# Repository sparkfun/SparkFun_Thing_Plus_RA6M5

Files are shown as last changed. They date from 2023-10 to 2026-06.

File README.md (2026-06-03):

SparkFun Thing Plus - RA6M5
========================================

SparkFun Thing Plus - RA6M5 (https://www.sparkfun.com/products/24243)

[*SparkFun Thing Plus - RA6M5 (WRL-24243)*](https://www.sparkfun.com/products/24243)

Clocking in at 200MHz, the RA6M5 is a high-performance microcontroller from [Renesas](https://www.renesas.com/) that is perfect for real-time applications. The [SparkFun Thing Plus - RA6M5](https://www.sparkfun.com/products/24243), is our latest [Thing Plus board](https://www.sparkfun.com/thing_plus) featuring the standard Qwiic connector, JST LiPo battery connector, 21 GPIO pins broken out in a Feather footprint, and status indicator LEDs. At the core is the RA6M5 microcontroller, a low-power Arm^®^ Cortex^®^-M33 processor with an available 512kB of SRAM and 2MB of Flash and an extensive list of peripheral capabilities. Additionally, we have included 16MB of QSPI Flash and an SD card slot on the board, so users won't have to worry about running out of memory space or data storage options.

The SparkFun RA6M5 Thing Plus also features Bluetooth® Low Energy connectivity, thanks to the provided DA14531MOD module *(also from Renesas)*. When actively transmitting, the DA14531MOD sips a mere 4mA and is capable of operating from a small coin-cell battery. The firmware provided on the module features Renesas' [SmartBond™ - CodeLess™ AT command](https://lpccs-docs.renesas.com/UM-140-DA145x-CodeLess/index.html) set. Therefore, users only need to send AT commands to configure a Bluetooth connection; without the need to reprogram the module.

**Note:**

- While the Thing Plus - RA6M5 does include some 5V tolerant pins, it is primarily a **3.3V** *logic-level* board.
- While the full capabilities of the RA6M5 support a broad range of features, only a limited set may be implemented, by default, in the [Renesas-Arduino core](https://github.com/arduino/ArduinoCore-renesas). However, the capabilities of the Thing Plus - RA6M5 should be comparable to the [Arduino Portenta C33](https://store.arduino.cc/collections/portenta-family/products/portenta-c33); with the exclusion of WiFi connectivity.

Documentation
--------------

* **[Hookup Guide (mkdocs)](http://docs.sparkfun.com/SparkFun_Thing_Plus_RA6M5/)** - The hookup guide for the Thing Plus - RA6M5 hosted by GitHub pages.<br>
   
* [SparkFun Graphical Datasheets](https://github.com/sparkfun/Graphical_Datasheets) - Graphical Datasheets for various SparkFun products.

*Need to download or print our hookup guide?*

* [Print *(Print to PDF)* from Single-Page View](http://docs.sparkfun.com/SparkFun_Thing_Plus_RA6M5/print_view)

Repository Contents
-------------------

* **[/docs](/docs/)** - Online documentation files
    * [assets](/docs/assets/) - Assets files
        * [board_files](/docs/assets/board_files/) - Files for the product design
            * [Eagle design files](/docs/assets/board_files/eagle_files.zip) (.zip)
            * [Schematic](/docs/assets/board_files/schematic.pdf) (.pdf)
            * [Dimensions](/docs/assets/board_files/dimensions.pdf) (.pdf)
            * [Graphical Datasheet](/docs/assets/board_files/graphical_datasheet.pdf) (.pdf)
        * [component_documentation](/docs/assets/component_documentation/) - Datasheets for hardware components
        * [img/hookup_guide/](/docs/assets/img/hookup_guide/) - Images for hookup guide documentation
* **[/Hardware](/Hardware/)** - Eagle design files (.brd, .sch)
  * **[/Production](/Production/)** - Production files

Product Variants
----------------

* [WRL-24243](https://www.sparkfun.com/products/24243)- v1.0, Initial Release

Version History
---------------

* [v10](https://github.com/sparkfun/SparkFun_Thing_Plus_RA6M5/releases/tag/v10) - Initial Release

License Information
-------------------

This product is ***open source***!

Please review the [`LICENSE.md`](./LICENSE.md) file for license information.

If you have any questions or concerns about licensing, please contact technical support on our [SparkFun forums](https://forum.sparkfun.com/viewforum.php?f=152).

Distributed as-is; no warranty is given.

- Your friends at SparkFun.

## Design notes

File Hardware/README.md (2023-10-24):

SparkFun <PRODUCT NAME> Design Files
=====================================

The .sch and .brd files hare are Eagle CAD schematic and PCB design files from SparkFun Electronics.
A freeware version of Autodesk Eagle can be found [here](https://www.autodesk.com/products/eagle/free-download).

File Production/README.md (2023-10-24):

SparkFun <PRODUCT NAME> Production Files
=========================================

These are the production files SparkFun uses for printing PCBs.

License Information
-------------------
This product is open source! 

The hardware is released under [Creative Commons ShareAlike 4.0 International](https://creativecommons.org/licenses/by-sa/4.0/).

Please use, reuse, and modify these files as you see fit. Please maintain attribution to SparkFun Electronics and release anything derivative under the same license.

Distributed as-is; no warranty is given.

- Your friends at SparkFun.

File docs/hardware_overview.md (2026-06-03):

---
icon: material/cog
---

## Dimensions

The circuit board dimensions are illustrated in the drawing below; the measurements are in inches.

<figure markdown>
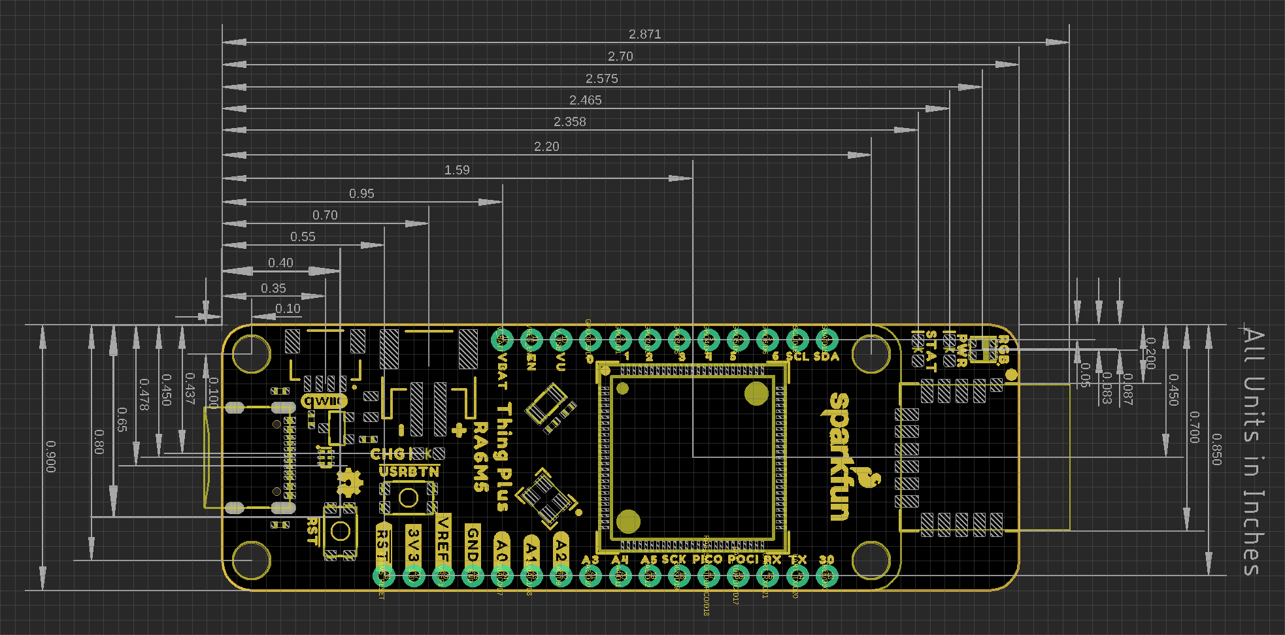
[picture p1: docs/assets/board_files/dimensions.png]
Board Dimensions

<figcaption markdown>
[Dimensions (PDF)](./assets/board_files/dimensions.pdf) of the RA6M5 Thing Plus, in inches.
</figcaption>
</figure>

??? tip "Need more measurements?"
	For more information about the board's dimensions, users can download the [**Eagle files**](./assets/board_files/eagle_files.zip) for the board. These files can be opened in Eagle and additional measurements can be made with the dimensions tool.

	??? info ":octicons-download-16:{ .heart } Eagle - Free Download!"
		Eagle is a [CAD]("computer-aided design") program for electronics that is free to use for hobbyists and students. However, it does require an account registration to utilize the software.

		<article style="text-align: center;" markdown>
		[Download from<br>:autodesk-primary:{ .autodesk }](https://www.autodesk.com/products/eagle/free-download "Go to downloads page"){ .md-button .md-button--primary width="200px" }
		</article>

	??? info ":straight_ruler: Dimensions Tool"
		This video from Autodesk demonstrates how to utilize the dimensions tool in Eagle, to include additional measurements:

		<article style="text-align: center;" markdown>

		<div class="video">
		<iframe src="https://www.youtube.com/embed/dZLNd1FtNB8" title="EAGLE Dimension Tool" frameborder="0" allow="accelerometer; autoplay; clipboard-write; encrypted-media; gyroscope; picture-in-picture" allowfullscreen></iframe>

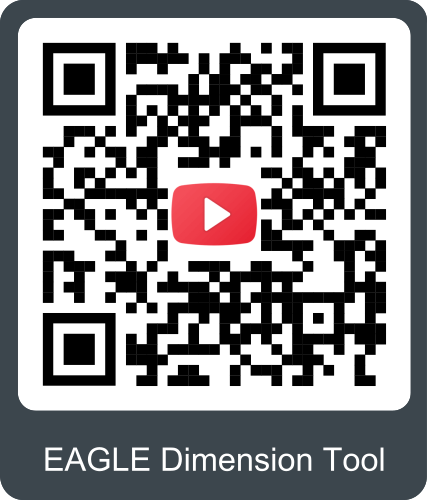
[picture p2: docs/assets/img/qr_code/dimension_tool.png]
QR code to instructional video
		
		</div>

		</article>

## USB Connector
The USB-C connector is used to provide power and program the board. For most users, it will also be the primary programming interface for the RA6M5 Thing Plus.

<figure markdown>
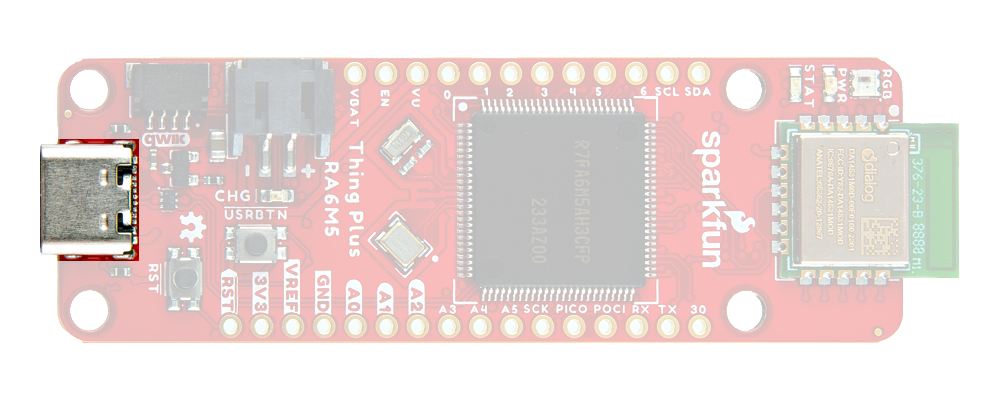
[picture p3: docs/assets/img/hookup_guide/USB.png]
USB-C Connectors

<figcaption markdown>USB-C connector on the RA6M5 Thing Plus.</figcaption>
</figure>

## Power
The RA6M5 Thing Plus only requires **3.3V** to power the board. However, the simplest method to power the board is through the USB-C connector. Alternatively, the `3V3`, `VBAT`, and `VUSB` pins can also be used to supply power to the board.

<div class="grid cards desc" markdown>

<div markdown>

<figure markdown>
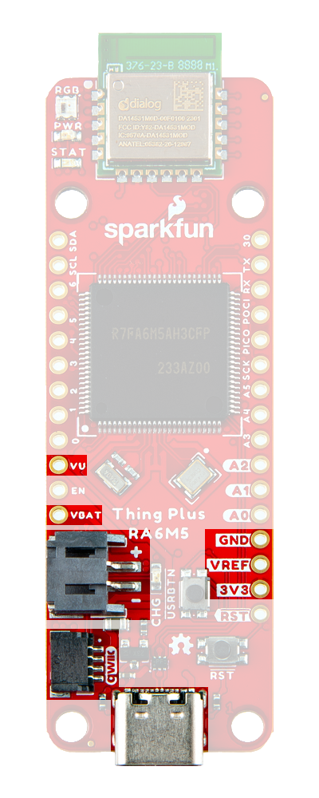
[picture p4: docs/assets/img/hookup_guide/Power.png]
Power connections

<figcaption markdown>Power connections on the RA6M5 Thing Plus PCB.</figcaption>
</figure>

</div>

<div markdown>

<article style="text-align: center;" markdown>

```mermaid

flowchart LR
	A[USB-C] === B(("`**VUSB**`")) ===> |VUSB > VBAT| Switch;

	subgraph Battery Charger
		direction LR
		C[MCP73831] -.-> D[LiPo Battery];
	end

	subgraph Switch
		F[LM66200];
	end

	B ==> C;
	D === E(("`**VBAT**`")) == VBAT > VUSB ==> Switch;

	F ===	H[RT9080] ==> I(("`**3V3**`"));
	F === G[RT9080] ==> J(("`**VREF**`"));

	click B "#vusb"
	click C "#charging-circuit"
	click E "#vbat"
	click F "#power-control"
	click J "#vref"
	click I "#3v3"
```

</article>

Below, is a summary of the power circuitry for this board:

=== ":material-power: `3V3`"
	* Primary power for the RA6M5 Thing Plus
		* Powers the RA6M5 module, DA14531MOD, QSPI flash, &micro;SD card slot, Qwiic connector, WS2812 RGB LED, and power LED
	* A regulated **3.3V** is provided by an [RT9080](./assets/component_documentation/RT9080.pdf) LDO from `VUSB` or `VBAT`
		* The output voltage from the RT9080 is controlled by the `EN` pin on the board
		* The RT9080 can source up to **600mA** of current, which is only limited by the power source from the LM66200 switch
			* The power source from the LM66200 is automatically switched between `VUSB` or `VBAT`, based on which has the greater voltage
	* As an input, it requires a **regulated 3.3V** to avoid contention with the LDO regulator

	!!! info "<span style="font-weight: 400;">The input voltage range for the RT9080 is 1.2-5.5V</span>"

=== ":material-usb-port: `VUSB`"
	* Usually powered through the USB-C connector *(**5V**)*
	* Input voltage range: **3.75 - 5V**
		* The maximum voltage is limited by the ideal diode switch at **5.5V** *(1.6-5.5V)*
		* The minimum voltage is limited by the charge controller at **3.75V** *(3.75-6V)*
	* Primary power source for the [RT9080 LDOs](./assets/component_documentation/RT9080.pdf) when `VUSB` > `VBAT`; via the LM66200 ideal diode switch
	* Powers the [MCP73831](./assets/component_documentation/MCP73831.pdf) linear charge management controller
		* Provides a **213mA** *(max)* rate of charge to a connected battery
=== ":material-battery-charging: `VBAT`"
	* The voltage from the JST battery connector; is meant for single-cell LiPo batteries
		* A connected battery will be charged by the [MCP73831 charge controller](./assets/component_documentation/MCP73831.pdf), when sufficient power is provided from `VUSB`
	* Primary power source for the  [RT9080 LDOs](./assets/component_documentation/RT9080.pdf) when `VBAT` > `VUSB`; via the LM66200 ideal diode switch
	* A battery's charge can be monitored through the [MAX17048](./assets/component_documentation/MAX17048.pdf) fuel gauge
=== ":material-sine-wave: :material-gauge: `VREF`"
	* The analog reference voltage for the RA6M5 module's ADC and DAC channels
		* Provided by a [RT9080](./assets/component_documentation/RT9080.pdf) LDO regulator, separate from one providing the `3V3` power supply

	!!! info "<span style="font-weight: 400;">The input voltage range for the RT9080 is 1.2-5.5V</span>"

=== ":material-format-line-style: `GND`"
	* The common ground or the 0V reference for the voltage supplies
=== ":material-connection: Qwiic Connector"
	* The 4-pin JST connector provides a regulated 3.3V voltage to peripheral Qwiic devices from `3V3`

</div>

</div>

??? info "Detailed Diagram"

	<article style="text-align: center;" markdown>
	
	```mermaid
	
	flowchart LR
		D === E(("`**VBAT**`")) == VBAT > VUSB ==> Switch;
		A[USB-C] === B(("`**VUSB**`")) == VUSB > VBAT ==> Switch;
		C --- T[CHG LED];
	
	subgraph Battery Charger
			C[MCP73831] -.-> D[LiPo<br>3.5-4.2V]
		end
	
		subgraph Switch
			S[LM66200];
			S === I[RT9080] & H[RT9080];
		end
	
		subgraph Powered_Components
			L[PWR LED];
			M[RA6M5] --- N[DA14531MOD];
			M --- O[QSPI Flash];
			M --- P[SD Card];
			M --- Q[WS2812 LED];
			M --- I2C;
			subgraph I2C
				R[Qwiic Connector];
				F[MAX17048];
			end
		end
	
		B ==> C;
		B ====> T;
		I --- U(("`**EN**`"));
		I ==> K(("`**3V3**`")) === Powered_Components;
		H ==> J(("`**VREF**`")) --> M;
		H --- W(("`**D37**`")) --- M;
		D ------ F;
		Switch --- V(("`**D38**`")) --- M;
	```

	</article>

*For more details, users can reference the [schematic](./assets/board_files/schematic.pdf) and the datasheets of the individual components in the power circuitry.*

### Power Status&nbsp; LED
The red, `PWR` LED will light up once **3.3V** is supplied to the board; however, for most users, it will light up when **5V** is supplied through the USB connection or when a LiPo battery is connected to the JST connector.

<figure markdown>
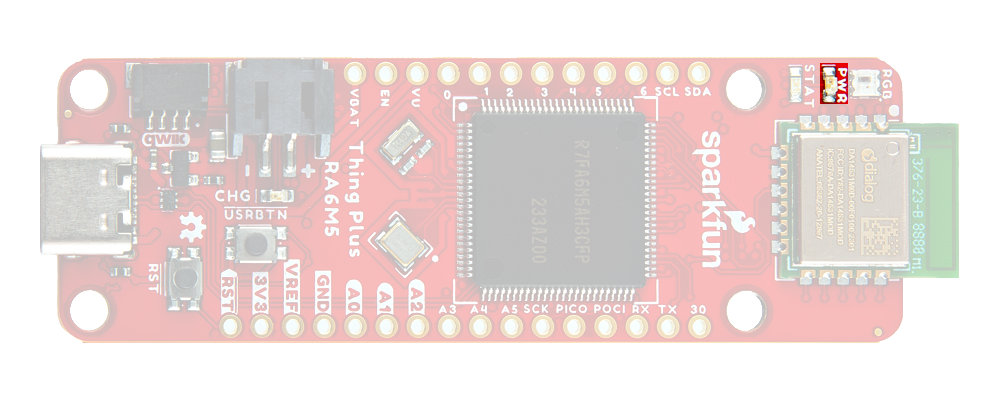
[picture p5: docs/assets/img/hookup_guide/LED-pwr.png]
Power LED

<figcaption markdown>The `PWR` status LED indicator on the RA6M5 Thing Plus.</figcaption>
</figure>

### Charging Circuit
The charging circuit utilizes the [MCP73831 linear charge management controller](./assets/component_documentation/MCP73831.pdf) from [Microchip Technologies](https://www.microchip.com/), which is powered by the USB-C connector or `VUSB`. The controller provides a **213mA** charge rate for a LiPo battery connected to the JST connector. Active charging is indicated by the yellow, `CHG` LED. If the charge controller is shut down or charging is complete, the `CHG` LED will turn off. The board also includes a [MAX17048 fuel gauge](./assets/component_documentation/MAX17048.pdf) from [Analog Devices](https://www.analog.com/) to monitor the charge left on the battery.

<article style="text-align: center;" markdown>

```mermaid

flowchart LR
	A[USB-C] === B(("`**VUSB**`")) ==> C & G;
	D ===> E(("`**VBAT**`"));
	D --- F[MAX17048] === H(("`**3V3**`"));
	G[CHG LED] --- C[MCP73831];

	subgraph Battery Charger
		C -.-> |213mA| D[LiPo<br>3.5-4.2V];
	end
```

</article>

<figure markdown>
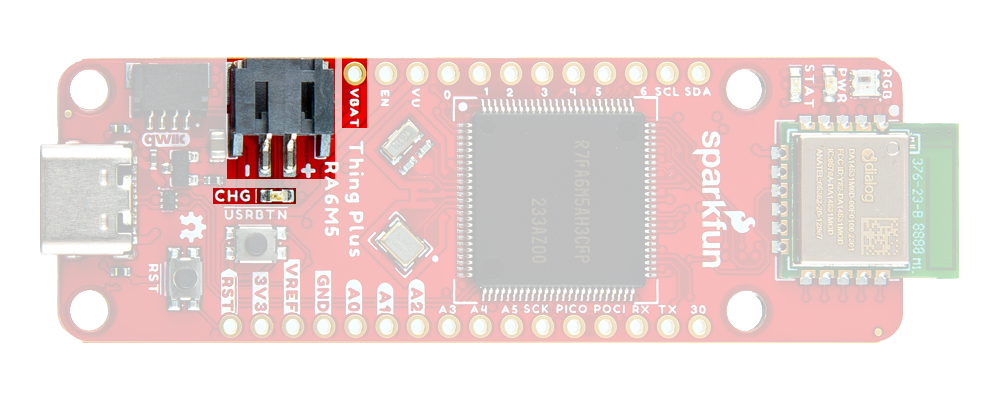
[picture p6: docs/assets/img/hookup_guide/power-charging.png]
Battery connection and charge indicator

<figcaption markdown>The `CHG` status LED and JST connector for the battery on the RA6M5 Thing Plus.</figcaption>
</figure>

*For more details, please refer to the [MCP73831](./assets/component_documentation/MCP73831.pdf) and [MAX17048](./assets/component_documentation/MAX17048.pdf) datasheets, [schematic](./assets/board_files/schematic.pdf), and the [**Status LEDs**](#status-leds) and [**Battery Fuel Gauge**](#battery-fuel-gauge) sections below.*

### Power Control
The primary power source for the [RT9080 LDO regulators](./assets/component_documentation/RT9080.pdf) is automatically switched between `VUSB` and `VBAT` by the [LM66200 ideal diode switch](./assets/component_documentation/LM66200.pdf); based on their voltage levels. This will be indicated by the `ST` pin of the LM66200, which is connected to the `P001` GPIO *(`D38`)* of the RA6M5. A **`LOW`** state will indicate that power is being supplied from `VUSB` *(or the USB-C connector)*; while a **`HIGH`** state will indicate power is being drawn from `VBAT` *(or the battery JST connector)*.

<article style="text-align: center;" markdown>

```mermaid

flowchart LR
	A[USB-C] === B(("`**VUSB**`")) == VUSB > VBAT ==> Switch;
	U(("`**D38**`")) --- Switch;
	D[LiPo] === E(("`**VBAT**`")) == VBAT > VUSB ==> Switch;

	subgraph Switch
		S[LM66200];
	end

	S === H[RT9080] ===> J(("`**3V3**`"));
	H --- T(("`**EN**`"));
	I --- V(("`**D37**`"));
	S === I[RT9080] ===> K(("`**VREF**`"));
```

</article>

The **3.3V** regulated output from the primary RT9080 is enabled by default and controlled by the `EN` pin on the board. Meanwhile, the voltage output from the RT9080 for the analog reference voltage *(`VREF`)* of the RA6M5 is controlled by its `P500` GPIO *(`D37`)*. Users can disable the 3.3V power output of either of the RT9080 LDO regulators, by setting the associated control pin **LOW**.

<figure markdown>
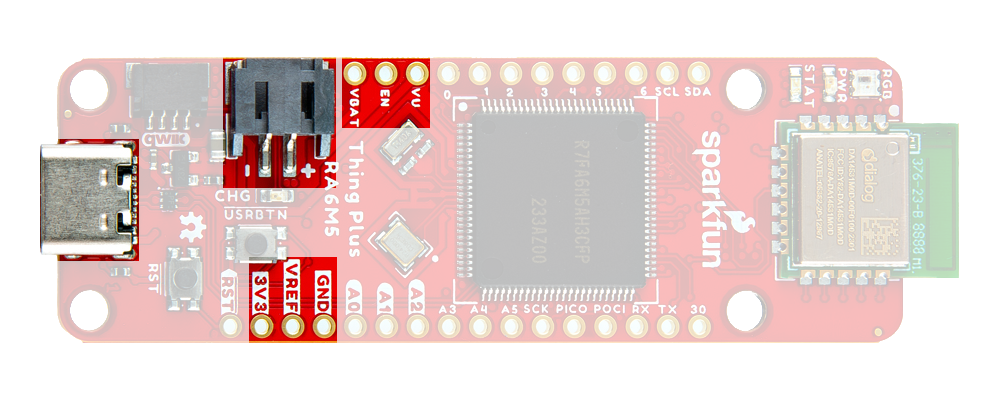
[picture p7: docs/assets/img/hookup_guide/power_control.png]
Power control

<figcaption markdown>The power inputs/outputs and `EN` pin on the RA6M5 Thing Plus.</figcaption>
</figure>

*For more details, please refer to the [LM66200 datasheet](./assets/component_documentation/LM66200.pdf), [RT9080 datasheet](./assets/component_documentation/RT9080.pdf), and [schematic](./assets/board_files/schematic.pdf).*

<!-- Incomplete data
### Current Consumption
According to the specifications, the RA6M5 draws about **### mA** on average. With the BLE example in this tutorial, have measured it to average around **### mA** and peak at *### mA* while active. The table below summarizes the approximate current draw of the [RA6M5 Thing Plus](https://www.sparkfun.com/products/24243) for various cases and conditions. *(All current measurements were profiled with the [Nordic Power Profiler Kit II](https://www.nordicsemi.com/Products/Development-hardware/Power-Profiler-Kit-2).)*

<table style="text-align: center;" markdown>
<tbody>
	<tr>
		<th rowspan="2" style="vertical-align:middle; text-align:center">Operation</th>
		<th colspan="4" style="text-align:center">Avg. Current Draw</th>
	</tr>
	<tr>
		<td style="text-align:center">
			LiPo: <b>3.5V</b><br>
			<i>(Low < 5%)</i>
		</td>
		<td style="text-align:center">
			LiPo: <b>3.7V</b><br>
			<i>(~15%)</i>
		</td>
		<td style="text-align:center">
			LiPo: <b>4.2V</b><br>
			<i>(~100%)</i>
		</td>
		<td style="text-align:center; vertical-align:middle">
			USB-C: <b>5V</b><br>
			<i>(No Battery)</i>
		</td>
	</tr>
	<tr>
		<th style="vertical-align:middle">Idle (Blank Code)</th>
		<td style="vertical-align:middle; text-align:center;">
			63 mA<br>
			<i>86 mA (peak)</i>
		</td>
		<td style="vertical-align:middle; text-align:center;">
			63.5 mA<br>
			<i>89 mA (peak)</i>
		</td>
		<td style="vertical-align:middle; text-align:center;">
			64 mA<br>
			<i>88.6 mA (peak)</i>
		</td>
		<td style="vertical-align:middle; text-align:center;">
			67 mA<br>
			<i>89.9 mA (peak)</i>
		</td>
	</tr>
	<tr>
		<th style="vertical-align:middle">Idle: USB + Battery Power</th>
		<td style="vertical-align:middle; text-align:center;">
			--
		</td>
		<td style="vertical-align:middle; text-align:center;">
			--
		</td>
		<td style="vertical-align:middle; text-align:center;">
			90.5 &micro;A<br>
			<i>721 &micro;A (peak)</i>
		</td>
		<td style="vertical-align:middle; text-align:center;">
			N/A
		</td>
	</tr>
	<tr>
		<th style="vertical-align:middle">
			Idle: Battery Charging<br>
			<i>(Current from USB-C)</i>
		</th>
		<td style="vertical-align:middle; text-align:center;">
			395 mA<br>
			<i>420 mA (peak)</i>
		</td>
		<td style="vertical-align:middle; text-align:center;">
			590 mA<br>
			<i>600 mA (peak)</i>
		</td>
		<td style="vertical-align:middle; text-align:center;">
			&gt; 110 mA<br>
			<i>(before shutdown)</i>
		</td>
		<td style="vertical-align:middle; text-align:center;">
			N/A
		</td>
	</tr>
	<tr>
		<th style="vertical-align:middle">RGB <i>(White @ 100%)</i></th>
		<td style="vertical-align:middle; text-align:center;">
			78.4 mA<br>
			<i>105.9 mA (peak)</i>
		</td>
		<td style="vertical-align:middle; text-align:center;">
			79 mA<br>
			<i>106.8 mA (peak)</i>
		</td>
		<td style="vertical-align:middle; text-align:center;">
			79.9 mA<br>
			<i>105.3 mA (peak)</i>
		</td>
		<td style="vertical-align:middle; text-align:center;">
			82.5 mA<br>
			<i>108.2 mA (peak)</i>
		</td>
	</tr>
	<tr>
		<th style="vertical-align:middle">
			WiFi Example<br>
			<i>(Transceiving)</i>
		</th>
		<td style="vertical-align:middle; text-align:center;">
			135 mA<br>
			<i>295 mA (peak)</i>
		</td>
		<td style="vertical-align:middle; text-align:center;">
			137 mA<br>
			<i>310 mA (peak)</i>
		</td>
		<td style="vertical-align:middle; text-align:center;">
			137 mA<br>
			<i>307 mA (peak)</i>
		</td>
		<td style="vertical-align:middle; text-align:center;">
			140 mA<br>
			<i>300 mA (peak)</i>
		</td>
	</tr>
	<tr>
		<th style="vertical-align:middle">
			<a href="https://github.com/espressif/arduino-esp32/blob/master/libraries/ESP32/examples/DeepSleep/TouchWakeUp/TouchWakeUp.ino">Deep Sleep Example</a><br>
			<i>(MCU Inactive)</i>
		</th>
		<td style="vertical-align:middle; text-align:center;">
			2.5 mA<br>
			<i>2.95 mA (peak)</i>
		</td>
		<td style="vertical-align:middle; text-align:center;">
			2.5 mA<br>
			<i>3 mA (peak)</i>
		</td>
		<td style="vertical-align:middle; text-align:center;">
			2.55 mA<br>
			<i>3 mA (peak)</i>
		</td>
		<td style="vertical-align:middle; text-align:center;">
			2.85 mA<br>
			<i>3.3 mA (peak)</i>
		</td>
	</tr>
	<tr>
		<th style="vertical-align:middle">
			<a href="https://github.com/espressif/arduino-esp32/blob/master/libraries/ESP32/examples/DeepSleep/TouchWakeUp/TouchWakeUp.ino">Deep Sleep Example</a><br>
			<i>(MCU Inactive + Jumpers Cut)</i>
		</th>
		<td style="vertical-align:middle; text-align:center;">
			842 &micro;A<br>
			<i>1.24 mA (peak)</i>
		</td>
		<td style="vertical-align:middle; text-align:center;">
			848 &micro;A<br>
			<i>1.23 mA (peak)</i>
		</td>
		<td style="vertical-align:middle; text-align:center;">
			866 &micro;A<br>
			<i>1.24 mA (peak)</i>
		</td>
		<td style="vertical-align:middle; text-align:center;">
			1.19 mA<br>
			<i>1.58 mA (peak)</i>
		</td>
	</tr>
</tbody>
</table>

It is possible for users to reach sub-mA power consumption levels with the deep sleep power modes. Using the [`TimerWakeUp` Deep Sleep example code](https://github.com/espressif/arduino-esp32/blob/master/libraries/ESP32/examples/DeepSleep/TimerWakeUp/TimerWakeUp.ino), the LED jumpers cut, and powering the board through the LiPo battery connection we measured a power consumption of **845 &micro;A** *(990 &micro;A peak)* @ **3.7V** while the MCU was inactive.

<figure markdown>
[![Deep Sleep Power Consumption Profile](./assets/img/hookup_guide/measurement-ulp-from_batt.png){ width="400" }](./assets/img/hookup_guide/measurement-ulp-from_batt.png "Click to enlarge")
<figcaption markdown>The current measurement from `VBAT` at **3.7V** during deep sleep.</figcaption>
</figure>

 -->

## :fontawesome-solid-microchip:&nbsp;RA6M5 Microcontroller
The brains of the board is the [RA6M5 microcontroller](https://www.renesas.com/us/en/document/dst/ra6m5-group-datasheet?r=1493931) from [Renesas](https://www.renesas.com/), a low-power Arm^®^ Cortex^®^-M33 processor with a clock speed up to 200Mhz, 512kB of SRAM, and 2MB of flash memory. This high-performance microcontroller features an extensive list of peripheral capabilities and is perfect for real-time applications.

<div class="grid cards col-3" markdown>

<div markdown>

<figure markdown>
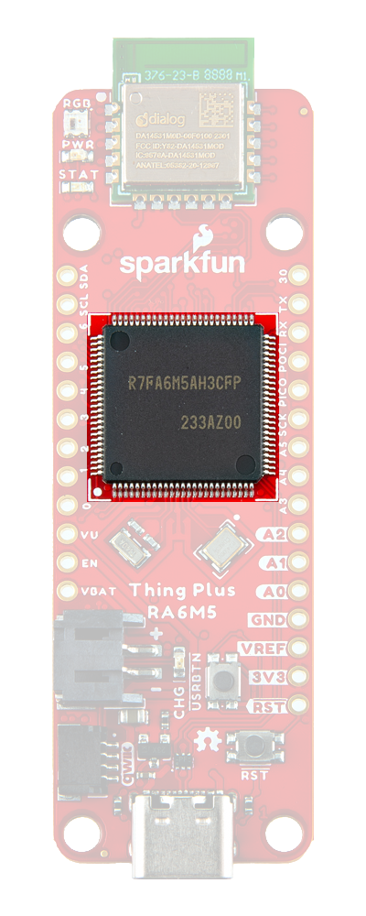
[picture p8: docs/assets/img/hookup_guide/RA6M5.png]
RA6M5 Microcontroller

<figcaption markdown>The RA6M5 microcontroller on the RA6M5 Thing Plus.</figcaption>
</figure>

</div>

<div markdown>

* Arm^®^ Cortex^®^-M33 Core
	* Clock Frequency: 200MHz
	* Flash Memory: 2MB *(code)*; 8kB *(data)*
	* SRAM: 512kB w/ ECC Support
	* Arm Memory Protection Unit (Arm MPU)
	* Secure Crypto Engine
	* Two Watchdog Timers (WDT)
* Operating Voltage: 3.0V to 3.6V
	* Current Consumption:
		* Maximum: 143mA
		* Normal: 32mA
		* Sleep: 11mA
		* Deep Sleep: 0.9-131&micro;A
* Operating modes:
	* Single-chip or SCI/USB boot
* Operating Temperature: -40 to 85 &deg;C
* 75 GPIO Pins
* RTC with Calendar
* CRC Calculator
* Internal Temperature Sensor

</div>

<div markdown>

**Peripherals**

* 12-bit ADC (x6)
* 12-bit DAC (x2)
* 32-bit PWM Channels (x4)
* 16-bit PWM Channels (x6)
* UART (x10)
* I^2^C Bus (x3)
* SPI Bus (x2)
* QSPI (x1)
* SD/MMC Host Interface

{--

* OSPI (x1)
* CAN Interface
* USB 2.0 (Full/High Speed)
* Ethernet MAC/DMA Controller
* Serial Sound Interface Enhanced
* Consumer Electronics Control
* Capacitive Touch Sensing

--}

!!! warning "Note"
	Users should be aware that not all of the features, listed above, will be available in the Arduino IDE.

</div>

</div>

??? success "DFU Mode"
	If users are having issues uploading code to the board, the RA6M5 can be manually forced into DFU mode. This issue, often occurs when the USB connection is busy and a reset can't be triggered on the RA6M5, to initialize the upload process. To force the RA6M5 Thing Plus into DFU mode:

	1. Double-tap the ++"RST"++ button
		- The `STAT` LED should be fading in/out very slowly
	1. Users should now, be able to upload a new program
		- It shouldn't be necessary to select a COM port in the Arduino IDE; only the board needs to be selected
	1. Once programming is complete, the MCU should reboot on its own. Otherwise:
		- Press the ++"RST"++ button
		- Power cycle the board

*For more technical specifications for the RA6M5 microcontroller, please refer to the [RA6M5 datasheet](https://www.renesas.com/us/en/document/dst/ra6m5-group-datasheet?r=1493931) and [RA6M5 user manual](https://www.renesas.com/us/en/document/man/ra6m5-group-users-manual-hardware?r=1493931).*

### Debugging Pins
Debug pins are available for the RA6M5, as 0.1" test points on the board. However, the debugging feature is only available through the [Renesas FSP](https://www.renesas.com/us/en/software-tool/flexible-software-package-fsp) *(not covered in this tutorial)*.

<div class="grid" markdown>

<div markdown>

=== "SWD"
	<!--
    <table border="1" style="text-align: center;" markdown>
        <tr markdown>
            <td style="text-align:center" markdown>---</td>
        </tr>
        <tr markdown>
            <td style="text-align:center" markdown>**3.3V**</td>
            <td style="text-align:center" markdown>**SWDIO**</td>
        </tr>
        <tr markdown>
            <td style="text-align:center" markdown>**SWCLK**</td>
            <td style="text-align:center" markdown>**SWO**</td>
        </tr>
        <tr markdown>
            <td style="text-align:center" markdown>**GND**</td>
            <td style="text-align:center" markdown>**RST**</td>
        </tr>
    </table>
	-->

    <table border="1" style="text-align: center;" markdown>
        <tr markdown>
            <td style="text-align:center" markdown>**GND**</td>
            <td style="text-align:center" markdown>**SWCLK**</td>
            <td style="text-align:center" markdown>**3.3V**</td>
            <td style="text-align:center" markdown>**|**</td>
        </tr>
        <tr markdown>
            <td style="text-align:center" markdown>**RST**</td>
            <td style="text-align:center" markdown>**SWO**</td>
            <td style="text-align:center" markdown>**SWDIO**</td>
        </tr>
    </table>

=== "JTAG"
	<!--
    <table border="1" style="text-align: center;" markdown>
        <tr markdown>
            <td style="text-align:center" markdown>---</td>
        </tr>
        <tr markdown>
            <td style="text-align:center" markdown>**3.3V**</td>
            <td style="text-align:center" markdown>**TMS**</td>
        </tr>
        <tr markdown>
            <td style="text-align:center" markdown>**TCK**</td>
            <td style="text-align:center" markdown>**TDO**</td>
        </tr>
        <tr markdown>
            <td style="text-align:center" markdown>**GND**</td>
            <td style="text-align:center" markdown>**RST**</td>
        </tr>
    </table>
	-->

    <table border="1" style="text-align: center;" markdown>
        <tr markdown>
            <td style="text-align:center" markdown>**GND**</td>
            <td style="text-align:center" markdown>**TCK**</td>
            <td style="text-align:center" markdown>**3.3V**</td>
            <td style="text-align:center" markdown>**|**</td>
        </tr>
        <tr markdown>
            <td style="text-align:center" markdown>**RST**</td>
            <td style="text-align:center" markdown>**TDO**</td>
            <td style="text-align:center" markdown>**TMS**</td>
        </tr>
    </table>

!!! info "Pin Connections"
	In case users are interested, these are the pin connections of the debugging test points for the RA6M5. For more details, please reference the [schematic](./assets/board_files/schematic.pdf) and [**Eagle files**](./assets/board_files/eagle_files.zip).

	- `TMS`/`SWDIO`: `P108`
	- `TCK`/`SWCLK`: `P300`
	- `TDO`/`SWO`: `P109`
	- {--`TDI`: `P110` (POCI/`D17`)--} ***(Not a JTAG test point)***

!!! note
	In order to debug the RA6M5, users will need a debug probe. We recommend the [J-Link debug probes from Segger](https://www.segger.com/products/debug-probes/j-link/). However, users should verify the supported devices before purchasing these products; for example, we had a few issues with the [J-Link EDU Mini](https://www.sparkfun.com/products/24078).

</div>

<div markdown>

<figure markdown>
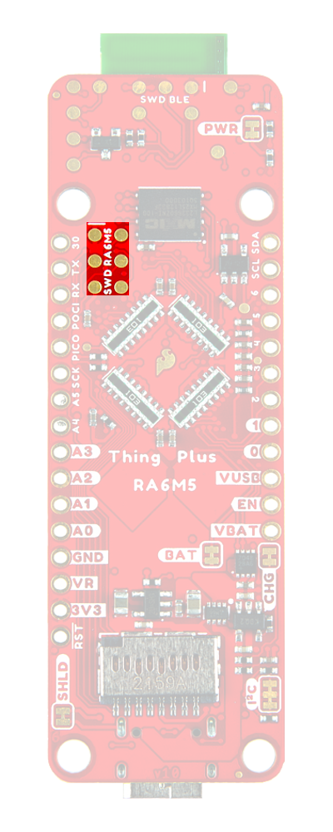
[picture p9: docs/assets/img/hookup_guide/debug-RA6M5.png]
RA6M5 Debug Pins

<figcaption markdown>The debug pins for the RA6M5 microcontroller.</figcaption>
</figure>

</div>

</div>

*For more details, please refer to the [schematic](./assets/board_files/schematic.pdf) and [RA6M5 datasheet](https://www.renesas.com/us/en/document/dst/ra6m5-group-datasheet?r=1493931).*

### Pin Functions
While there are **75 GPIO pins** that are available on the RA6M5, only **44 GPIO pins are utilized** with the RA6M5 Thing Plus. Additionally, of those 44 GPIO, only **21 GPIO pins** are broken out into the PTH breakout pins. The breakout pins are in a Feather form-factor layout with a 0.1" pitch spacing to make them compatible with [standard headers](https://www.sparkfun.com/categories/381) and [Feather shields/*wings*](https://www.sparkfun.com/categories/tags/feather).

Some of the RA6M5's peripheral capabilities may be inaccessible to users with the **available 44 GPIO**. However, any of the available GPIO pins can operate as **digital I/O**; with several of these pins featuring additional peripheral support. The pins utilized by the RA6M5 Thing Plus, along with their capabilities, are summarized in our [graphical datasheet](./assets/board_files/graphical_datasheet.pdf) and detailed in the sections below.

<article style="text-align: center;" markdown>
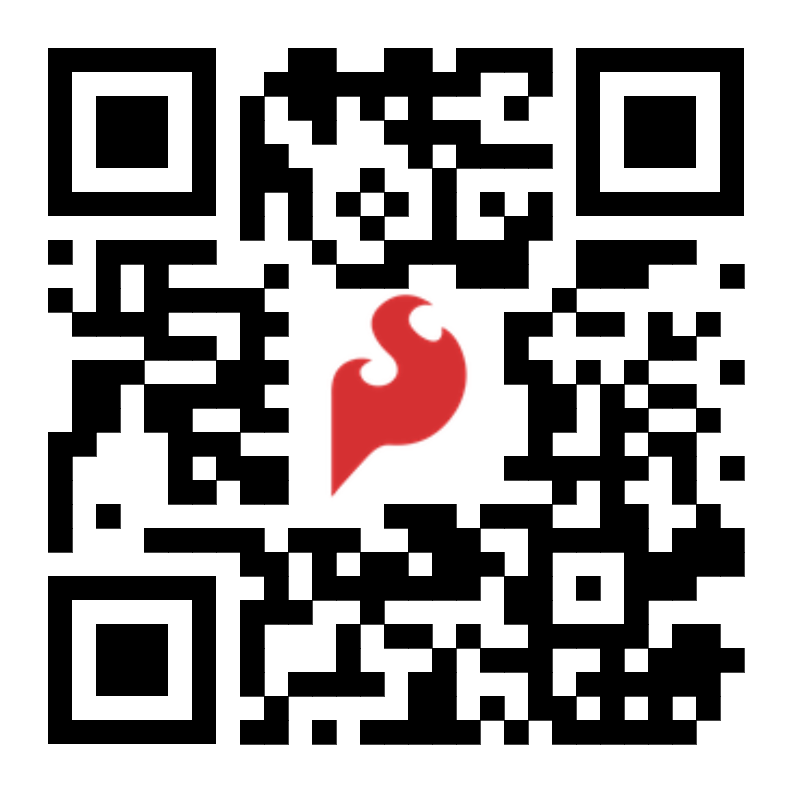
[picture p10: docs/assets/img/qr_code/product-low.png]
QR code to product page
[:material-download:{ .heart }&nbsp;&nbsp;Download the Graphical Datasheet<br>](./assets/board_files/graphical_datasheet.pdf "Click to download the graphical datasheet"){ .md-button .md-button--primary }
</article>

<div class="grid" markdown>

<div markdown>

<figure markdown>
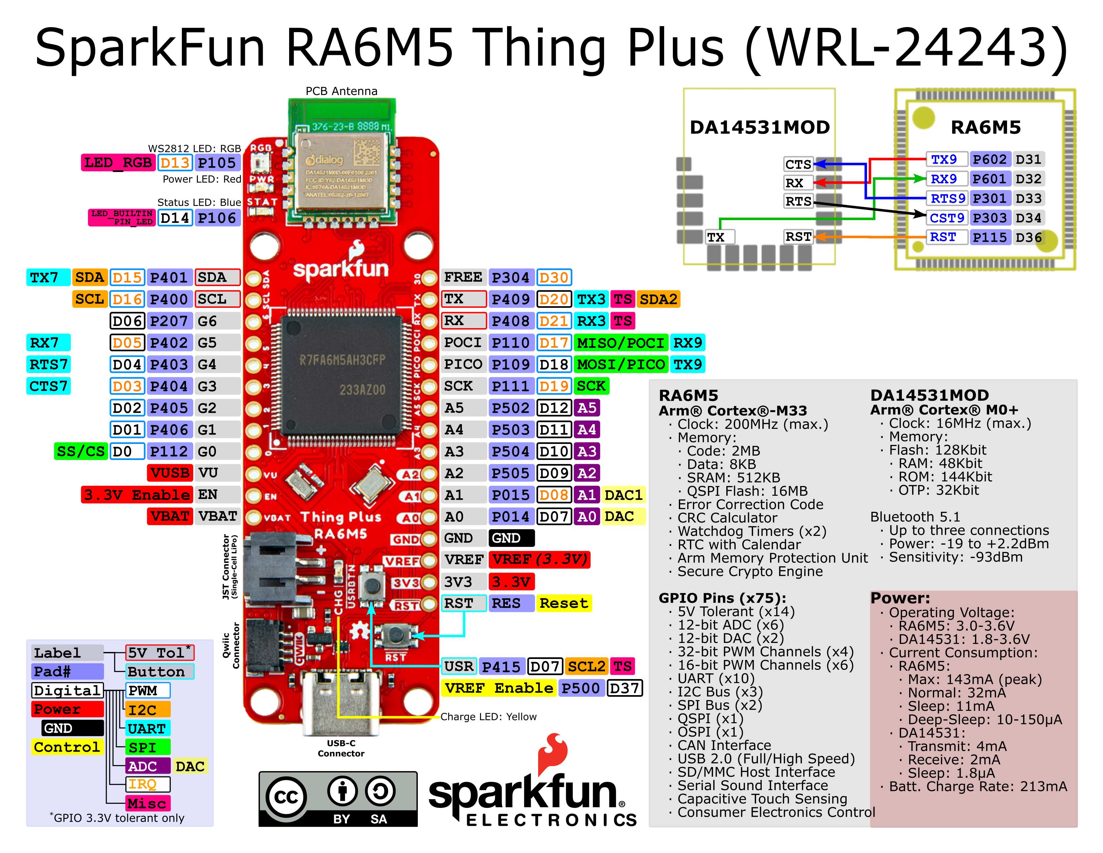
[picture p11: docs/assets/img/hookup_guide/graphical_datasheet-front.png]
Graphical datasheet

</figure>

</div>

<div markdown>

<figure markdown>
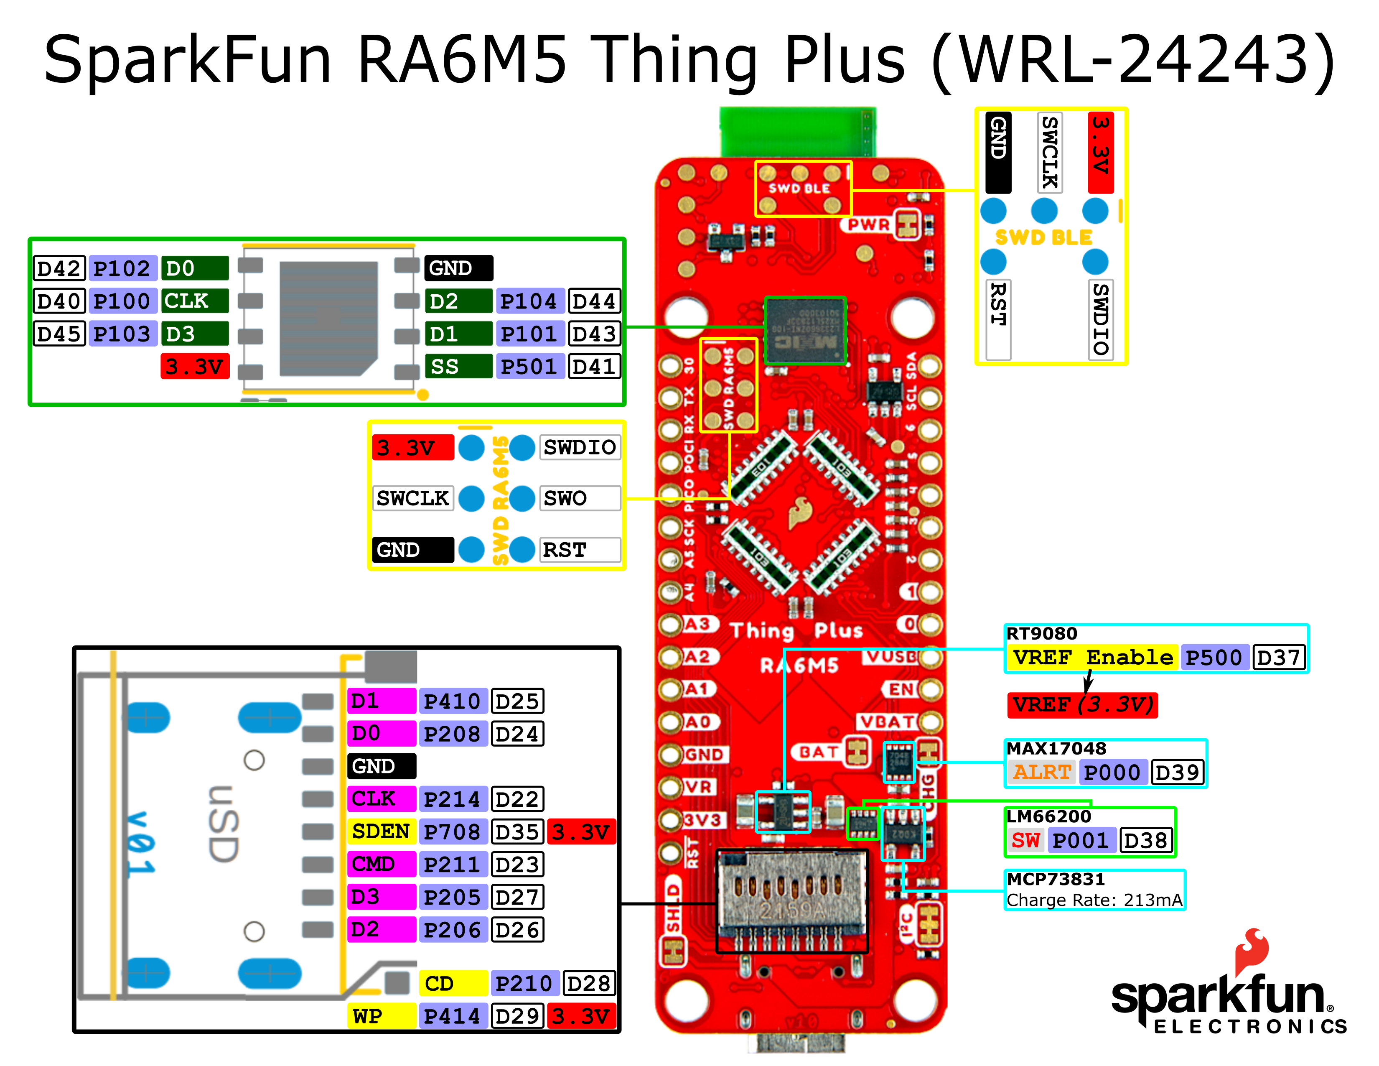
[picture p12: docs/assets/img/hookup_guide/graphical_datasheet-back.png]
Graphical datasheet

</figure>

</div>

</div>

!!! arduino "Board Limitations"
	Users should be aware that some of the features of the RA6M5 may not be available in the Arduino IDE. This is due to either the lack of support in the [Renesas-Arduino core](https://github.com/arduino/ArduinoCore-renesas) and/or pins that are unavailable on the RA6M5 Thing Plus. *For the full capabilities of the RA6M5, the [Renesas FSP](https://www.renesas.com/us/en/software-tool/flexible-software-package-fsp) should be utilized.*

	<div class="grid" markdown>

	<div markdown>

	- Only one I<sup>2</sup>C bus is defined.
	- Only three UART interfaces are defined.
		- `Serial` - UART (USB)
		- `Serial1` - `RX`/`TX` GPIO Pins
		- `Serial2` - DA14531MOD UART
	- Only one SPI bus is defined.

	</div>

	<div markdown>

	!!! warning "Note"
		- All the GPIO on the RA6M5 Thing Plus are :high_voltage: **3.3V** pins
		- While the datasheet specifies there are fourteen 5V-tolerant I/O pins; most of the exposed pins are **not 5V-tolerant**! To interface with higher voltage components, a [**logic-level adapter**](https://learn.sparkfun.com/tutorials/147) should be utilized.

	</div>

	</div>

=== ":material-square-wave: Digital I/O"
	Any GPIO pin on the RA6M5 Thing Plus can operate as a digital I/O *(input or output)*. To access this functionality in the Arduino IDE, users must first declare the pin operation in their `#!cpp setup()` loop, using the [`#!cpp pinMode(pin, mode)` function](https://www.arduino.cc/reference/en/language/functions/digital-io/pinmode/).

	**Input**

	:	If a pin is configured as an `INPUT`, the microcontroller can monitor if the pin's state is **HIGH** or **LOW**. As **Input** pins are **High Impedance**, it takes very little current to move the input pin from one state to another.

		!!! arduino
			In the Arduino IDE, this is accessed through the [`#!cpp digitalRead(pin)` function](https://www.arduino.cc/reference/en/language/functions/digital-io/digitalread/), which returns a `HIGH` or `LOW` value.

	**Output**

	:	If a pin is configured as an `OUTPUT`, the microcontroller can provide a **HIGH** or **LOW** voltage output from the pin. As **Output** pins are **Low Impedance**, they can provide a certain amount of current for other circuits.

		!!! arduino
			In the Arduino IDE, this is accessed through the [`#!cpp digitalWrite(pin, value)` function](https://www.arduino.cc/reference/en/language/functions/digital-io/digitalwrite/) and providing a `HIGH` or `LOW` value.

		!!! warning
			There are electrical limitations to the amount of current that I/O pins can sink or source. For more details, check out the [RA6M5 datasheet](https://www.renesas.com/us/en/document/dst/ra6m5-group-datasheet?r=1493931).

	!!! tip "Tip - Creating a PWM Output"
		A digital output pin can only either be fully on **HIGH** or fully off **LOW**. By turning a digital pin's output, on and off very quickly with precise timings, the average voltage can be controlled and emulate an analog output. This method is called [PWM](https://docs.arduino.cc/learn/microcontrollers/analog-output/).
		
		*Please refer to the [PWM Outputs](#pwm-outputs) tab for more instructions or check out this great [tutorial](https://learn.sparkfun.com/tutorials/pulse-width-modulation) to learn more about pulse width modulation.*

=== ":material-square-wave: PWM Outputs"
	The RA6M5 supports up to **four 32-bit** and **six 16-bit PWM** (Pulse Width Modulation) channels on most of its GPIO pins. A PWM output will produce a square waveform with a variable duty cycle, a ratio of time a signal is **HIGH** for a given wave period. In the Arduino IDE, this feature is accessed using the [`#!cpp analogWrite(pin, value)` function](https://www.arduino.cc/reference/en/language/functions/analog-io/analogwrite/), where the desired duty cycle is specified as an 8-bit `value`.

	$$
	\operatorname{Duty-Cycle}=\frac{value_{\operatorname{(8-bit)}}}{255_{(\operatorname{8-bit})}} = \frac{time_{HIGH}}{time_{Total}}=\frac{t_{HIGH}}{t_{LOW} + t_{HIGH}}
	$$

	<div class="grid" markdown>

	<div markdown>

	<figure markdown>
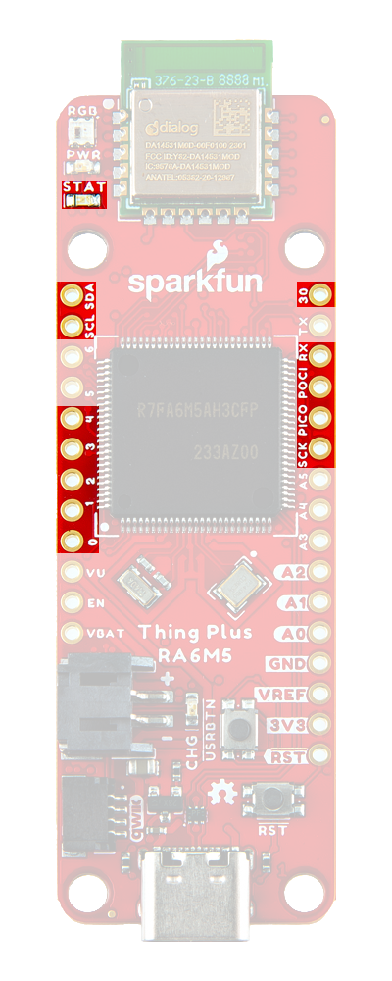
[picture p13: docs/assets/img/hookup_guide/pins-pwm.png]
Annotated image of PWM pins
	
	<figcaption markdown>The GPIO pins that support PWM outputs on the RA6M5 Thing Plus.</figcaption>
	</figure>

	</div>

	<div markdown>

	??? warning "Mean Value &ne; Analog"
		PWM signals are often mistaken for analog signals; however, a PWM output is not a **true** analog signal. These signals can *emulate an analog output*, based on the average voltage output of their square waveform for a specific duration of time.

	!!! arduino
		By default, in the Arduino IDE, `analogWrite()` accepts an 8-bit value. To change the resolution of the PWM signal for the `#!cpp analogWrite()` function, use the [`#!cpp analogWriteResolution(bits)` function](https://www.arduino.cc/reference/en/language/functions/zero-due-mkr-family/analogwriteresolution/).

		*A PWM output is not a true analog signal. For a true analog output, please refer to the [**Analog Outputs** tab](#analog-outputs).*

	!!! tip
		To learn more about pulse width modulation (PWM), check out this great [tutorial](https://learn.sparkfun.com/tutorials/51).

		<div class="grid cards" markdown align="center">

		-   <a href="https://learn.sparkfun.com/tutorials/51">
			<figure markdown>
			Tutorial Thumbnail
			</figure>

			---

			**Pulse Width Modulation**</a>

		</div>

	</div>

	</div>

=== ":material-sine-wave: Analog Inputs"
	The RA6M5 has six **12-bit ADC** channels on its GPIO pins to read analog signals. This functionality is accessed in the Arduino IDE using the [`#!cpp analogRead(pin)` function](https://www.arduino.cc/reference/en/language/functions/analog-io/analogread/). *The available ADC pins are highlighted in the image below.*

	<div class="grid" markdown>

	<div markdown>

	<figure markdown>
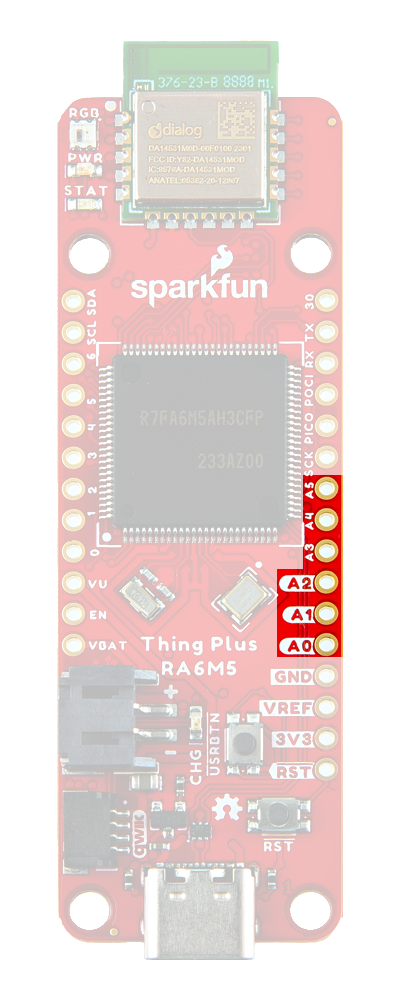
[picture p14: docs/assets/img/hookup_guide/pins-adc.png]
Annotated image of ADC pins
	
	<figcaption markdown>Analog input pins on the RA6M5 Thing Plus.</figcaption>
	</figure>

	</div>

	<div markdown>

	!!! arduino
		In the Arduino IDE, `#!cpp analogRead()` returns a 10-bit value by default. To change the resolution of the value returned by the `#!cpp analogRead()` function, use the [`#!cpp analogReadResolution(bits)` function](https://www.arduino.cc/reference/en/language/functions/zero-due-mkr-family/analogreadresolution/).

	!!! tip
		To learn more about analog vs. digital signals, check out this great [tutorial](https://learn.sparkfun.com/tutorials/35).

		<div class="grid cards" markdown align="center">

		-   <a href="https://learn.sparkfun.com/tutorials/35">
			<figure markdown>
			Tutorial Thumbnail
			</figure>

			---

			**Analog to Digital Conversion**</a>

		</div>

	</div>

	</div>

=== ":material-sine-wave: Analog Outputs"
	The RA6M5 has two **12-bit DAC** channels on its GPIO pins to output analog signals. This feature is accessed in the Arduino IDE using the [`#!cpp AnalogWave` library from the Renesas Arduino core](https://github.com/arduino/ArduinoCore-renesas/tree/main/libraries/AnalogWave). *The available DAC pins are highlighted in the image below.*

	<div class="grid" markdown>

	<div markdown>

	<article style="text-align: center;" markdown>

	| GPIO Pin | DAC Channel |
	| :------: | :---------- |
	| `A0`     | `DAC`       |
	| `A1`     | `DAC1`      |

	</article>

	<figure markdown>
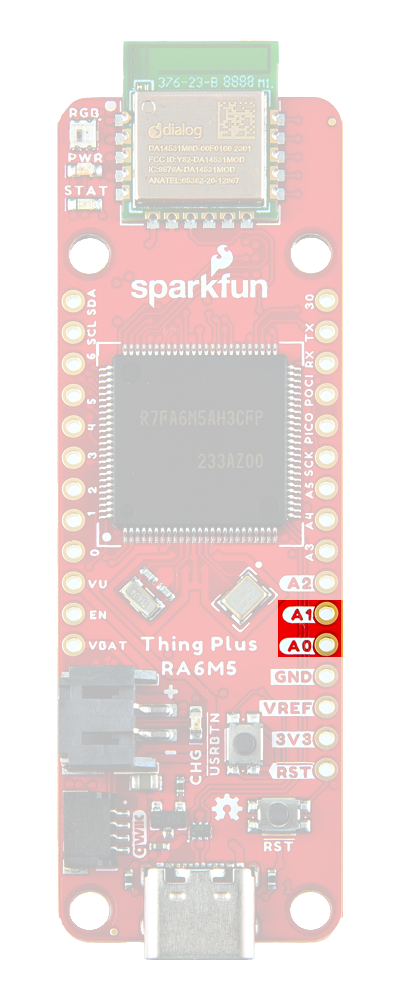
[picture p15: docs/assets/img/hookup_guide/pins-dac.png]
Annotated image of DAC pins
	
	<figcaption markdown>Analog (DAC) output pins on the RA6M5 Thing Plus.</figcaption>
	</figure>

	</div>

	<div markdown>

	!!! arduino
		When implementing the `AnalogWave` library, users will need to link the library and create an instance of the `analogWave` class with a DAC `pin` declared for the output.

		```c++
		#include "analogWave.h" // Include the library for analog waveform generation

		analogWave wave(pin);   // Create an instance of the analogWave class, using a DAC pin
		```

		*For more information, please refer to the [Analog I/O example](../example-analog/#analogwave-library) in this guide.*

	!!! tip
		To learn more about analog vs. digital signals, check out this great [tutorial](https://learn.sparkfun.com/tutorials/89).

		<div class="grid cards" markdown align="center">

		-   <a href="https://learn.sparkfun.com/tutorials/89">
			<figure markdown>
			Tutorial Thumbnail
			</figure>

			---

			**Analog vs. Digital**</a>

		</div>

	</div>

	</div>

=== "Serial Pins"
	The RA6M5 supports up to ten UART ports. However, only the three UART ports are predefined in the Renesas Arduino core. In the Arduino IDE, the [serial communication class](https://www.arduino.cc/reference/en/language/functions/communication/serial/) is used for the USB connection (`#!cpp Serial`), the labeled UART I/O pins on the board (`#!cpp Serial1`), and UART connection to the DA14531MOD (`#!cpp Serial2`).

	<div class="grid" markdown>

	<div markdown>

	<figure markdown>
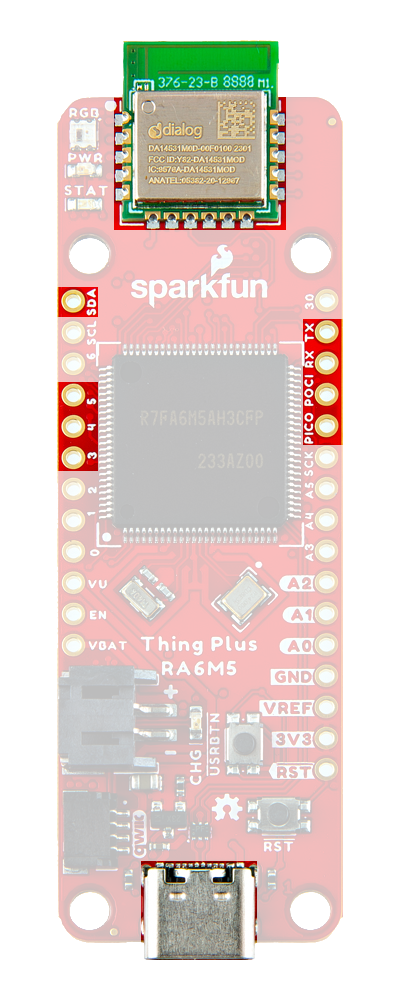
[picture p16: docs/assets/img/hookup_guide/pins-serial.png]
Annotated image of UART connections
	
	<figcaption markdown>UART connections on the RA6M5 Thing Plus.</figcaption>
	</figure>

	</div>

	<div markdown>

	!!! arduino
		By default, in the Arduino IDE, the RA6M5 Thing Plus board definition supports:

		<article style="text-align: center;" markdown>

		| Arduino Object | GPIO Pins   | Connection |
		| :------------- | :---------- | :--------: |
		| `Serial`       |             | **USB**    |
		| `Serial1`      | **RX** - `P408` *(`D21`)*<br>**TX** - `P409` *(`D20`)* | PTH Pins |
		| `Serial2`      | **RX** - `P601` *(`D32`)*<br>**TX** - `P602` *(`D31`)*<br>**RTS** - `P301` *(`D33`)*<br>**CTS** - `P303` *(`D34`)* | **DA14531MOD**<br>*Bluetooth Module* |

		</article>

		To utilize serial communication on other pins, users will need to create a custom serial port object and declare which pins to access.

		??? warning "Shared UART Port"
			Users should be aware that the UART port for pins `D17`/`D18`, **UART9**, is also utilized for communication with the DA14531MOD Bluetooth module. Therefore, if **UART9** is already being utilized for the DA14531MOD; the UART port will be unavailable on pins `D17`/`D18`.

			<article style="text-align: center;" markdown>

			| UART Port | Arduino Object | GPIO Pins   | Connection |
			| :-------: | :------------- | :---------- | :--------: |
			| **USB**   | `Serial`       |             | **USB**    |
			| **UART3** | `Serial1`      | **RX** - `P408` *(`D21`)*<br>**TX** - `P409` *(`D20`)* | PTH Pins |
			| **UART9** | `Serial2`      | **RX** - `P601` *(`D32`)*<br>**TX** - `P602` *(`D31`)*<br>**RTS** - `P301` *(`D33`)*<br>**CTS** - `P303` *(`D34`)* | **DA14531MOD**<br>*Bluetooth Module* |
			| **UART9** |                | **RX** - `P110` *(`D17`)*<br>**TX** - `P109` *(`D18`)* | PTH Pins |
			| **UART7** |                | **RX** - `P402` *(`D05`)*<br>**TX** - `P401` *(`D15`)*<br>**RTS** - `P403` *(`D04`)*<br>**CTS** - `P404` *(`D03`)*  | PTH Pins |

			</article>

	!!! tip
		To learn more about serial communication, check out this great [tutorial](https://learn.sparkfun.com/tutorials/8).

		<div class="grid cards" markdown align="center">

		-   <a href="https://learn.sparkfun.com/tutorials/8">
			<figure markdown>
			Tutorial Thumbnail
			</figure>

			---

			**Serial Communication**</a>

		</div>

	</div>

	</div>

=== "SPI Pins"
	The RA6M5 supports up to two SPI buses. However, only a single SPI port is defined in the Renesas Arduino core. In the Arduino IDE, the [SPI communication class](https://www.arduino.cc/en/reference/SPI) is configured to utilize pins SCK - `P111`/`D19`, POCI - `P110`/`D17`, PICO - `P109`/`D18`, and `P112`/`D0` for its chip select.

	??? note "New Nomenclature"
		To comply with the latest [OSHW](https://www.oshwa.org/) design practices, we have [adopted the new SPI signal nomenclature](https://www.sparkfun.com/spi_signal_names) (`SDO`/`SDI` and `PICO`/`POCI`). The terms **Master** and **Slave** are now referred to as **Controller** and **Peripheral**. The `MOSI` signal on a controller has been replaced with `SDO` or `PICO`. Please refer to this [announcement on the decision to deprecate the `MOSI`/`MISO` terminology and transition to the `SDO`/`SDI` naming convention](https://www.oshwa.org/a-resolution-to-redefine-spi-signal-names).

	<div class="grid" markdown>

	<div markdown>

	<figure markdown>
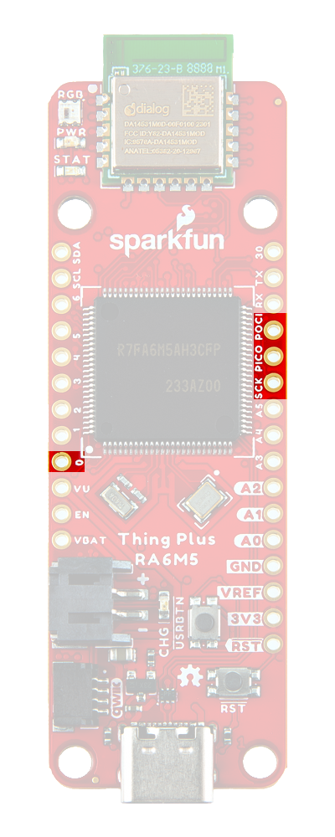
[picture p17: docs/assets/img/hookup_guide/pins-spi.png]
Annotated image of SPI pins
	
	<figcaption markdown>SPI pins on the RA6M5 Thing Plus.</figcaption>
	</figure>

	</div>

	<div markdown>

	!!! arduino
		By default, in the Arduino IDE, the RA6M5 Thing Plus board definition supports:

		<article style="text-align: center;" markdown>

		| SPI Pin | GPIO             |
		| :-----: | :--------------- |
		| POCI    | `P110` *(`D17`)* |
		| PICO    | `P109` *(`D18`)* |
		| SCK     | `P111` *(`D19`)* |
		| CS      | `P112` *(`D0`)*  |

		</article>

		To utilize SPI communication on other pins, users will need to create a custom SPI object and declare which pins to access.

	!!! tip
		To learn more about the serial peripheral interface (SPI) protocol, check out this great [tutorial](https://learn.sparkfun.com/tutorials/16).

		<div class="grid cards" markdown align="center">

		-   <a href="https://learn.sparkfun.com/tutorials/16">
			<figure markdown>
			Tutorial Thumbnail
			</figure>

			---

			**Serial Peripheral Interface (SPI)**</a>

		</div>

	</div>

	</div>

=== "<abbr title="Inter-Integrated Circuit">I^2^C</abbr> Pins"
	The RA6M5 supports up to three I^2^C buses. However, only a single I^2^C bus is defined in the Renesas Arduino core. In the Arduino IDE, the [Wire class](https://www.arduino.cc/en/reference/wire) is configured to utilize the SDA - `P401`/`D15` and SCL -`P400`/`D16` pins. These pins also share the same I^2^C bus as the [Qwiic connector](#qwiic-connector) and [MAX17048 fuel gauge](#battery-fuel-gauge).

	<div class="grid" markdown>

	<div markdown>

	<figure markdown>
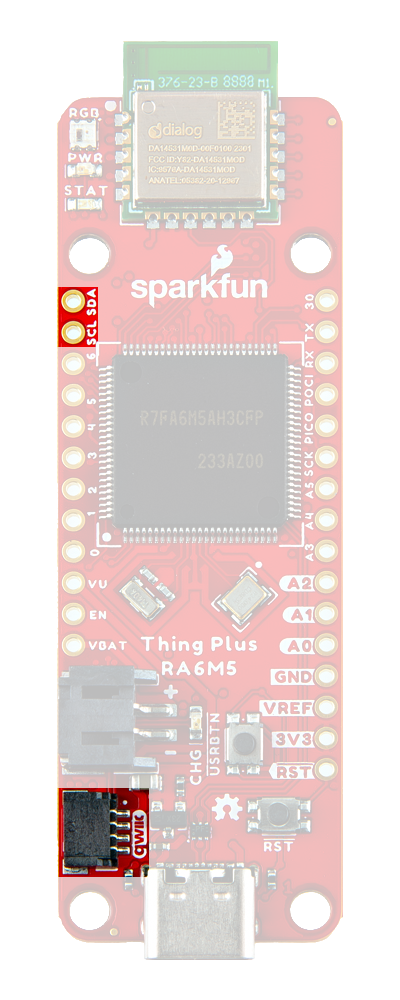
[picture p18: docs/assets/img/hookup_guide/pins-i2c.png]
Annotated image of I2C connections
	
	<figcaption markdown>I^2^C connections on the RA6M5 Thing Plus.</figcaption>
	</figure>

	</div>

	<div markdown>

	!!! arduino
		By default, in the Arduino IDE, the RA6M5 Thing Plus board definition supports:

		<article style="text-align: center;" markdown>

		| I^2^C Pin | GPIO             |
		| :-------: | :--------------- |
		| SCL       | `P400` *(`D16`)* |
		| SDA       | `P401` *(`D15`)* |

		</article>

		To utilize the I^2^C ports on other pins, users will need to create a custom Wire object and declare which pins to access.

	!!! tip
		To learn more about the inter-integrated circuit (I^2^C) protocol, check out this great [tutorial](https://learn.sparkfun.com/tutorials/82).

		<div class="grid cards" markdown align="center">

		-   <a href="https://learn.sparkfun.com/tutorials/82">
			<figure markdown>
			Tutorial Thumbnail
			</figure>

			---

			**I2C**</a>

		</div>

	</div>

	</div>

	??? tip "What is Qwiic?"

		<div class="grid" markdown>

		<div markdown>

		<!-- Qwiic Banner -->
		<article style="text-align: center;" markdown>
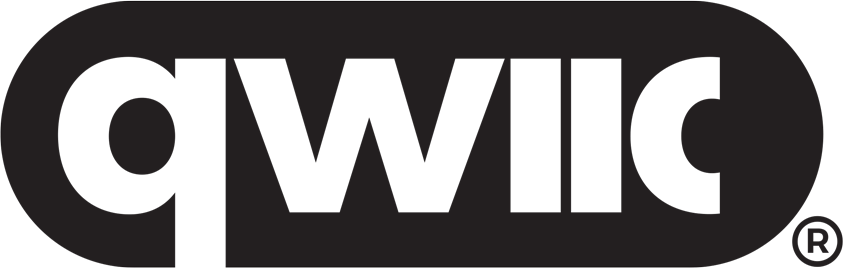
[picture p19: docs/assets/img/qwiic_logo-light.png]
Qwiic Logo - light theme (https://www.sparkfun.com/qwiic)
		
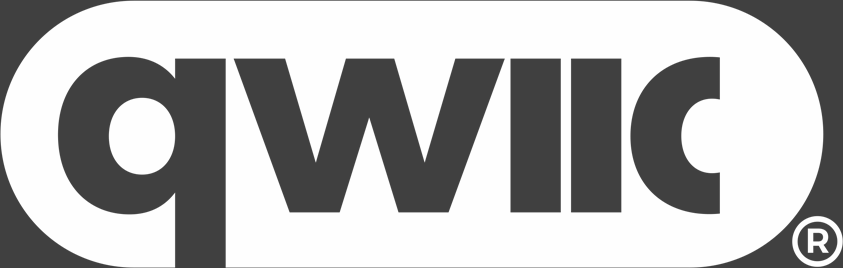
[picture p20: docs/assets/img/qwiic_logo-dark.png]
Qwiic Logo - dark theme (https://www.sparkfun.com/qwiic)
		
		</article>

		---

		The [Qwiic connect system](https://www.sparkfun.com/qwiic) is a solderless, polarized connection system that allows users to seamlessly daisy chain 	I^2^C boards together. Play the video, to learn more about the Qwiic connect system or click on the banner above to learn more about [Qwiic 	products](https://www.sparkfun.com/qwiic).

		</div>

		<div style="max-height=400px;" markdown>

		<article style="text-align: center;" markdown>
		<div class="video-container">
		<iframe src="https://www.youtube.com/embed/x0RDEHqFIF8" title="SparkFun's Qwiic Connect System" frameborder="0" allow="accelerometer; 	encrypted-media; gyroscope; picture-in-picture" allowfullscreen></iframe>

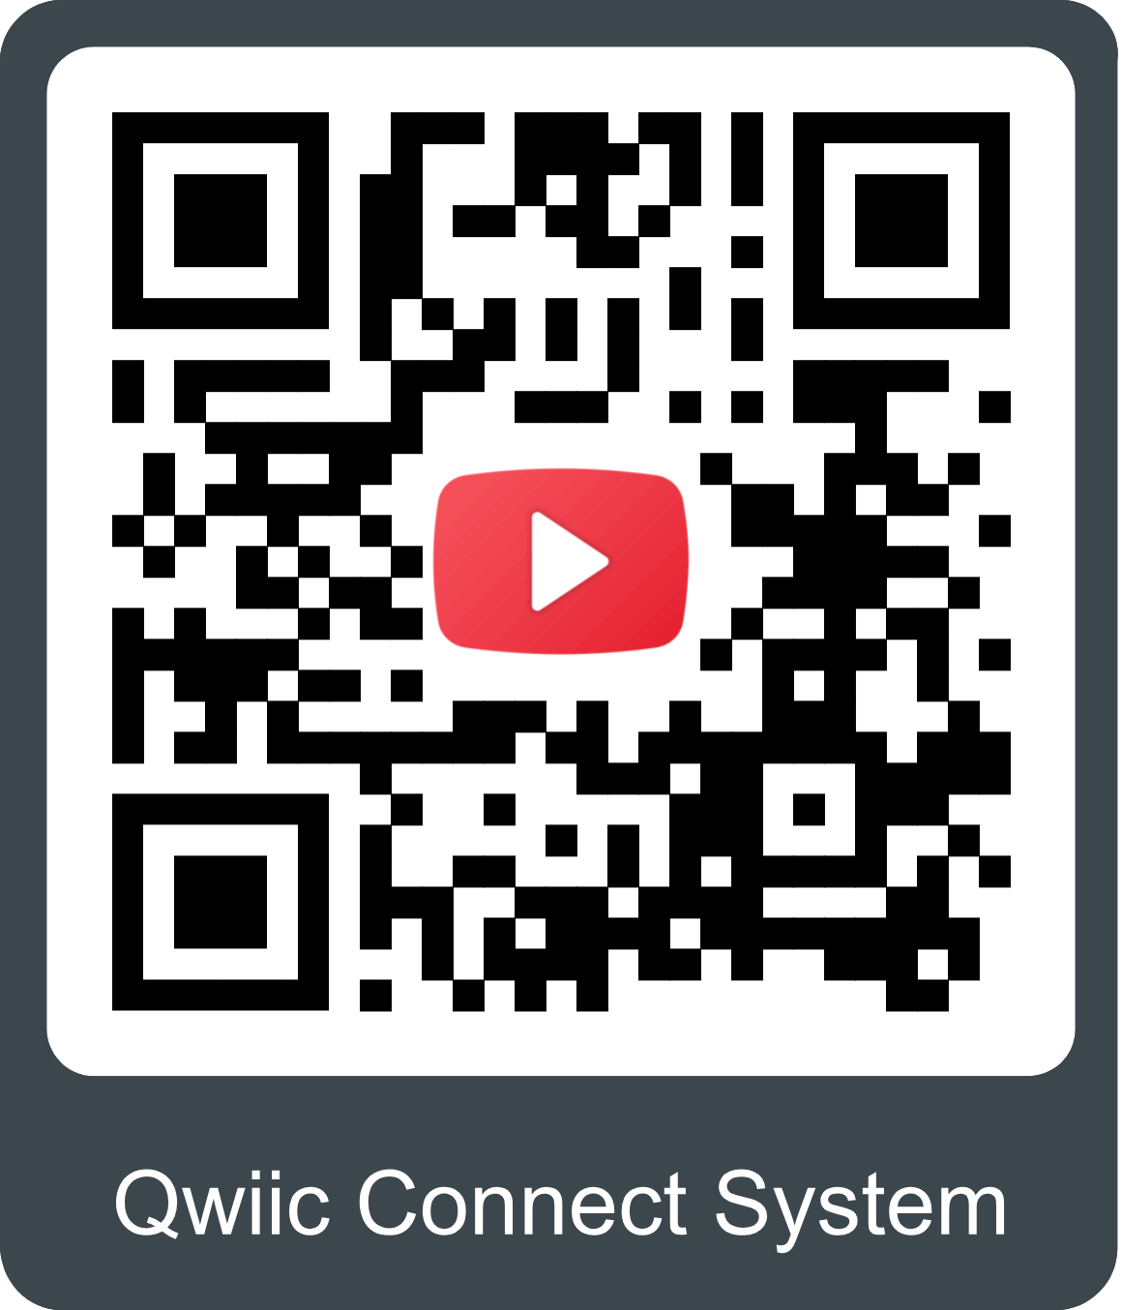
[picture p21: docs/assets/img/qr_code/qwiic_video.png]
QR code to instructional video
		
		</div>
		</article>

		</div>

		</div>

		!!! info "Features of the Qwiic System"

			=== "No Soldering"

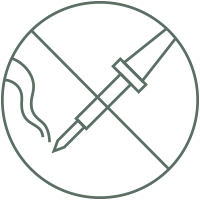
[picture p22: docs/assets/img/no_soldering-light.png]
no soldering - light theme
				
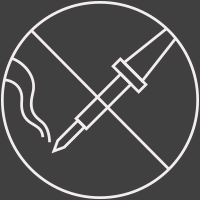
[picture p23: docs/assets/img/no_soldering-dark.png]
no soldering - dark theme
				

				Qwiic cables (4-pin JST) plug easily from development boards to sensors, shields, accessory boards and more, making easy work of setting up a new prototype.

			=== "Polarized Connector"

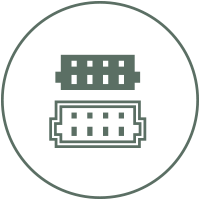
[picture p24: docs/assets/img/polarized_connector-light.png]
polarized connector - light theme
				
				polarized connector - dark theme

				There's no need to worry about accidentally swapping the `SDA` and `SCL` wires on your breadboard. The Qwiic connector is polarized so you know you’ll have it wired correctly every time.

				The part numbers for the PCB connector is `SM04B-SRSS` ([Datasheet](https://cdn.sparkfun.com/assets/parts/1/2/2/8/9/Qwiic_Connector_Datasheet.pdf)) and the mating connector on the cables is `SHR04V-S-B`; or an equivalent *1mm pitch, 4-pin JST connection*.

			=== "Daisy Chain-able"

				daisy chainable - light theme
				daisy chainable - dark theme

				It’s time to leverage the power of the I^2^C bus! Most Qwiic boards will have two or more connectors on them, allowing multiple devices to be connected.

=== "Interrupts"
	The RA6M5 provides IRQ support on several of its pins. In the Arduino IDE, interrupt requests are configured using the [`#!cpp attachInterrupt(digitalPinToInterrupt(pin), ISR, mode)` function](https://www.arduino.cc/reference/en/language/functions/external-interrupts/attachinterrupt/). *The available IRQ pins are highlighted in the image below.*

	<div class="grid" markdown>

	<div markdown>

	<figure markdown>
	Annotated image of IRQ pins
	<figcaption markdown>Interrupt request pins on the RA6M5 Thing Plus.</figcaption>
	</figure>

	</div>

	<div markdown>

	!!! arduino
		In the Arduino IDE, interrupt requests are configured using the [`#!cpp attachInterrupt(digitalPinToInterrupt(pin), ISR, mode)` function](https://www.arduino.cc/reference/en/language/functions/external-interrupts/attachinterrupt/), where:

		- `pin` - The GPIO pin
		- `ISR` -	The interrupt service routine to call/execute when the interrupt occurs
		- `mode` - Defines how the interrupt should be triggered:
			- `LOW` - When the pin is **LOW**
			- `CHANGE` - Whenever the pin changes value
			- `RISING` - When the pin changes from **LOW** to **HIGH**
			- `FALLING`- When the pin changes from **HIGH** to **LOW**

	!!! tip
		To learn more about interrupts, check out this great [tutorial](https://learn.sparkfun.com/tutorials/316).

		<div class="grid cards" markdown align="center">

		-   <a href="https://learn.sparkfun.com/tutorials/316">
			<figure markdown>
			Tutorial Thumbnail
			</figure>

			---

			**Processor Interrupts with Arduino**</a>

		</div>

	</div>

	</div>

<!-- SSI???
=== ":material-music: I2S or SSI?"
	The RA6M5 provides peripheral support for a serial sound interface. However, this is not natively supported with in the Renesas-Arcuino core. Users will need to utilize Renesas's [FSP](https://renesas.github.io/rza-fsp/group___s_s_i.html) to enable this peripheral.

	<div class="grid" markdown>

	<div markdown>

	<figure markdown>
	[![SSI Protocol](https://renesas.github.io/rza-fsp/r_ssi_frame_diagram.PNG){ width=500 }](https://renesas.github.io/rza-fsp/r_ssi_frame_diagram.PNG "Click to enlarge")
	<figcaption markdown>Communication protocol for the serial sound interface.</figcaption>
	</figure>

	</div>

	<div markdown>

	- AUD_CLK: `P400` *(`D16`)*
	- AUD_CLK: `P402` *(`D5`)*
	- BCK0: `P403` *(`D4`)*
	- LRCK0: `P404` *(`D3`)*
	- TXD0: `P405` *(`D2`)*
	- RXD0: `P406` *(`D1`)*

	</div>

	</div>
-->

<!-- CAN Bus - not supported???
??? info "CAN Bus Support"
	Diving into the [RA6M5 datasheet](https://www.renesas.com/us/en/document/dst/ra6m5-group-datasheet?r=1493931), users may notice that there are CAN buses supported on a few of the available hardware pins. However, please refer to the [RA6M5 user manual](https://www.renesas.com/us/en/document/man/ra6m5-group-users-manual-hardware?r=1493931) for the protocol implementation. *(i.e. There could be a bus contention issues with the `CAN1` pins, which share `UART9` with the Bluetooth module.)*

	<article style="text-align: center;" markdown>

	| CAN Bus  | GPIO Pins                                              |
	| :------: | :----------------------------------------------------- |
	| **CAN0** | **RX** - `P402` *(`D05`)*<br>**TX** - `P401` *(`D15`)* |
	| **CAN1** | **RX** - `P110` *(`D17`)*<br>**TX** - `P109` *(`D18`)* |

	</article>
-->

---

*For more technical specifications on the **I/O** pins, please refer to the [schematic](./assets/board_files/schematic.pdf), [RA6M5 datasheet](https://www.renesas.com/us/en/document/dst/ra6m5-group-datasheet?r=1493931), and [RA6M5 user manual](https://www.renesas.com/us/en/document/man/ra6m5-group-users-manual-hardware?r=1493931).*

## :material-bluetooth:&nbsp;DA14531MOD BLE Module
The [DA14531MOD](https://www.renesas.com/us/en/document/dst/da14531-module-datasheet), from [Renesas](https://www.renesas.com/), provides the RA6M5 Thing Plus with Bluetooth connectivity. When actively transmitting, the DA14531MOD sips a mere 4mA; low enough to operate on a small coin-cell battery. The module is programmed with a precompiled binary of the CodeLess SDK, featuring Renesas' [SmartBond™ - CodeLess™ AT command](https://lpccs-docs.renesas.com/UM-140-DA145x-CodeLess/index.html) set. With the implementation of an AT command platform to configure the DA1431MOD's Bluetooth connectivity, source code is no longer required to be written for the module, to operate as a peripheral device.

<div class="grid" markdown>

<div markdown>

<figure markdown>
DA14531MOD BLE Module
<figcaption markdown>The DA14531MOD BLE module on the RA6M5 Thing Plus.</figcaption>
</figure>

</div>

<div markdown>

* Bluetooth 5.1 system-on-chip (SoC)
	* Supports up to three connections
	* 32-bit Arm® Cortex® M0+
		* Clock frequency: 16 MHz
		* Memory:
			* Flash: 128 Kb
			* RAM: 48 Kb
			* ROM: 144 Kb
			* OTP: 32 Kb
* Operating range (1.8 V - 3.6 V)
	* Receive: 2mA
	* Transmit: 4mA
	* Sleep: 1.8 &micro;A
* Radio
	* Transmit Power: -19 to +2.2 dBm
	* Receiver Sensitivity: -93 dBm

</div>

</div>

??? info "Debug Pins"
	The SWD pins for the DA14531MOD are available as 0.1" test points on the board. However, users are unlikely to utilize these pins unless they wish to modify the pre-existing firmware on the DA14531MOD.

	<div class="grid" markdown>

	<div markdown>

    <table border="1" style="text-align: center;" markdown>
        <tr markdown>
            <td style="text-align:center" markdown>**GND**</td>
            <td style="text-align:center" markdown>**SWCLK**</td>
            <td style="text-align:center" markdown>**3.3V**</td>
            <td style="text-align:center" markdown>**|**</td>
        </tr>
        <tr markdown>
            <td style="text-align:center" markdown>**RST**</td>
            <td></td>
            <td style="text-align:center" markdown>**SWDIO**</td>
            <td></td>
        </tr>
    </table>

	!!! info
		In case users are interested, these are the pin connections of the SWD test points to the DA14531MOD. For more details, please reference the [schematic](./assets/board_files/schematic.pdf).

		- `SWDIO`: `P0_10`
		- `SWCLK`: `P0_2`

	!!! note
		In order to debug the DA14531MOD, users will need a debug probe. We recommend the [J-Link debug probes from Segger](https://www.segger.com/products/debug-probes/j-link/). However, users should verify the supported devices before purchasing these products; for example, we had a few issues with the [J-Link EDU Mini](https://www.sparkfun.com/products/24078).

	</div>

	<div markdown>

	<figure markdown>
	DA14531MOD SWD Pins
	<figcaption markdown>The SWD pins for the DA14531MOD on the RA6M5 Thing Plus.</figcaption>
	</figure>

	</div>

	</div>

??? code "CodeLess Firmware"
	The [CodeLess™ AT command](https://lpccs-docs.renesas.com/UM-140-DA145x-CodeLess/index.html) allows users to easily configure the RA6M5 Thing Plus as a central or peripheral Bluetooth device. In addition, users can also potentially implement OTA updates with the CodeLess™ AT commands.

	The precompiled binary from the CodeLess SDK utilized as the firmware image, on the DA14531MOD of the RA6M5 Thing Plus, is the `codeless_531_datapump.hex` *(CodeLess for DA1453x datapump)*.

	!!! info "Serial Port Setting"
		The default settings of the serial port on the DA14531MOD, for AT commands:

		- BaudRate : 57600
		- DataBits : 8
		- StopBits : 1
		- Parity : None
		- Flow Control : None
		- Transmit Text: Append CR

*For more details, please refer to the [DA14531 datasheet](https://www.renesas.com/us/en/document/dst/da14531-module-datasheet), and [CodeLess user manual](ttps://lpccs-docs.renesas.com/UM-140-DA145x-CodeLess/index.html).*

## External Memory

### QSPI Flash
The RA6M5 Thing Plus features 16MB of QSPI Flash memory, with the MX25L12833F from [Macronix](https://www.macronix.com/en-us/Pages/default.aspx). The [MX25L12833F QSPI Flash memory](./assets/component_documentation/MX25L12833F.pdf) provides users with high-speed non-volatile memory to develop and execute data-driven applications. This feature is perfect for data logging, data processing, or executing memory-intensive algorithms. The QSPI Flash memory can also be used to store a firmware backup or enable software updates.

<div class="grid" markdown>

<div markdown>

The Flash memory is connected to the following GPIO:

- **CLK:** GPIO `P100` *(`D40`)*
- **D0:** GPIO `P102` *(`D42`)*
- **D1:** GPIO `P101` *(`D43`)*
- **D2:** GPIO `P104` *(`D44`)*
- **D3:** GPIO `P103` *(`D45`)*
- **SS:** GPIO `P501` *(`D41`)*

</div>

<div markdown>

<figure markdown>
QSPI Flash
<figcaption markdown>The MX25L12833F QSPI Flash memory IC on the back of the RA6M5 Thing Plus.</figcaption>
</figure>

</div>

</div>

*For more details, please refer to the [MX25L12833F datasheet](./assets/component_documentation/MX25L12833F.pdf), the [schematic](./assets/board_files/schematic.pdf), [RA6M5 datasheet](https://www.renesas.com/us/en/document/dst/ra6m5-group-datasheet?r=1493931), and [RA6M5 user manual](https://www.renesas.com/us/en/document/man/ra6m5-group-users-manual-hardware?r=1493931).*

### &micro;SD Card Socket
The &micro;SD card socket is connected to the SD host interface for fast data logging. This feature is useful for data collection over extended periods and for simplifying data retrieval.

<div class="grid" markdown>

<div markdown>

The &micro;SD card slot is connected to the following GPIO:

- **CLK:** GPIO `P214` *(`D22`)*
- **D0:** GPIO `P208` *(`D24`)*
- **D1:** GPIO `P410` *(`D25`)*
- **D2:** GPIO `P206` *(`D26`)*
- **D3:** GPIO `P205` *(`D27`)*

</div>

<div markdown>

<figure markdown>
micro SD socket
<figcaption markdown>&micro;SD card slot on the back of the RA6M5 Thing Plus.</figcaption>
</figure>

</div>

</div>

!!! warning "Data Corruption"
	To avoid corrupting an SD card, users should disable all activity with the SD card before removing it from the RA6M5 Thing Plus.

	The [FATFileSystem library](https://github.com/arduino/ArduinoCore-renesas/tree/main/libraries/FATFilesystem) built into the Renesas-Arduino core, supports &micro;SD cards with a **FAT32** file system *(i.e. SD cards **up to 32GB** in size)*.

	- While users may be able to use cards with a higher storage capacity, we highly advise against it. As users may experience data loss due to a corrupt file system *(i.e. SD cards with a storage capacity greater than 32GB are not meant to be formatted with a FAT32 file system)*.

!!! note
	The RA6M5 Thing Plus, offers users additional control of the SD card slot with the following pin connections:

	<article style="text-align: center;" markdown>

	| Pin Name | Connection to RA6M5   | Operation | Function |
	| :------: | :-------------------: | :-------: | :------- |
	| **SDEN** | GPIO `P708` *(`D35`)* | Active **LOW** | Controls power to the SD card slot.<br>- A **LOW** signal will disable power to the SD card slot |
	| **CD**   | GPIO `P210` *(`D28`)* | Active **LOW** | Read the pin latch, to determine if an SD card is inserted<br>- A **LOW** signal will indicate an SD card is present |
	| **WP**   | GPIO `P414` *(`D29`)* | Active **LOW** | Read if the write protection is engaged on the SD card<br>- A **LOW** signal will indicate write protection is enabled on the SD card |

	</article>

*For more details, please refer to the [schematic](./assets/board_files/schematic.pdf), [RA6M5 datasheet](https://www.renesas.com/us/en/document/dst/ra6m5-group-datasheet?r=1493931), and [RA6M5 user manual](https://www.renesas.com/us/en/document/man/ra6m5-group-users-manual-hardware?r=1493931).*

## I<sup>2</sup>C Bus

### Qwiic Connector
A Qwiic connector is provided for users to seamlessly integrate with [SparkFun's Qwiic Ecosystem](https://www.sparkfun.com/qwiic). Otherwise, users can also access the [I^2^C bus](#i2c-pins) through the PTH pins broken out on the board.

<figure markdown>
Qwiic connector and I2C pins
<figcaption markdown>Qwiic connector and I^2^C pins on the RA6M5 Thing Plus.</figcaption>
</figure>

??? tip "What is Qwiic?"

	<div class="grid" markdown>

	<div markdown>

	<!-- Qwiic Banner -->
	<article style="text-align: center;" markdown>
	Qwiic Logo - light theme (https://www.sparkfun.com/qwiic)
	Qwiic Logo - dark theme (https://www.sparkfun.com/qwiic)
	</article>

	---

	The [Qwiic connect system](https://www.sparkfun.com/qwiic) is a solderless, polarized connection system that allows users to seamlessly daisy chain I^2^C boards together. Play the video, to learn more about the Qwiic connect system or click on the banner above to learn more about [Qwiic products](https://www.sparkfun.com/qwiic).

	</div>

	<div style="max-height=400px;" markdown>

	<article style="text-align: center;" markdown>
	<div class="video-container">
	<iframe src="https://www.youtube.com/embed/x0RDEHqFIF8" title="SparkFun's Qwiic Connect System" frameborder="0" allow="accelerometer; encrypted-media; gyroscope; picture-in-picture" allowfullscreen></iframe>

	QR code to instructional video
	</div>
	</article>

	</div>

	</div>

	!!! info "Features of the Qwiic System"

		=== "No Soldering"

			no soldering - light theme
			no soldering - dark theme

			Qwiic cables (4-pin JST) plug easily from development boards to sensors, shields, accessory boards and more, making easy work of setting up a new prototype.

		=== "Polarized Connector"

			polarized connector - light theme
			polarized connector - dark theme

			There's no need to worry about accidentally swapping the `SDA` and `SCL` wires on your breadboard. The Qwiic connector is polarized so you know you’ll have it wired correctly every time.

			The part numbers for the PCB connector is `SM04B-SRSS` ([Datasheet](https://cdn.sparkfun.com/assets/parts/1/2/2/8/9/Qwiic_Connector_Datasheet.pdf)) and the mating connector on the cables is `SHR04V-S-B`; or an equivalent *1mm pitch, 4-pin JST connection*.

		=== "Daisy Chain-able"

			daisy chainable - light theme
			daisy chainable - dark theme

			It’s time to leverage the power of the I^2^C bus! Most Qwiic boards will have two or more connectors on them, allowing multiple devices to be connected.

### Battery Fuel Gauge
The [MAX17048 fuel gauge](./assets/component_documentation/MAX17048.pdf), from [Analog Devices](https://www.analog.com/), measures the approximate charge/discharge rate, state of charge (SOC) (based on *ModelGauge* algorithm), and voltage of a connected battery. The sensor is also powered directly from a connected LiPo battery *(`VBAT`)*.

<div class="grid" markdown>

<div markdown>

<article style="text-align: center;" markdown>

| I^2^C Address | **0x36** (7-bit)<br>**0x6C** (write)/**0x6D** (read) |
| :-- | :-- |
| Voltage Measurement | Range: 2.5 - 5 V<br>Precision: &PlusMinus;7.5 mV/Cell<br>Resolution 1.25 mV/Cell
| Current Consumption | Sleep: .5 - 2 µA<br>Hibernate: 3 - 5 µA<br>Active: 23 - 40 µA |

</article>

!!! info "Alert Pin"
	The fuel gauge features an `Alert` pin, which can be configured to trigger an interrupt *(active **LOW**)* on GPIO `P000` *(`D39`)* of the RA6M5 for:

	- Low Charge
	- 1% Charge *(Remaining)*
	- IC Reset
	- Overvoltage
	- Undervoltage

</div>

<div markdown>

<figure markdown>
MAX17048 Fuel Gauge
<figcaption markdown>The MAX17048 fuel gauge on the RA6M5 Thing Plus.</figcaption>
</figure>

</div>

</div>

*For more information, please refer to the [MAX17048 datasheet](./assets/component_documentation/MAX17048.pdf) and the [schematic](./assets/board_files/schematic.pdf).*

## Status LEDs
There are four status LEDs on the RA6M5 Thing Plus:

<div class="grid" markdown>

<div markdown>

- `PWR` - Power *(Red)*
	- Illuminates once power is applied to `3V3`
- `RGB` - WS2812 *(RGB)*
	- An addressable [WS2812 LED](./assets/component_documentation/WS2812C-2020.pdf)
	- Connected to GPIO `P105` *(`D13` or `RGB_LED`)* of the RA6M5
- `STAT` - Status *(Blue)*
	- Connected to the RA6M5 `P106` *(`D14`/`LED_BUILTIN`)* GPIO
- `CHG` - Battery Charge *(Yellow)*
	- **ON** - Actively charging a battery
	- **OFF** - The charge controller is shut down or battery charging is complete

</div>

<div markdown>

<figure markdown>
LEDs
<figcaption markdown>
The status indicator LEDs on the RA6M5 Thing Plus.
</figcaption>
</figure>

</div>

</div>

## Buttons
There are two buttons on the RA6M5 Thing Plus: ++"RST"++ and ++"USRBTN"++

<figure markdown>
Buttons
<figcaption markdown>Buttons on the RA6M5 Thing Plus.</figcaption>
</figure>

- ++"USRBTN"++ - The **user** button is provided as an available input for the RA6M5; it is connected to GPIO `P415` *(`D31`)*
- ++"RST"++ - The **reset** button allows users to reset the firmware running on the RA6M5 without interrupting the power
	<!-- - DFU Mode - The RA6M5 can be manually forced into DFU mode to upload code
		1. Double-tap the ++"RST"++ button
			- The `STAT` LED should be fading in/out very slowly
		1. Users should now, be able to upload a new program
			- It shouldn't be necessary to select a COM port in the Arduino IDE; only the board needs to be selected
		1. Once programming is complete, the MCU should reboot on its own. Otherwise:
			- Press the ++"RST"++ button
			- Power cycle the board -->

??? success "DFU Mode"
	If users are having issues uploading code to the board, the RA6M5 can be manually forced into DFU mode. This issue, often occurs when the USB connection is busy and a reset can't be triggered on the RA6M5, to initialize the upload process. To force the RA6M5 Thing Plus into DFU mode:

	1. Double-tap the ++"RST"++ button
		- The `STAT` LED should be fading in/out very slowly
	1. Users should now, be able to upload a new program
		- It shouldn't be necessary to select a COM port in the Arduino IDE; only the board needs to be selected
	1. Once programming is complete, the MCU should reboot on its own. Otherwise:
		- Press the ++"RST"++ button
		- Power cycle the board

*For more details, please refer to the [schematic](./assets/board_files/schematic.pdf).*

## Jumpers

??? note "Never modified a jumper before?"
	Check out our [Jumper Pads and PCB Traces tutorial](https://learn.sparkfun.com/tutorials/664) for a quick introduction!

	<div class="grid cards col-4" markdown align="center">

	-   <a href="https://learn.sparkfun.com/tutorials/664">
		<figure markdown>
		Tutorial thumbnail
		</figure>

		---

		**How to Work with Jumper Pads and PCB Traces**</a>

	</div>

The five jumpers on the back of the board can be used to easily modify the hardware connections on the board.

<div class="grid" markdown>

<div markdown>

<figure markdown>
Jumpers
<figcaption markdown>The jumpers on the back of the RA6M5 Thing Plus PCB.</figcaption>
</figure>

</div>

<div markdown>

- **`PWR`** - Cut this jumper to disable the red, `PWR` LED
- **`RST`** - Cut this jumper to disconnect the reset pin of the DA14531MOD from the RA6M5 `P115`/`D37` GPIO
- **`SHLD`** - Cut this jumper to isolate the USB-C connector shield from GND
- **`I2C`** - Open this dual-jumper to disconnect the pull-up resistors from the `SDA` and `SCL`
- **`CHG`** - Cut this jumper to disable the yellow, `CHG` LED

</div>

</div>

*For more details, please refer to the [schematic](./assets/board_files/schematic.pdf).*

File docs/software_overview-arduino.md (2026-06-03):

---
icon: simple/arduino
---

!!! tip
	For first-time users, who have never programmed before and are looking to use the Arduino IDE, we recommend beginning with the [SparkFun Inventor's Kit (SIK)](https://www.sparkfun.com/products/15631), which is designed to help users get started programming with the Arduino IDE.

Most users should already be familiar with the Arduino IDE and its use. However, for those of you who have never heard the name *Arduino* before, feel free to check out the [Arduino website](https://www.arduino.cc/en/Guide/HomePage). To get started with using the Arduino IDE, check out our tutorials below:

<div class="grid cards" markdown align="center">

-   <a href="https://learn.sparkfun.com/tutorials/50">
	<figure markdown>
	What is an Arduino?
	</figure>

	---

	**What is an Arduino?**</a>

-   <a href="https://learn.sparkfun.com/tutorials/61">
	<figure markdown>
	Installing the Arduino IDE
	</figure>

	---

	**Installing the Arduino IDE**</a>

-   <a href="https://learn.sparkfun.com/tutorials/1265">
	<figure markdown>
	Installing Board Definitions in the Arduino IDE
	</figure>

	---

	**Installing Board Definitions in the Arduino IDE**</a>

-   <a href="https://learn.sparkfun.com/tutorials/15">
	<figure markdown>
	Installing an Arduino Library
	</figure>

	---

	**Installing an Arduino Library**</a>

</div>

## Arduino Core

### Installation
!!! success "Installing the *Ported* Renesas-Arduino Core"
	In order to program the RA6M5 Thing Plus in the Arduino IDE, users will need to install the **Arduino Renesas Portenta board** definitions from the Renesas-Arduino core. However, until the [RA6M5 Thing Plus is officially adopted into the Renesas-Arduino core](https://github.com/arduino/ArduinoCore-renesas/pull/290), users need to utilize [our port of the **Renesas-Arduino core**](./assets/SFE-Renesas-Arduino_core.zip).

	1. Before users can install our ported version of the Renesas-Arduino core, they should first install the **Arduino Renesas Portenta board** definitions of the [*official* Renesas-Arduino core](https://github.com/arduino/ArduinoCore-renesas) in the Arduino IDE.
		- This will ensure that any required compilation and upload tools are installed for the Arduino core.
		- In the Board Manager of the Arduino IDE, select and install the **Arduino Renesas Portenta board** definitions from the [Renesas-Arduino core](https://github.com/arduino/ArduinoCore-renesas).
			<figure markdown>
			Install the Renesas-Arduino Core
			<figcaption markdown>Installing the [Renesas-Arduino core](https://github.com/arduino/ArduinoCore-renesas) in the Arduino IDE.</figcaption>
			</figure>
	2. Once installed, users will need to locate the `packages` directory for the Arduino cores in the Arduino IDE:

		<div class="grid cards" markdown>

		-   **Windows**

			---

			On Windows, the directory location may vary based on whether the Arduino IDE was installed for an individual user or all users:

			- The user's `AppData` directory *(hidden folder - primary)*:

					C:\Users\{==<insert username>==}\AppData\Local\Arduino15\packages

			- The user's `ArduinoData` directory (*local*):

					C:\Users\{==<insert username>==}\Documents\Arduino\hardware

			- The `Program Files` or `Program Files(x86)` directories:

					C:\Program Files{++(x86)++}\Arduino IDE

		-   **MacOS**

			---

			With Mac OS, users should check the `Applications` and `Library` directories:

			- `Library` directory (primary):

					~/Library/Arduino15/packages/

			- `Applications` directory (*local*):

					/Applications/Arduino.app/hardware

		-   **Linux**

			---

			For Linux, this may be located in the following directories:

			- Primary:

					/home/$USER/.arduino15/packages

			- Local:

					/home/$USER/Arduino/hardware

			??? tip
				As mentioned in [Arduino's guide for installing the Arduino IDE on Linux](https://docs.arduino.cc/software/ide-v2/tutorials/getting-started/ide-v2-downloading-and-installing/#linux), users may need to run the following commands in the terminal:

				```bash
				sudo add-apt-repository universe
				sudo apt install libfuse2
				```

				In order to utilize the serial terminal or recognize the board in DFU mode, users may also need to run the following commands in the terminal:

				```bash
				usermod -a -G dialout $USERNAME
				usermod -a -G plugdev $USERNAME
				```

				- `$USERNAME` is the login username
				- After, a restart or logout is required

		</div>

	3. After the `packages` directory has been located, users will need to navigate to the Renesas Arduino core. It is usually located in the `./arduino/hardware/{==renesas_portenta==}/{++<version number>++}/` directory of the `packages` folder.
	4. The Arduino core is followed by a directory, named after the Arduino core's release `{++<version number>++}`. From there, users will need to create a new directory/folder in the `renesas_portenta` directory with the `version number` bumped up.
		- *For example, if the current version is `1.1.0`, users can name the new directory `1.2.0`.*
	4. Next, users will need to download and extract the files from [our ported version of the Renesas-Arduino core](./assets/SFE-Renesas-Arduino_core.zip):
		<article style="text-align: center;" markdown>
		[:material-download:{ .heart }&nbsp;&nbsp;Download our Renesas-Arduino Core *(Ported)*](./assets/SFE-Renesas-Arduino_core.zip "Click to download the ported Arduino core"){ .md-button .md-button--primary }
		</article>
	4. Once extracted, users will need to copy over the files from [our ported version of the Renesas-Arduino core](./assets/SFE-Renesas-Arduino_core.zip)into the new directory that was created earlier:
		<figure markdown>
		Extracted files
		<figcaption markdown>The files extracted from [our ported version of the Renesas-Arduino core](./assets/SFE-Renesas-Arduino_core.zip).</figcaption>
		</figure>
	5. Once the extracted files have been copied into the new directory, users will need to install the USB drivers for the board by executing the `post-install.*` script:
		- Windows: `post-install.bat`
		- Mac/Linux: `post-install.sh`

	!!! info
		This information is accurate as of April 2024; however, it may become irrelevant in the future *(once the [RA6M5 Thing Plus is included in the Renesas-Arduino core](https://github.com/arduino/ArduinoCore-renesas/pull/290))*. At which point, users may disregard this note and/or request for this information to be updated by [filing an issue](../github/file_issue).

??? failure "Do Not Use - *Hardware Not Officially Supported (yet)*"
	!!! warning
		The instructions below are invalid; theRA6M5 Thing Plus has not been [officially added into the Renesas-Arduino core](https://github.com/arduino/ArduinoCore-renesas/pull/290). In the meantime, users will need to utilize [our port of the **Renesas-Arduino core**](./assets/SFE-Renesas-Arduino_core.zip) *(see instructions above)*.

	{--

	In order to program the RA6M5 Thing Plus in the Arduino IDE, users will need to install the [Renesas-Arduino core](https://github.com/arduino/ArduinoCore-renesas). The Arduino core can be found by searching for `Arduino Renesas Portenta Boards` in the **Board Manager** of the Arduino IDE. Once installed, the RA6M5 Thing Plus will become available in the **Board Manager**.

		Arduino Renesas Portenta Boards

	<div class="grid" markdown>

	<div markdown>

	For users who are unfamiliar with this process, please check out our tutorial on [installing an Arduino core](https://learn.sparkfun.com/tutorials/installing-board-definitions-in-the-arduino-ide/installing-an-arduino-board-definition).

	<div class="grid cards" markdown align="center">

	-   <a href="https://learn.sparkfun.com/tutorials/1265">
		<figure markdown>
		Installing Board Definitions in the Arduino IDE
		</figure>

		---

		**Installing Board Definitions in the Arduino IDE**</a>

	</div>

	</div>

	<div markdown>

	<figure markdown>
	Install the Renesas-Arduino Core
	<figcaption markdown>Installing the [Renesas-Arduino core](https://github.com/arduino/ArduinoCore-renesas) in the Arduino IDE.</figcaption>
	</figure>

	</div>

	</div>

	--}

### Programming a Board
In order to upload a sketch from the Arduino IDE onto the RA6M5 Thing Plus, users will need to select the `SparkFun Thing Plus RA6M5` from the **Tools** > **Board** > **Arduino Renesas Portenta Boards** > **SparkFun Thing Plus RA6M5** drop-down menu. Users will also need to select the serial port from the **Tools** > **Port** drop-down menu; the port should be automatically labeled, based upon the PID/VID of board in the USB driver.

<div class="grid" markdown>

<div markdown>

<figure markdown>
Select the RA6M5 Thing Plus
<figcaption markdown>Selecting the `SparkFun Thing Plus RA6M5` from the **Tools** drop-down menu in the Arduino IDE.</figcaption>
</figure>

</div>

<div markdown>

<figure markdown>
Select the RA6M5 Thing Plus
<figcaption markdown>Searching for the `SparkFun Thing Plus RA6M5` in the **Select Other Board and Port** menu in the Arduino IDE.</figcaption>
</figure>

</div>

</div>

Alternatively, in the Arduino IDE *(v2.`x`.`x`)*, users can also search for the board and serial port in the **Select Other Board and Port** menu. Once the appropriate board and serial port have been selected in the Arduino IDE, users can click the ++"&rarr;"++ *(upload)* button to begin the compilation and upload process.

??? success "DFU Mode"
	If users are having issues uploading code to the board, the RA6M5 can be manually forced into DFU mode. This issue, often occurs when the USB connection is busy and a reset can't be triggered on the RA6M5, to initialize the upload process. To force the RA6M5 Thing Plus into DFU mode:

	1. Double-tap the ++"RST"++ button
		- The `STAT` LED should be fading in/out very slowly
	1. Users should now, be able to upload a new program
		- It shouldn't be necessary to select a COM port in the Arduino IDE; only the board needs to be selected
	1. Once programming is complete, the MCU should reboot on its own. Otherwise:
		- Press the ++"RST"++ button
		- Power cycle the board

## Arduino Libraries
In order to utilize some of the peripherals of the RA6M5 Thing Plus with the Arduino IDE, users will need to [install Arduino libraries](https://learn.sparkfun.com/tutorials/15) for the peripheral devices/interfaces. For users who are unfamiliar with this process, please check out our tutorial below:

<div class="grid cards" markdown align="center">

-   <a href="https://learn.sparkfun.com/tutorials/15">
	<figure markdown>
	Installing an Arduino Library
	</figure>

	---

	**Installing an Arduino Library**</a>

</div>

### MAX17048 Fuel Gauge
While users are free to choose any Arduino library that provides support for MAX17048 fuel gauge, we recommend the [SparkFun MAX1704x Arduino library](https://github.com/sparkfun/SparkFun_MAX1704x_Fuel_Gauge_Arduino_Library); as it has been tested and verified to work with the MAX17048 on the RA6M5 Thing Plus. The [SparkFun MAX1704x Fuel Gauge Arduino library](https://github.com/sparkfun/SparkFun_MAX1704x_Fuel_Gauge_Arduino_Library) can be installed from the **Library Manager** in the Arduino IDE by searching for:

	SparkFun MAX1704x Fuel Gauge Arduino Library

<div class="grid" markdown>

<div markdown>

<figure markdown>
Install the SparkFun MAX1704x Arduino library Click to enlarge<figcaption markdown>SparkFun MAX1704x Fuel Gauge Arduino library in the library manager of the Arduino IDE.</figcaption>
</figure>

</div>

<div markdown>

!!! tip "Manually Download the Arduino Library"
	For users who would like to manually download and install the library, the `*.zip` file can be accessed from the [GitHub repository](https://github.com/sparkfun/MAX1704x_Fuel_Gauge_Arduino_Library) or downloaded by clicking the button below.

	<article style="text-align: center;" markdown>
	[:octicons-download-16:{ .heart } Download the Arduino Library](https://github.com/sparkfun/SparkFun_MAX1704x_Fuel_Gauge_Arduino_Library/archive/refs/heads/main.zip){ .md-button .md-button--primary }
	</article>

</div>

</div>

### WS2812 RGB LED
While users are free to choose any Arduino library that provides support for WS2812 LEDs, we recommend the [FastLED Arduino library](https://github.com/FastLED/FastLED/). It has been tested and verified to work with the RGB LED on the RA6M5 Thing Plus. The [FastLED Arduino library](https://github.com/FastLED/FastLED/) can be installed from the **Library Manager** in the Arduino IDE by searching for:

	FastLED Arduino Library

<div class="grid" markdown>

<div markdown>

<figure markdown>
Install the FastLED Arduino library Click to enlarge
<figcaption markdown>FastLED Arduino library in the library manager of the Arduino IDE.</figcaption>
</figure>

</div>

<div markdown>

!!! tip "Manually Download the Arduino Library"
	For users who would like to manually download and install the library, the `*.zip` file can be accessed from the [GitHub repository](https://github.com/FastLED/FastLED/) or downloaded by clicking the button below.

	<article style="text-align: center;" markdown>
	[:octicons-download-16:{ .heart } Download the Arduino Library](https://github.com/FastLED/FastLED/archive/refs/heads/master.zip){ .md-button .md-button--primary }
	</article>

</div>

</div>

??? tip "How to Define Parameters"
	While using the FastLED Arduino library, users need to define the following parameters to the **WS2812 RGB LED** included on the board. However, if additional LEDs are connected externally to the board, then the appropriate values should be provided for the Arduino library.

	**`#define NUM_LEDS 1`**
	:	There is only one WS2812 LED on the board

	**`#define DATA_PIN LED_RGB`**
	:	Declare which pin is connected to the WS2812 LED. On the RA6M5 Thing Plus, it is defined as `D13` or `RGB_LED` in the Arduino core for GPIO `P105`.

	**`#define LED_TYPE WS2812`**
	:	Declare the LED type for the library; the RA6M5 Thing Plus only includes `WS2812` RGB LED on the board.

### DA14531MOD BLE Module
--8<-- "./software-DA14531MOD.md"

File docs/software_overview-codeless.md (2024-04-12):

---
icon: material/bluetooth
---

The firmware provided with the DA14531MOD Bluetooth module on the RA66M5 Thing Plus, utilizes Renesas' [SmartBond™ - CodeLess™ AT commands](https://www.renesas.com/us/en/software-tool/smartbond-codeless-commands) platform. This platform allows users to quickly get started on developing wireless IoT applications through a set of [AT Commands *(ASCII instructions)*](https://en.wikipedia.org/wiki/Hayes_AT_command_set) without having to write a single line of source code. The basic set of AT commands provides control over the Bluetooth® LE connectivity: BLE connect/disconnect, advertise, stop advertising, change roles (central/peripheral), scan for nearby devices, report BLE address, etc.

<div class="grid" markdown>

<div markdown>

## User Manual
Renesas provides documentation for the CodeLess platform:

- [DA14531 TINY™ Module Getting Started](https://lpccs-docs.renesas.com/UM-B-139-Getting-Started-with-DA14531-TINY-Module/index.html)
- [DA145`XX` CodeLess User Manual](https://lpccs-docs.renesas.com/UM-140-DA145x-CodeLess/index.html)

</div>

<div markdown>

!!! tip "Default Configuration"
	The default serial port configuration of the DA14531MOD for AT commands:

	- BaudRate : 57600
	- DataBits : 8
	- StopBits : 1
	- Parity : None
	- Flow Control : None
	- Transmit Text: Append CR

??? info "Firmware"
	The precompiled binary from the CodeLess SDK utilized as the firmware image, on the DA14531MOD of the RA6M5 Thing Plus, is the `codeless_531_datapump.hex` *(CodeLess for DA1453x datapump)*.

</div>

</div>

## Arduino Library
--8<-- "./software-DA14531MOD.md"

### Example - SerialPassThrough
In our *unofficial* Arduino library, there are several examples for configuring the Bluetooth connectivity of the DA14531MOD. Also included, is a `SerialPassThrough` example. Once programmed on the RA6M5 Thing Plus, it allows users to directly interface with the DA14531MOD's UART port through the board's USB connection using a [serial terminal](https://learn.sparkfun.com/tutorials/112). The example, utilizes the default configuration settings for the serial port on the DA14531MOD, as [listed above](#user-manual).

!!! terminal "Serial Terminal Emulator"
	In order to configure the DA14531MOD on the RA6M5 Thing Plus, users will need access to a [serial terminal emulator](https://learn.sparkfun.com/tutorials/112) on their computer. The [**Serial Monitor** in the Arduino IDE](https://docs.arduino.cc/software/ide-v2/tutorials/ide-v2-serial-monitor/) is more than suitable for this application; however, users are also free to utilize their terminal emulator of choice. Below are a few options, outside of the Arduino IDE:

	??? tip "Serial Communication and Serial Terminal"
		Check out our hookup guides on [serial communication](https://learn.sparkfun.com/tutorials/8) and [installing a terminal emulator](https://learn.sparkfun.com/tutorials/112):

		<div class="grid cards" markdown align="center">

		-   <a href="https://learn.sparkfun.com/tutorials/8">
			<figure markdown>
			Tutorial Thumbnail
			</figure>

			---

			**Serial Communication**</a>

		-   <a href="https://learn.sparkfun.com/tutorials/112">
			<figure markdown>
			Tutorial Thumbnail
			</figure>

			---

			**Serial Terminal Basics**</a>

		</div>

	=== "Windows"
		For Windows computers, we highly recommend [TeraTerm](https://teratermproject.github.io/index-en.html) *(open-source development project)*.

	=== "Mac OS"
		For Mac OS, users can check out [CoolTerm](https://freeware.the-meiers.org/) *(freeware)*.

	=== "Linux"
		Some Linux operating systems will already have the `screen` terminal emulator preinstalled.

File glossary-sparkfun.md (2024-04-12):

*[µSD]: micro SD

*[ADC]: Analog-to-Digital Converter
*[ASK]: Amplitude-Shift Keying
*[AREF]: Analog Reference Voltage
*[BDS]: 北斗卫星导航系统 (Chinese - BeiDou Navigation Satellite System)
*[BPSK]: Binary Phase-Shift Keying
*[BSP]: Board Software/Support Package
*[BLE]: Bluetooth Low-Energy
*[CAN]: Controller Area Network
*[CORS]: Continuously Operating Reference Station
*[CPU]: Central Processing Unit
*[CRC]: Cyclic Redundancy Check
*[CS]: Chip Select
*[CTS]: Clear-to-Send
*[DAC]: Digital-to-Analog Converter
*[DFU]: Device Firmware Update
*[DGPS]: Differential Global Positioning System
*[ECC]: Error Correction Code
*[exFAT]: Extensible File Allocation Table
*[FAT]: File Allocation Table
<!-- *[FAT16]: File Allocation Table-16 -->
<!-- *[FAT32]: File Allocation Table-32 -->
*[FSK]: Frequency-Shift Keying
<!-- *[GEO]: Geostationary Orbit or Geosynchronous Equatorial Orbit (see glossary-alt.md) -->
*[GFSK]: Gaussian Frequency Shift Keying
*[GLONASS]: Глобальная Навигационная Спутниковая Система (Russian - Global Navigation Satellite System)
*[GND]: Ground
*[GNSS]: Global Navigation Satellite System
*[GPIO]: General Purpose Input and Output
*[GPS]: Global Positioning System
*[GSO]: Geosynchronous Orbit
*[HAL]: Hardware Abstraction Layer
<!-- *[I2C] or [I<sup>2</sup>C]: Inter-Integrated Circuit (see glossary-alt.md) -->
*[ITM]: Instrumentation Trace Macrocell
*[IoT]: Internet of Things
*[JST]: Japan Solderless Terminal (Manufacturing)
*[JTAG]: Joint Test Action Group
*[LDO]: Low Dropout (Regulator)
*[LED]: Light Emitting Diode
*[LEO]:  Low Earth Orbit
<!-- *[LiPo]: Lithium-Ion Polymer or Lithium-Polymer (see glossary-alt.md) -->
*[LoRa]: Long Range
*[LoRaWAN]: Long Range Wide Area Network
*[MCU]: Microcontroller Unit
*[MEO]:  Medium Earth Orbit
*[MISO]: Master In Slave Out
*[MOSI]: Master Out Slave In
<!-- *[MPU]: Memory Protection Unit or Microprocessing Unit (see glossary-alt.md) -->
*[NavIC]: Navigation with Indian Constellation
*[NMEA]: National Marine Electronics Association
*[NiCd]: Nickel-Cadmium
*[NiMH]: Nickel-Metal Hydride
*[NTFS]: New Technology File System
*[NTRIP]: Networked Transport of RTCM via Internet Protocol
*[PCB]: Printed Circuit Board
*[PICO]: Peripheral In; Ccontroller Out
*[POCI]: Peripheral Out; Controller In
*[PSK]: Phase-Shift Keying
*[PWM]: Pulse Width Modulation
*[QSPI]: Quad-SPI
*[QPSK]: Quadrature Phase-Shift Keying
*[QZSS]: Quasi-Zenith Satellite System
*[RAM]: Random-Access Memory
*[RGB]: Red, Green, Blue
*[RINEX]: Receiver Independent Exchange (Format)
*[RST]: Reset
*[RTC]: Realtime Clock
*[RTCM]: Radio Technical Commission for Maritime (Services)
*[RTK]: Real-Time Kinematic (Positioning)
*[RTS]: Ready-to-Send
*[RX]: Receive
*[SBAS]: Satellite-Based Augmentation System
*[SCK]: Serial Clock
*[SCL]: Serial Clock
*[SD]: Secure Digital
*[SDA]: Serial Data
*[SDHC]: Secure Digital High Capacity
*[SDI]: Serial Data In
*[SDIO]: Serial Data In/Out
*[SDO]: Serial Data Out
*[SDUC]: Secure Digital Ultra Capacity
*[SDXC]: Secure Digital Extended Capacity
*[SPI]: Serial Peripheral Interface
*[SRAM]: Static Random-Access Memory
*[SS]: Slave Select
*[SWCLK]: Serial Wire Clock
*[SWD]: Serial Wire Debug
*[SWDIO]: Serial Wire Data Input/Output
*[SWO]: Serial Wire Output
*[SWV]: Serial Wire Viewer
*[TCK]: Test Clock
*[TDI]: Test Data In
*[TDO]: Test Data Out
*[TMS]: Test Mode Select
*[TRST]: Test Reset
*[TX]: Transmit
*[UART]: Universal Asynchronous Receiver-Transmitter
*[USB]: Universal Serial Bus
*[WDT]: Watchdog Timer

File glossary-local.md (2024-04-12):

<!-- Local - Specific to ONLY this Documentation -->
<!-- ------------------------------------------- -->

*[EN]: Enable
*[FSP]: Flexible Software Package

<!-- ------------------------------------------- -->
<!-- -------------- End of Local --------------- -->

<!-- ------------ Standard Entries ------------- -->
<!-- ------------------------------------------- -->

*[GEO]: Geostationary Orbit
<!-- *[GEO]: Geosynchronous Equatorial Orbit -->
*[I2C]: Inter-Integrated Circuit
<!-- *[I<sup>2</sup>C]: Inter-Integrated Circuit -->
*[LiPo]: Lithium-Ion Polymer
<!-- *[LiPo]: Lithium-Polymer -->
<!-- *[MPU]: Microprocessing Unit -->
*[MPU]: Memory Protection Unit

<!-- ------------------------------------------- -->
<!-- --------- End of Standard Entries --------- -->

<!-- ------------------ Units ------------------ -->
<!-- ------------------------------------------- -->

<!-- *[Hz]: Hertz -->
<!-- *[MHz]: Megahertz -->
<!-- *[GHz]: Gigahertz -->

<!-- *[mm]: millimeters -->
<!-- *[km]: kilometers -->
<!-- *[in]: inches -->
<!-- *[ft]: feet -->
<!-- *[yrd]: yards -->
<!-- *[mi]: miles -->

<!-- *[Pa]: Pascals -->

<!-- *[°C]: Degrees Celsius -->
<!-- *[°F]: Degrees Fahrenheit -->

<!-- *[pA]: Picoamp -->
<!-- *[nA]: Nanoamp -->
<!-- *[µA]: Microamp -->
<!-- *[mA]: Milliamp -->

<!-- *[µV]: Microvolt -->
<!-- *[mV]: Millivolt -->

<!-- --------------- End of Units -------------- -->
<!-- ------------------------------------------- -->

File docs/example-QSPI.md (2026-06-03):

---
icon: simple/arduino
---

## MX25L12833F
The Renesas-Arduino core includes a built-in [FATFileSystem library](https://github.com/arduino/ArduinoCore-renesas/tree/main/libraries/FATFilesystem) to control the QSPI flash memory. This example code demonstrates how to initialize the flash memory, a file is written, and data is read from the file. *Users can also find other example sketches in the **File** > **Examples** > **Storage** drop-down menu.*

??? code "`QSPI_Flash_FileSystem_Test.ino`"
	--8<-- "https://raw.githubusercontent.com/arduino/docs-content/main/content/hardware/04.pro/boards/portenta-c33/tutorials/user-manual/content.md:1365:1450"

--8<-- "https://raw.githubusercontent.com/arduino/docs-content/main/content/hardware/04.pro/boards/portenta-c33/tutorials/user-manual/content.md:1454:1454"

	??? code
		```cpp
		--8<-- "https://raw.githubusercontent.com/arduino/docs-content/main/content/hardware/04.pro/boards/portenta-c33/tutorials/user-manual/content.md:1401:1411"
		```

--8<-- "https://raw.githubusercontent.com/arduino/docs-content/main/content/hardware/04.pro/boards/portenta-c33/tutorials/user-manual/content.md:1455:1455"

	??? code
		```cpp
		--8<-- "https://raw.githubusercontent.com/arduino/docs-content/main/content/hardware/04.pro/boards/portenta-c33/tutorials/user-manual/content.md:1414:1428"
		```

--8<-- "https://raw.githubusercontent.com/arduino/docs-content/main/content/hardware/04.pro/boards/portenta-c33/tutorials/user-manual/content.md:1456:1456"

	??? code
		```cpp
		--8<-- "https://raw.githubusercontent.com/arduino/docs-content/main/content/hardware/04.pro/boards/portenta-c33/tutorials/user-manual/content.md:1430:1446"
		```

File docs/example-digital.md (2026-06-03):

---
icon: simple/arduino
---

## Digital Output
LEDs are a perfect visual indicator for the operation of a digital output.

### LED - Blink

Below, is one of the simplest built-in examples of the Arduino IDE. Users can find this sketch in the **File** > **Examples** > **01.Basics** > **Blink** drop-down menu. The example toggles the digital output of the GPIO pin connected to the blue, `STAT` *(status)* LED.

!!! tip
	Users do not have to worry about modifying the sketch for the GPIO pin that is connected to the `STAT` LED. The pin is already defined in the Arduino core with the `LED_BUILTIN` variable. Therefore, no adjustments are necessary to utilize this example code.

??? code "`Blink.ino`"
	--8<-- "https://raw.githubusercontent.com/arduino/docs-content/main/content/built-in-examples/01.basics/Blink/Blink.md:89:89"

### LED - PWM
LEDs are also great visual indicators for PWM outputs.

On the RA6M5 Thing Plus, the GPIO pin connected to the `STAT` LED is also capable of generating a PWM output. There are two built-in examples in the Arduino IDE for operating a PWM output on an LED. The sketches operate by oscillating the duty cycle of the PWM signal from the GPIO pin so that the LED appears to be dimming or *fading*.

!!! tip
	Users will need to modify the sketches below, for the GPIO pin that is connected to the `STAT` LED. As mentioned in the example above, they can use the predefined `LED_BUILTIN` variable. Users will need to {--replace the highlighted line--} with the {++modification using the `LED_BUILTIN` variable++} to define the GPIO pin connected to the `STAT` LED.

	<div class="grid" markdown>

	<div markdown>

	!!! code "`Fade.ino`"
				int led = {--9;         // the PWM pin the LED is attached to--}
				int led = {++LED_BUILTIN; // the PWM pin the LED is attached to++}

	</div>

	<div markdown>

	!!! code "`Fading.ino`"
				int ledPin = {--9;  // LED connected to digital pin 9--}
				int ledPin = {++LED_BUILTIN;  // LED connected to digital pin 14++}

	</div>

	</div>

=== "`Fade.ino`"
	Users can find this sketch in the **File** > **Examples** > **01.Basics** > **Fade** drop-down menu.

	??? code "`Fade.ino`"
		--8<-- "https://raw.githubusercontent.com/arduino/docs-content/main/content/built-in-examples/01.basics/Fade/Fade.md:52:52"

=== "`Fading.ino`"
	Users can find this sketch in the **File** > **Examples** > **03.Analog** > **Fading** drop-down menu.

	!!! warning "PWM &ne; Analog"
		Although this example is listed under the **03.Analog** menu, users should keep in mind that a PWM output is not a **true** analog signal. PWM signals can only *emulate an analog output*, based on the average voltage output of their square waveform.

	??? code "`Fading.ino`"
		<iframe class='arduino-sketch-iframe' src='https://create.arduino.cc/example/builtin/03.Analog%5CFading/Fading/preview?embed&snippet' style='height:752px;width:100%;margin:10px 0' frameborder='0'></iframe>

### LED - WS2812
!!! warning
	Support for the new Renesas Arduino boards has not been officially released for the FastLED Arduino library. Users should follow the [installation steps](../software_overview-arduino/#ws2812-rgb-led) documented in the **Software Overview**.

The **WS2812** is an addressable RGB LED that operates with a digital signal that stacks frames of 24-bit data, per LED in a chain. We recommend that the [FastLED Arduino library](https://github.com/FastLED/FastLED/) be utilized in the Arduino IDE, to control the RGB LED on the RA6M5 Thing Plus. Once the [library is installed in the Arduino IDE](../software_overview-arduino/#ws2812-rgb-led), users will find several example sketches listed in the **File** > **Examples** > **FastLED** > drop-down menu. We recommend the following examples for users to get started:

- `Blink.ino`
- `ColorTemperature.ino`
- `ColorPalette.ino`

!!! tip
	Below, are a few tips for users to start working with the FastLED Arduino library. However, for more details, users should refer to the [documentation for the FastLED Arduino library](https://fastled.io/docs/index.html).

	??? code "Define Parameters"
		When utilizing the examples in the FastLED Arduino library, users may need to define and/or modify a few parameters:

		```cpp
		// GPIO pins connected to the LED
		#define LED_PIN      LED_RGB // (1)!
		// #define CLOCK_PIN      13 (2)

		// Information about the LED (strip)
		#define NUM_LEDS    1        // (3)!
		#define CHIPSET     WS2812   // (4)!
		#define COLOR_ORDER GRB      // (5)!

		// Define the array of leds
		CRGB leds[NUM_LEDS];

		// 
		#define BRIGHTNESS  40       // (6)!
		```
	
		1. For the RA6M5 Thing Plus, users can either refer to the predefined variable `LED_RGB` or define the pin as `13` *(`D13`)* for the RGB LED
		1. A **clock pin is not required** for the WS2812 LED on the RA6M5 Thing Plus; comment out any mentions of it
		1. On the RA6M5 Thing Plus, there is only **one** RGB LED included on the board
		1. The RGB LED on the RA6M5 Thing Plus is a **WS2812** LED
		1. The format of the color order in the WS2812's data frames is Green, Red, Blue *(**GRB**)*
		1. Some of the examples may define an LED brightness; this should be an 8-bit value *(`0`-`255`)*. Below, is a table of reference values for users to get started with:
	
			| Environment     | Description | Value |
			| :-------------: | :---------- | :---: |
			| Dark Room       | Start to see primary colors | `5` - `12`    |
			| Direct Sunlight | Start to see primary colors | **>** `60`    |
			| Direct Sunlight | Start to see color blending | `100` - `180` |
			| Direct Sunlight | Decent color blending       | **>** `230`   |

	??? code "Instantiate LED Controller"
		Most of the examples in the FastLED library predefine parameters for the LED *(strip)*, as shown above. Later in the sketches, an instance of the [LED controller](https://fastled.io/docs/class_c_l_e_d_controller.html) is created; therefore, if users have already modified all the parameters above, no other modifications should be necessary:

		```cpp
		FastLED.addLeds<CHIPSET, LED_PIN, COLOR_ORDER>(leds, NUM_LEDS);
		```

		Otherwise, users will need to locate where the instance of the [LED controller](https://fastled.io/docs/class_c_l_e_d_controller.html) is created and provide the required values. Users will also need to [configure the LED brightness](https://fastled.io/docs/class_c_fast_l_e_d.html#a730ba7d967e882b4b893689cf333b2eb) later in the sketch, if that predefined variable isn't provided either:

			FastLED.addLeds<{==WS2812==}, {==13==}, GRB>(leds, {==1==});
			FastLED.setBrightness({==<value>==});

		The example code should still [enumerate the order of the RGB color channels](https://fastled.io/docs/group___pixel_types.html#ga3c26d076773aa0f331d3066b46dbc6a4), required for the data frames of the LED chipset. However, users may need to modify the enumerator to `GRB`:

		```cpp	
		#define COLOR_ORDER GRB
		```

=== "`Blink.ino`"
	Users can find this sketch in the **File** > **Examples** > **FastLED** > **Blink** drop-down menu.

	??? code "`Blink.ino`"
		```cpp
		--8<-- "https://raw.githubusercontent.com/FastLED/FastLED/master/examples/Blink/Blink.ino"
		```

=== "`ColorTemperature.ino`"
	Users can find this sketch in the **File** > **Examples** > **FastLED** > **ColorTemperature** drop-down menu.

	??? code "`ColorTemperature.ino`"
		```cpp
		--8<-- "https://raw.githubusercontent.com/FastLED/FastLED/master/examples/ColorTemperature/ColorTemperature.ino"
		```

=== "`ColorPalette.ino`"
	Users can find this sketch in the **File** > **Examples** > **FastLED** > **ColorPalette** drop-down menu.

	??? code "`ColorPalette.ino`"
		```cpp
		--8<-- "https://raw.githubusercontent.com/FastLED/FastLED/master/examples/ColorPalette/ColorPalette.ino"
		```

=== "Sunlight Test"
	This sketch allows users to test the brightness of the WS2812 RGB LED on the RA6M5 Thing Plus in direct sunlight. The sketch implements an interrupt on the ++"USRBTN"++ button to increase the brightness of the LED in increments. The brightness value is then displayed on the [Qwiic OLED Display](https://www.sparkfun.com/products/24606), which is connected by a [Qwiic cable](https://www.sparkfun.com/products/17260).

	??? note "Optional Hardware"
		<div class="grid cards" markdown>

		-   <a href="https://www.sparkfun.com/products/17260">
			<figure markdown>
			Product Thumbnail
			</figure>

			---

			**Flexible Qwiic Cable - 50mm**<br>
			PRT-17260</a>

		-   <a href="https://www.sparkfun.com/products/24606">
			<figure markdown>
			Product Thumbnail
			</figure>

			---

			**SparkFun Qwiic OLED Display (0.91 in., 128x32)**<br>
			LCD-24606</a>

		</div>

	The example code can be found in the [GitHub repository](https://github.com/sparkfun/SparkFun_Thing_Plus_RA6M5/tree/main/docs/assets/arduino_examples/RGB_sunlight/RGB_sunlight.ino). However, users can simply click the button to download the code or expand the box *(below)* to copy the code.

	??? code "`RGB_sunlight.ino`"
		```cpp
		--8<-- "./assets/arduino_examples/RGB_sunlight/RGB_sunlight.ino"
		```

	<article style="text-align: center;" markdown>
	[:octicons-download-16:{ .heart } Download the Example Sketch](./assets/arduino_examples/RGB_sunlight/RGB_sunlight.ino){ .md-button .md-button--primary }
	</article>

*For more information, please refer to the [WS2812 datasheet](./assets/component_documentation/WS2812C-2020.pdf) and [FastLED Arduino library](https://github.com/FastLED/FastLED/).*

## Digital Input
Buttons are great for learning about digital inputs; and are often paired with LEDs, as a visual indicator for their operation.

### Button - ++"USRBTN"++
On the RA6M5 Thing Plus, the ++"USRBTN"++ button is the perfect component for operating a digital input. There are several built-in examples in the Arduino IDE for the basic use of a button as an input device. These examples utilize a digital intput to toggle an LED and/or generate an output text on the USB serial port. Users can find these sketches in the **File** > **Examples** > **01.Basics** > **DigitalReadSerial**  and **File** > **Examples** > **02.Digital** drop-down menus.

- `DigitalReadSerial.ino`
- `Button.ino`
- `Debounce.ino`
- `InputPullupSerial.ino`

!!! tip
	Users will need to modify the sketches below, for the GPIO pin that is connected to the `STAT` LED and ++"USRBTN"++. As previously, they can use the predefined `LED_BUILTIN` variable for the GPIO pin that is connected to the `STAT` LED. For the GPIO pin that is connected to the ++"USRBTN"++, users till need to modify the pin to `D31`.

	For more details, expand the boxes below to see the {++modifications++} that required to {--replace the highlighted values--}, in order to define the GPIO pins connected to the `STAT` LEDand ++"USRBTN"++

	<div class="grid" markdown>

	<div markdown>

	??? code "++"USRBTN"++"
		`DigitalReadSerial.ino`

		---

			int pushButton = {--2--};
			int pushButton = {++31++};

		`Button.ino` and `Debounce.ino`

		---

			const int buttonPin = {--2--};  // the number of the pushbutton pin
			const int buttonPin = {++31++};  // the number of the pushbutton pin

		`InputPullupSerial.ino`

		---

			pinMode({--2--}, INPUT_PULLUP);
			pinMode({++31++}, INPUT_PULLUP);

			int sensorVal = digitalRead({--2--});
			int sensorVal = digitalRead({++31++});

	</div>

	<div markdown>

	??? code "`STAT` LED"
		`Button.ino` and `Debounce.ino`

		---

			const int ledPin = {--13--};    // the number of the LED pin
			const int ledPin = {++LED_BUILTIN++};    // the number of the LED pin

		`InputPullupSerial.ino`

		---

			pinMode({--13--}, OUTPUT);
			digitalWrite({--13--}, value);

			pinMode({++LED_BUILTIN++}, OUTPUT);
			digitalWrite({++LED_BUILTIN++}, value);

	</div>

	</div>

=== "`DigitalReadSerial.ino`"
	Users can find this sketch in the **File** > **Examples** > **01.Basics** > **DigitalReadSerial** drop-down menu.

	??? code "`DigitalReadSerial.ino`"
		--8<-- "https://raw.githubusercontent.com/arduino/docs-content/main/content/built-in-examples/01.basics/DigitalReadSerial/DigitalReadSerial.md:65:65"

=== "`Button.ino`"
	Users can find this sketch in the **File** > **Examples** > **02.Digital** > **Button** drop-down menu.

	??? code "`Button.ino`"
		--8<-- "https://raw.githubusercontent.com/arduino/docs-content/main/content/built-in-examples/02.digital/Button/Button.md:45:45"

=== "`Debounce.ino`"
	Users can find this sketch in the **File** > **Examples** > **02.Digital** > **Debounce** drop-down menu.

	??? code "`Debounce.ino`"
		--8<-- "https://raw.githubusercontent.com/arduino/docs-content/main/content/built-in-examples/02.digital/Debounce/Debounce.md:41:41"

=== "`InputPullupSerial.ino`"
	Users can find this sketch in the **File** > **Examples** > **02.Digital** > **InputPullupSerial** drop-down menu.

	??? code "`InputPullupSerial.ino`"
		--8<-- "https://raw.githubusercontent.com/arduino/docs-content/main/content/built-in-examples/02.digital/InputPullupSerial/InputPullupSerial.md:68:68"
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

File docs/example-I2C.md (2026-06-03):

---
icon: simple/arduino
---

## Device Scan
This sketch allows users to scan for devices connected to the primary I^2^C bus of the RAM5 Thing Plus. The example code can be found in the [GitHub repository](https://github.com/sparkfun/SparkFun_Thing_Plus_RA6M5/tree/main/docs/assets/arduino_examples/i2c_scanner/i2c_scanner.ino). However, users can also simply click on the button *(below)*, to download the code; or expand the box *(below)*, to copy the code.

??? code "`i2c_scanner.ino`"
	```cpp
	--8<-- "./assets/arduino_examples/i2c_scanner/i2c_scanner.ino"
	```

<article style="text-align: center;" markdown>
[:octicons-download-16:{ .heart } Download the Example Sketch](./assets/arduino_examples/i2c_scanner/i2c_scanner.ino){ .md-button .md-button--primary }
</article>

## Peripheral Devices
The RA6M5 Thing Plus features a Qwiic connector to seamlessly integrate with devices from [SparkFun's Qwiic Ecosystem](https://www.sparkfun.com/qwiic). While users are free to utilize any I^2^C device, we recommend the [Qwiic devices](https://www.sparkfun.com/categories/399) from our catalog.

??? note "Optional Hardware"
	<div class="grid cards" markdown>

	-   <a href="https://www.sparkfun.com/products/15081">
		<figure markdown>
		Product Thumbnail
		</figure>

		---

		**SparkFun Qwiic Cable Kit**<br>
		KIT-15081</a>
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

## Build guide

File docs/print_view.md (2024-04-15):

---
hide:
  - navigation
  - toc
icon: material/printer
---

--8<-- "./introduction.md:5"

# Hardware Overview
--8<-- "./hardware_overview.md:5"

# Hardware Assembly
--8<-- "./hardware_assembly.md:5"

# Software Overview - Arduino IDE
--8<-- "./software_overview-arduino.md:5"

# Software Overview - CodeLess AT Commands
--8<-- "./software_overview-codeless.md:5"

# Examples - Digital I/O
--8<-- "./example-digital.md:5"

# Examples - Analog I/O
--8<-- "./example-analog.md:5"

# Examples - Serial Port
--8<-- "./example-serial.md:5"

# Examples - SPI Bus
--8<-- "./example-SPI.md:5"

# Examples - I^2^C Bus
--8<-- "./example-I2C.md:5"

# Examples - Memory/Storage
--8<-- "./example-SD_card.md:5"
--8<-- "./example-QSPI.md:5"

# Examples - :material-bluetooth: CodeLess
--8<-- "./example-codeless.md:5"

# Resources
--8<-- "./resources.md:5"

# Troubleshooting Tips
--8<-- "./troubleshooting_tips.md:5"

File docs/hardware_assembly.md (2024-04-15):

---
icon: material/tools
---

## USB Connector
The USB connection is utilized for programming and serial communication. Users only need to plug their RA6M5 Thing Plus into a computer using a USB-C cable.

<figure markdown>
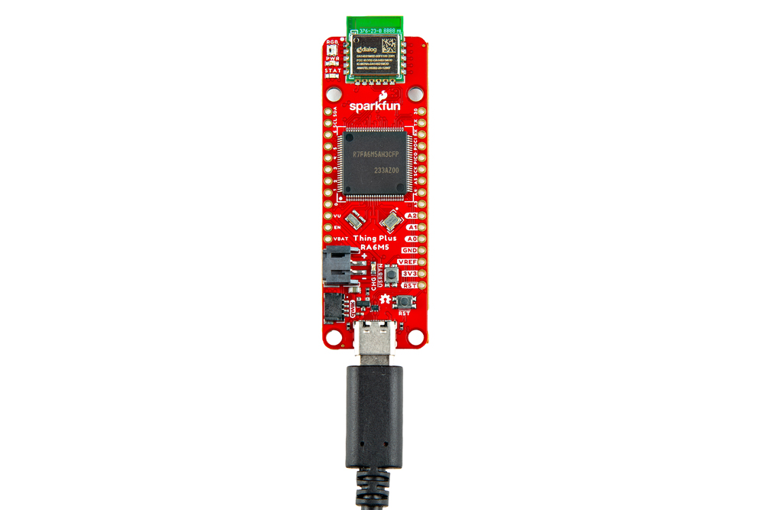
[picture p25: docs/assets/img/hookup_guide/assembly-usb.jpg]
USB connection

<figcaption markdown>The RA6M5 Thing Plus with USB-C cable attached.</figcaption>
</figure>

## LiPo Battery
For remote IoT applications, a LiPo battery can be connected. Additionally, users may be interested in utilizing a [solar panel](https://www.sparkfun.com/products/16835) and [USB-C cable](https://www.sparkfun.com/products/14743) to recharge their battery.

<div class="grid cards" markdown>

<div markdown>

<figure markdown>
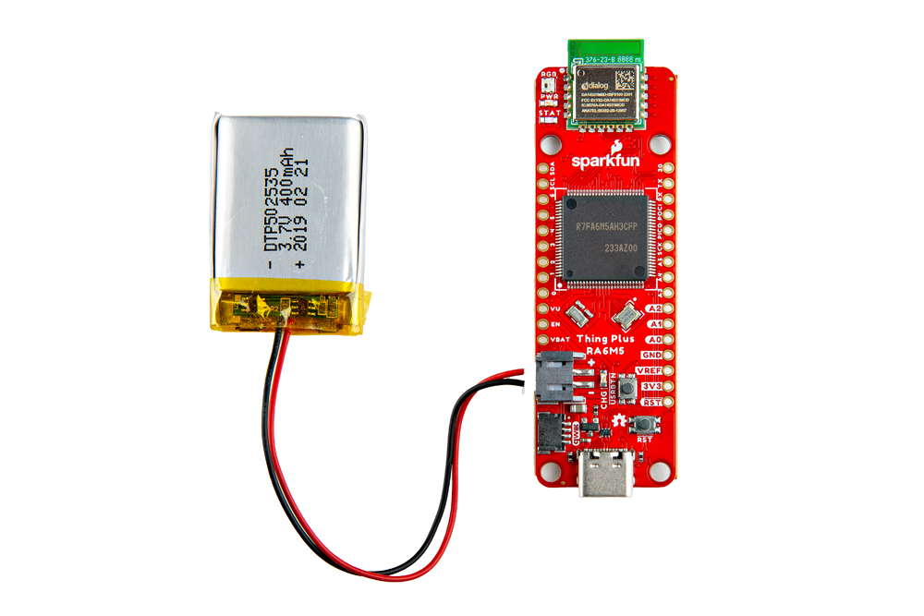
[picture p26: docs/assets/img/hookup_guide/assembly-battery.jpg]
Battery connected to the RA6M5 Thing Plus

<figcaption markdown>The RA6M5 Thing Plus with a battery connected.</figcaption>
</figure>

</div>

-   <a href="https://www.sparkfun.com/products/16835">
	<figure markdown>
	Product Thumbnail
	</figure>		

	---

	**Solar Panel Charger - 10W**<br>
	TOL-16835</a>

-   <a href="https://www.sparkfun.com/products/14743">
	<figure markdown>
	Product Thumbnail
	</figure>		

	---

	**USB 3.1 Cable A to C - 3 Foot**<br>
	TOL-14743</a>

</div>

!!! warning
	Users should avoid pulling on the wires of a battery to disconnect it from the board. Instead, it is recommended that a pair of dikes (i.e. diagonal wire cutters), pliers, or tweezers be used to pull on the JST connector housing, to avoid damaging the battery wiring.

	<figure markdown>
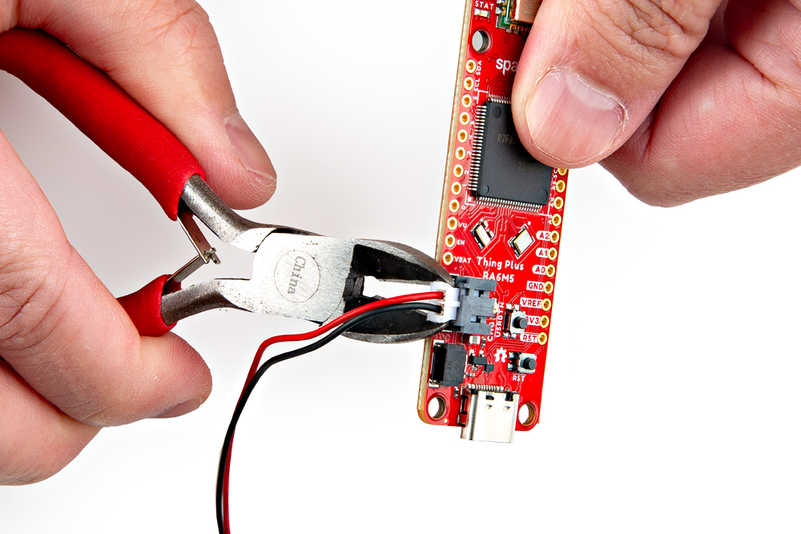
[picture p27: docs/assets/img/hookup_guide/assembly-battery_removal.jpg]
Disconnect battery w/ dikes
	
	<figcaption markdown>Using a pair of dikes to disconnect a battery.</figcaption>
	</figure>

## Breakout Pins
The [PTH](https://en.wikipedia.org/wiki/Through-hole_technology "Plated Through Holes") pins on the RA6M5 Thing Plus are broken out into 0.1"-spaced pins on the edges of the board.

??? tip "New to soldering?"
	If you have never soldered before or need a quick refresher, check out our [How to Solder: Through-Hole Soldering](https://learn.sparkfun.com/tutorials/how-to-solder-through-hole-soldering) guide.

	<div class="grid cards col-4" markdown align="center">

	-   <a href="https://learn.sparkfun.com/tutorials/5">
		<figure markdown>
		Tutorial thumbnail
		</figure>

		---
		
		**How to Solder: Through-Hole Soldering**</a>

	</div>

<div class="grid" markdown>

<div markdown>

### Headers

Headers are versatile in their compatibility with shields, breadboards, or jumper wires.

<figure markdown>
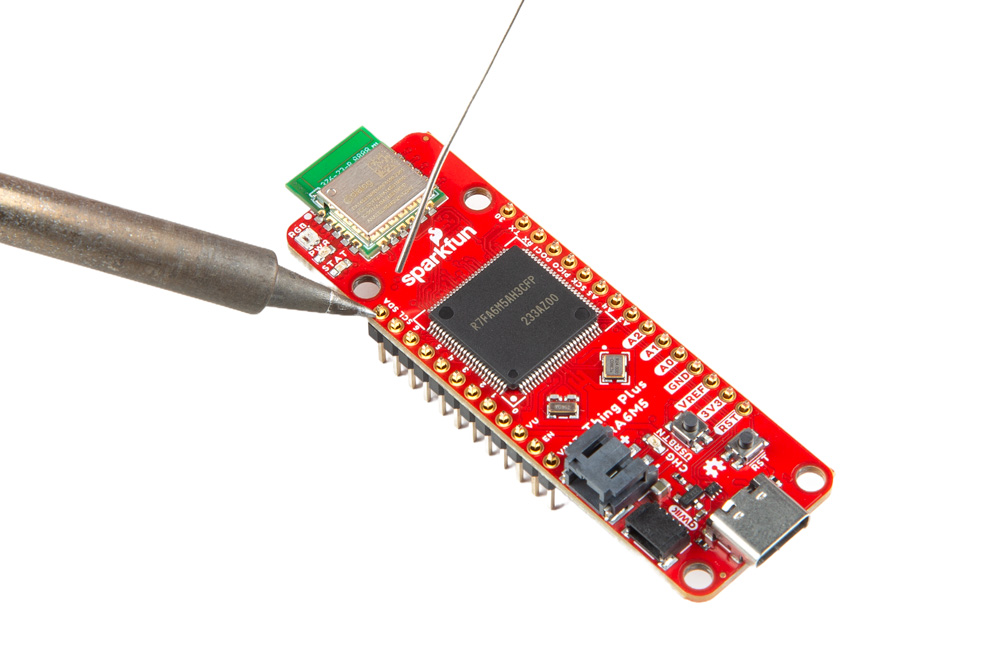
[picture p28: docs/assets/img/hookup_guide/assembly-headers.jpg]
Soldering headers

<figcaption markdown>Soldering headers to the RA6M5 Thing Plus.</figcaption>
</figure>

??? tip "Stackable Headers"
	Our [Feather Stackable Header Kit](https://www.sparkfun.com/products/15187) is a great option for stacking on shields *(w/ Feather footprint)* or on a breadboard; while leaving its pins still accessible.

	<figure markdown>
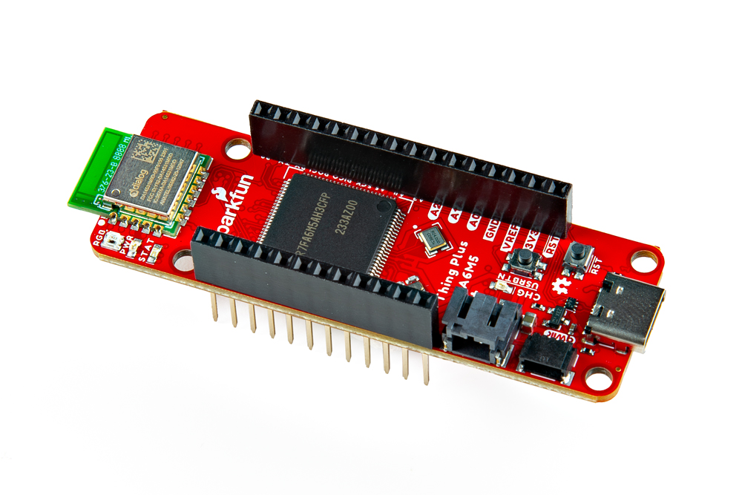
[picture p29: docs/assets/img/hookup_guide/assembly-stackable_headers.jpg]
Stackable Headers
	
	<figcaption markdown>Stackable headers on the RA6M5 Thing Plus.</figcaption>
	</figure>

</div>

<div markdown>

### Hookup Wires

For a more permanent connection, users can solder wires directly to the board.

<figure markdown>
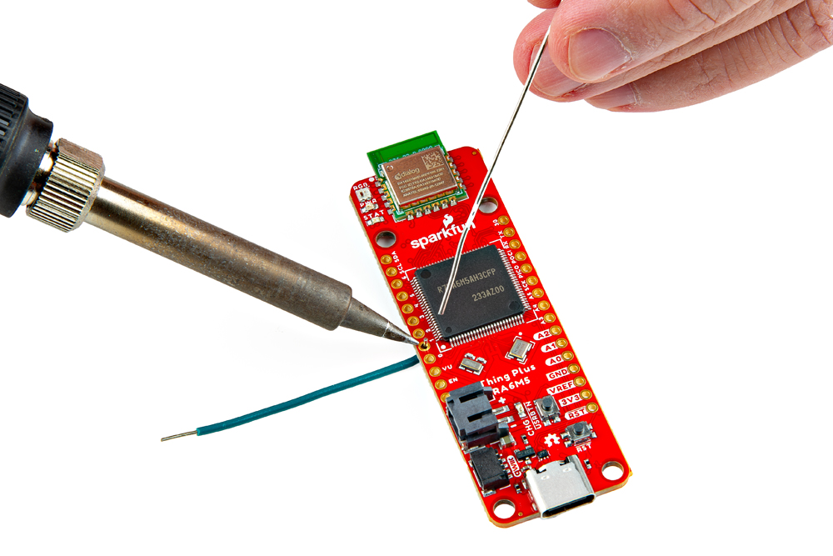
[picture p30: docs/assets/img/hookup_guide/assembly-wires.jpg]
Soldering wires

<figcaption markdown>Soldering wires to the RA6M5 Thing Plus.</figcaption>
</figure>

</div>

</div>

## SD Card Slot
The RA6M5 Thing Plus includes a &micro;SD card slot on the back of the board. The cardholder functions through a push/pull operation. *(The card slot doesn't include a spring retention mechanism; cards are held in place through friction.)*

<figure markdown>
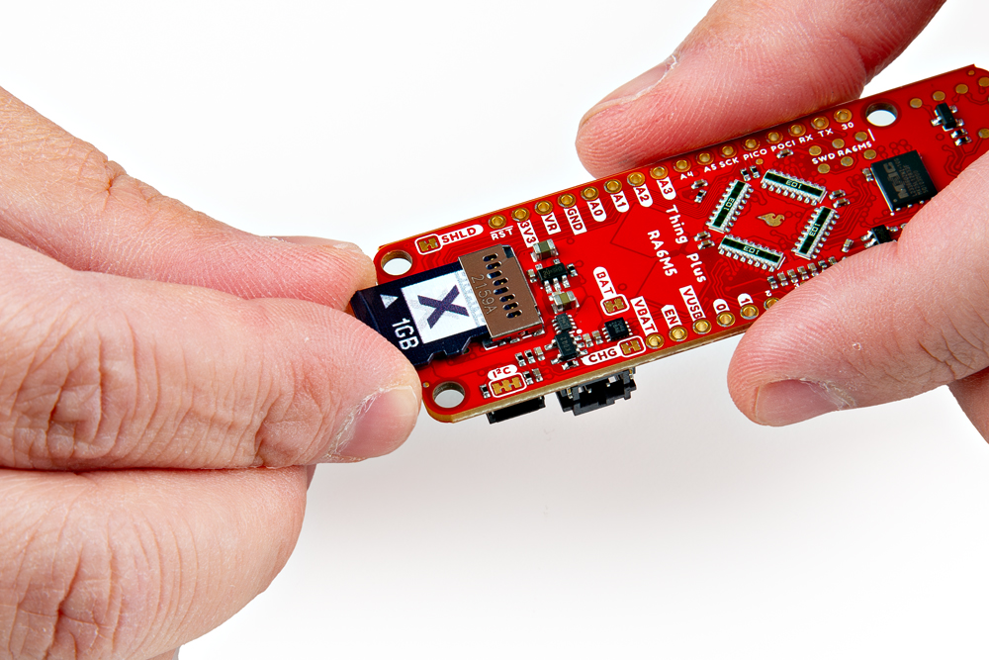
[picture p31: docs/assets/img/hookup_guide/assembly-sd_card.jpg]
Inseting an SD card

<figcaption markdown>Users can slide-in or pull-out a &micro;SD card from the cardholder.</figcaption>
</figure>

!!! info "SD Card Compatibility"
	The R6M5 Thing Plus supports &micro;SD cards with a **FAT32** file system *(i.e. only cards **up to 32GB** in size)*.

## Qwiic Devices
The Qwiic system allows users to effortlessly prototype with a Qwiic compatible I^2^C device without soldering. Users can attach any Qwiic compatible [sensor or board](https://www.sparkfun.com/qwiic#sensors), with just a [Qwiic cable](https://www.sparkfun.com/products/15081). (*\*The example below, is for demonstration purposes and is not pertinent to the board functionality or this tutorial.*)

<figure markdown>
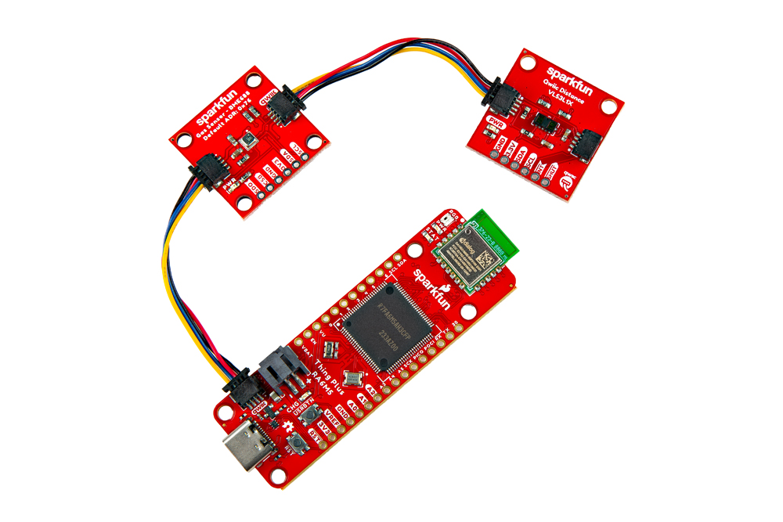
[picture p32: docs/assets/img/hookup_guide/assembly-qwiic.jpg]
Qwiic devices connected to RA6M5 Thing Plus

<figcaption markdown>The [BME688 environmental](https://www.sparkfun.com/products/19096) and [VL53L1X distance](https://www.sparkfun.com/products/14722) Qwiic sensor boards connected to the RA6M5 Thing Plus.</figcaption>
</figure>

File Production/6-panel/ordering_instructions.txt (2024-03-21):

panel size, 84x169mm
PCB thickness, 1.6mm
number of layers, 6
material, TG155
soldermask color, Red
silkscreen color, White
oz copper, 1oz
finish, ENIG
stencils, top+bottom
pcs per panel, 6
min trace width, 0.1200mm / 0.0047in
min drill size, 0.2000mm / 0.0079in
filename to layer stackup 1/2/3/4/5/6: GTL, GL2, GL3, GL4, GL5, GBL

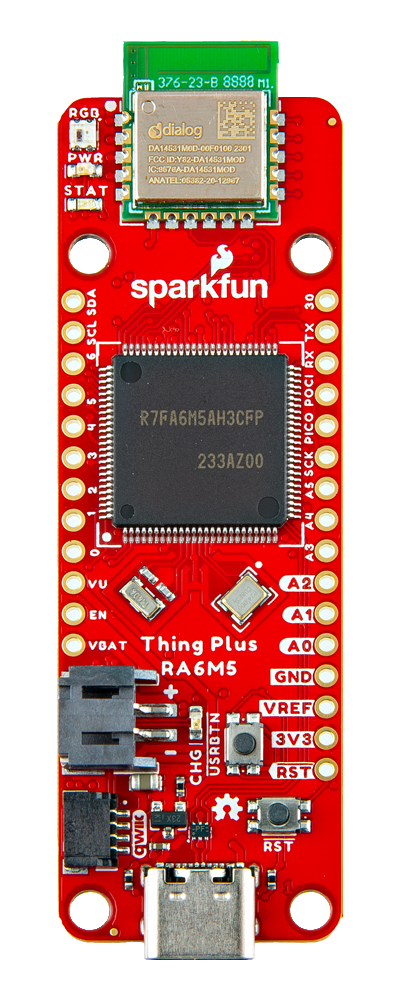
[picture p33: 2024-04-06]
docs/assets/img/hookup_guide/top.png

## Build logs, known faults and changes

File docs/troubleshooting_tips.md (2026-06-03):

---
icon: sfe-logo
---

!!! warning "Need Help?"
	If you need technical assistance or more information on a product that is not working as you expected, we recommend heading over to the [SparkFun Technical Assistance](https://www.sparkfun.com/technical_assistance) page for some initial troubleshooting.

	<article style="text-align: center;" markdown>
	[SparkFun Technical Assistance Page](https://www.sparkfun.com/technical_assistance){ .md-button .md-button--primary }
	</article>

	If you can't find what you need there, the [SparkFun GNSS Forum](https://forum.sparkfun.com/viewforum.php?f=116) is a great place to ask questions.

	!!! info "Account Registration Required"
		If this is your first visit to our forum, you'll need to create a [Forum Account](https://forum.sparkfun.com/ucp.php?mode=register) to post questions.

## Upload Issues
If users have issues during the uploading process, they can try to manually force the board into DFU mode with the reset button. Double-tapping the ++"RST"++ button will force the MCU to into the Device Firmware Update mode. The board will remain in this mode, until it power cycles *(which happens automatically, after uploading new firmware)* or the reset button is pressed.

<div class="grid" markdown>

<div markdown>

1. Double-tap the ++"RST"++ button
	- The `STAT` LED should be fading in/out very slowly
1. Users should now, be able to upload a new program
	- It shouldn't be necessary to select a COM port in the Arduino IDE; only the board needs to be selected
1. Once programming is complete, the MCU should reboot on its own. Otherwise:
	- Press the ++"RST"++ button
	- Power cycle the board

</div>

<div markdown>

<figure markdown>
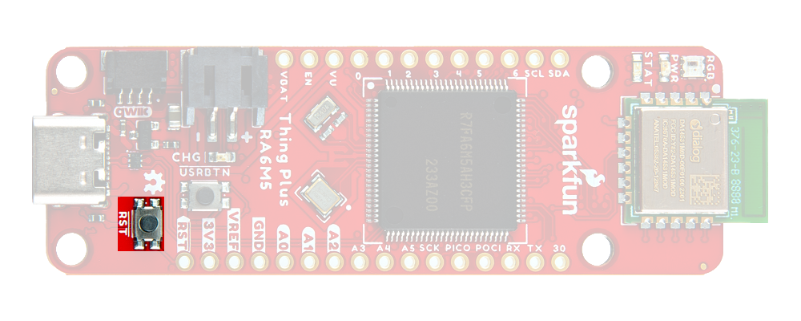
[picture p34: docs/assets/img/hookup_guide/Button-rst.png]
Reset Button

<figcaption markdown>++"RST"++ button on the RA6M5 Thing Plus.</figcaption>
</figure>

</div>

</div>

## Digital I/O

### Utilizing Interrupts
When utilizing an interrupt on a digital GPIO, the attached interrupt service routine should be able to execute within the shortest, possible time frame. Otherwise, the suspended task could trigger various faults or errors.

## &micro;SD Card

### Compatibility
The [FATFileSystem library](https://github.com/arduino/ArduinoCore-renesas/tree/main/libraries/FATFilesystem) built into the Renesas-Arduino core, supports &micro;SD cards with a **FAT32** file system *(i.e. SD cards **up to 32GB** in size)*.

- While users may be able to use cards with a higher storage capacity, we highly advise against it. As users may experience data loss due to a corrupt file system *(i.e. SD cards with a storage capacity greater than 32GB are not meant to be formatted with a FAT32 file system)*.

### Hot Swapping
To avoid corrupting an SD card, users should disable all activity with the SD card and disconnect power before removing it from the RA6M5 Thing Plus.

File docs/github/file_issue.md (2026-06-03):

# Did we make a mistake?

Spot something wrong? Please let us know. 

<!-- Technical Assistance Box -->
!!! warning "Need Help?"
	If you need technical assistance or more information on a product that is not working as you expected, we recommend heading on over to the [SparkFun Technical Assistance](https://www.sparkfun.com/technical_assistanc) page for some initial troubleshooting. This **Submit Issues** page is not where users should seek assistance.

	<article style="text-align: center;" markdown>
	[SparkFun Technical Assistance Page](https://www.sparkfun.com/technical_assistance){ .md-button .md-button--primary }
	</article>

	If you can't find what you need there, the [SparkFun Forums](https://forum.sparkfun.com/index.php) is a great place to search the product forums and ask questions.

	!!! info "Account Registration Required"
		For your first visit to our forum, you'll need to create a [Forum Account](https://forum.sparkfun.com/ucp.php?mode=register) to post questions.

## Discrepancies in the Documentation

All of our documentation can be modified by you! Please help us make it better.

* The documentation files for these pages are contained in the [`docs` folder](https://github.com/sparkfun/SparkFun_Thing_Plus_RA6M5/tree/main/docs) of the [SparkFun RA6M5 Thing Plus repository](https://github.com/sparkfun/SparkFun_Thing_Plus_RA6M5).

### 🔍 Spot something wrong?

If a section of the documentation is incorrect, please [open an issue](https://github.com/sparkfun/SparkFun_Thing_Plus_RA6M5/issues) and let us know.

### Do you have a suggested correction?

1. With a GitHub account, [fork this repository](https://github.com/sparkfun/SparkFun_Thing_Plus_RA6M5/fork).
2. Add your correction(s) or improvement(s) to the markdown file(s)
3. File a pull request with your changes, and enjoy making the ~~words~~ ~~worlds~~ world a better place.
	* Once received, the documentation specialist will automatically be notified.
	* We will review your suggested improvement(s) to make sure they are correct and fit within our documentation standards.

## Problems in the Hardware Design

All of our designs are open-source! Please help us make it better.

* Our board design files are contained in the [`Hardware` folder](https://github.com/sparkfun/SparkFun_Thing_Plus_RA6M5/tree/main/Hardware) of the [SparkFun RA6M5 Thing Plus repository](https://github.com/sparkfun/SparkFun_Thing_Plus_RA6M5).

### Does something not make sense? 🤔

If part of the design is confusing, please [open an issue](https://github.com/sparkfun/SparkFun_Thing_Plus_RA6M5/issues) and let us know.

### Did we forget to include an important function of the board? 🤦

If part of the board's functionality is missing, please [open an issue](https://github.com/sparkfun/SparkFun_Thing_Plus_RA6M5/issues) and file a feature request.

!!! tip "Design Considerations"
	Please keep in mind that we may intentionally exclude certain functions of the board to meet our product design requirements.

	* *For example, our Qwiic Micro boards are intended to fit on a small board layout and only use I^2^C communication; therefore, we may not have the SPI and interrupt pins available for users.*

### Do you wish to contribute directly to improving the board design?

1. With a GitHub account, [fork this repository](https://github.com/sparkfun/SparkFun_Thing_Plus_RA6M5/fork).
2. Add your design augmentation(s)
3. File a pull request with your changes, and enjoy making the ~~words~~ ~~worlds~~ world a better place.
	1. Once received, the engineer in charge of the original design will automatically be notified.
	2. We will review your suggested improvement(s) to verify that they are within our board design standards and meet our product design requirements.
	3. If approved, we will flag these changes for our next board revision. Congrats! 🍻

		!!! info
			Even if your suggestion is accepted, these changes may not be immediately available for purchase. We may have to cycle through our current product inventory first.

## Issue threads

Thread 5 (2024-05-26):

installation instructions incorrect and cause UNOR4 issue

paulvha, 2024-05-26:
### Subject of the issue
I have tried to install the Sparkfun RA6M5 library following the instructions on https://docs.sparkfun.com/SparkFun_Thing_Plus_RA6M5/software_overview-arduino/. These instructions are NOT correct.

### Your workbench
Ubuntu 22.04
Arduino IDE 1.8.16

### Steps to reproduce
It is NOT located at:_./arduino/hardware/renesas_portenta/<version number>/ directory of the packages folder._
BUT ./arduino/hardware/renesas_uno/<version number>/ directory of the packages folder.

Creating a folder with a level higher did not work :
_For example, if the current version is 1.1.0, users can name the new directory 1.2.0. and then copy the  Sparkfun core code in that._
It did not work. After restart of the IDE I only continued to see the original UNOR4's.
I had rename the original 1.1.0 to hidden .1.1.0 and rename the 1.2.0 to 1.1.0. After that restart the IDE.

When now selecting the RA6M5 board it will NOT be at : Tools > Board > Arduino Renesas Portenta Boards > SparkFun Thing Plus RA6M5
but at Tools > Board > Sparkfun Renesas Thing Plus Boards > SparkFun Thing Plus RA6M5

**The really bad news is that I need to rename the 1.1.0 folders in the renesas_uno folder every time I switch between UNOR4 and RA6M5.**

### advice / request
Better instruction would be to use the original Arduino UNOR4 library and add the variant manually.

regards
Paul

santaimpersonator, 2024-05-29:
Having looked into the issue, there are a few problems with the initial information you provided:

- I'd recommend using the latest Arduino IDE *(v`2.x.x`)*.
  - You will run into versioning issues of the Arduino cores within the Arduino IDE `1.x.x` (i.e. it has trouble recognizing new installation versions; that are manually added).
  - Also, the Arduino IDE `1.x.x` is considered legacy software by Arduino. Therefore, we have followed their lead and are pointing users to the latest version (which some of the core *"issues"* of the previous version)
- The wrong Arduino core is being installed. You need to install the Arduino core for the **`Renesas Portenta Boards`**, which is different from the Arduino core of the `UNO R4` boards:
  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

santaimpersonator, 2024-05-29:
To address the incorrect installation instructions, I followed them on an Ubuntu distro. Our instructions worked fine, with a few caveats:

- The Arduino core versioning number issue, as mentioned above for the legacy version of the Arduino IDE.
    -  We recommend using the Arduino IDE `v2.x.x` to avoid the issue; otherwise, you'll need to name the folder with the same version number.
    - This will allow you the option to have multiple version folders in the directory. The Arduino IDE will recognize the latest version number, when opened.
        - While this doesn't address the renaming issue, it does reduce the need to overwrite files each time.
        - Additionally, it will function with the [changes for the FastLED library](http://docs.sparkfun.com/SparkFun_Thing_Plus_RA6M5/software_overview-arduino/#ws2812-rgb-led)
-  We don't include the original `Portenta C33` board in our ported version of the Arduino core. This is an intentional choice we made for the documentation, for several reasons:
    -  The instructions for our *ported* Arduino core, are meant to be temporary.
        - We are currently waiting on a pull request: https://github.com/arduino/ArduinoCore-renesas/pull/290
        - If the *official* Arduino core gets updated w/o our pull request, we'd have to update the ported Arduino core. This adds unnecessary maintenance (for the reason below)
    - The Renesas Arduino core relies on linkers for its USB driver installation and board recognition.
        - This can be seen here: https://github.com/arduino/ArduinoCore-renesas/tree/main/cores/arduino/tinyusb
        - These files would need to be *"rebuilt"* for both boards and be maintained with new releases. Therefore, we chose to simplify our *temporary* port by excluding the original `Portenta C33` board.

santaimpersonator, 2024-05-29:
Finally, to address the issue of having to rename folders. Here is a work around, using a local installation:

> **Note:** You may run into issues with the FastLED library due to how we [added support for our board](http://docs.sparkfun.com/SparkFun_Thing_Plus_RA6M5/software_overview-arduino/#ws2812-rgb-led). The modifications may not be compatible with an Arduino core in a local directory.

- Install the Renesas Arduino core through the **Board Manager** in the Arduino IDE.
    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
- Install our *ported* Arduino core in a local directory: `/home/$USER/Arduino/hardware/`
    - This is part of why we didn't include the `Portenta C33` in the ported Arduino core. However, I didn't included instructions for the *local* installation because wasn't able to verify full functionality at the time of the product release.
    - We used the `/home/$USER/Arduino/hardware/SparkFun/SFE-Renesas-Arduino_core` directory to house our files, with `SFE-Renesas-Arduino_core` as the extracted folder
- Both installations should now be available in the Arduino IDE:
    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

-------

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

santaimpersonator, 2024-05-29:
I have some time to update the Linux instructions with the full directory and `plugdev` group note. However, I am going to hold off on adding the local installation method for now. I just don't have the time to verify the installation method (i.e. peripheral functionality/compilation, additional library compilation, USB upload/board recognition, etc.) on all three operating systems.

paulvha, 2024-05-30:
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

Thanks for all the information. I am going to try and let you know.

I added the RA6M5-folder in the variant folder, add to boards.txt the necessary information from the Sparkfun core file to the UNOR4 library, restart the IDE and it compiles and provides output.

It looks like it is sufficient by providing in the boards.txt file :
thingplus_ra6m5.compiler.tinyusb.cflags=-DCFG_TUSB_MCU=OPT_MCU_RAXXX
thingplus_ra6m5.compiler.tinyusb.cxxflags=-DCFG_TUSB_MCU=OPT_MCU_RAXXX

#define OPT_MCU_RAXXX            1403 ///< Renesas RAxxx families

paulvha, 2024-05-30:
The reason for using 1.8.16 was issues with Teensy (for the Micromod) With V2.x.x. The V1.x library makes IDE V2.x.x hang during startup. There is a new Teensy V2 library to solve that.

I have followed the instructions ( using IDE V2.3.2. / Ubuntu 22.04)
Installed a clean UNOR4 library (no changes applied for the RA6M5)
Installed a clean Portenta library (version 1.1.0)
created a new folder in the Portenta Libray: 1.2.0
copied the Sparkfun core into it.
Restarted the IDE V2.3.2
If I now select the board I can only choose the RA6M5 (different than your picture). I can not select the portenta as in your feedback, But as I don't have any, it is already better for me.

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

I think it would be good to either change the instructions to add the UNOR4  library (see previous feedback) and/or add that these instructions are for the V2.x.x Arduino IDE.

regards,
Paul

santaimpersonator, 2024-05-30:
The reason you are running into this compiler issue is because, of the linkers I mentioned in a previous comment:
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

A previously specified, you can't just copy over the board files and add the variant:
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

santaimpersonator, 2024-05-30:
Not to sound rude, but I feel like parts of my responses were either disregarded, missed, or ignored.
- That said, you are free to do what you like.
    - However, if you continue to do so... this conversation will be moving beyond the scope of our support.
- Otherwise, if you would like to get back on track your can either follow:
    - The [instructions we provide in the hookup guide](http://docs.sparkfun.com/SparkFun_Thing_Plus_RA6M5/software_overview-arduino/#installation)
    - The [workaround I mentioned in a previous comment](https://github.com/sparkfun/SparkFun_Thing_Plus_RA6M5/issues/5#issuecomment-2138368804)

----

> I have followed the instructions ( using IDE V2.3.2. / Ubuntu 22.04)
> Installed a clean UNOR4 library (no changes applied for the RA6M5)

I'm not sure why you are insisting on installing the board definition for the Uno R4.
- We have never mentioned that in any of these instructions or the hookup guide.
- Moving forward, I will be disregarding any further conversation about the Uno R4. It does not pertain to the RA6M5 Thing Plus and is outside the scope of our support.

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

I'm glad this solution worked for you, but you just followed the [instructions we already provided in the hookup guide](http://docs.sparkfun.com/SparkFun_Thing_Plus_RA6M5/software_overview-arduino/#installation). I think, as I previously mentioned... you were utilizing the wrong board definition:
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

> I think it would be good to either change the instructions to add the UNOR4 library (see previous feedback) and/or add that these instructions are for the V2.x.x Arduino IDE.

Regarding your suggestion that we update our instructions to your method (utilizing the Uno R4 board definition/Arduino core), will not be taken into consideration. While this solution works for you; it is no different that replacing the Arduino Renesas core of the Portenta boards... which we already provide instructions for. Additionally, the Portenta boards also utilize the same chipset as the RA6M5 Thing Plus.

santaimpersonator, 2024-05-30:
I'm closing this issue for the following reasons:
- Our original instructions in the hookup guide worked for you
- The Uno R4, uses a different chipset; unlike the Portenta boards.

*That said.... when I get a chance, I will update the hookup guide for the few extra Linux steps. Additionally, I provide an image for selecting the Arduino Renesas **Portenta** boards, in the board manager to be extra clear about that step.

Closed 2024-05-30.

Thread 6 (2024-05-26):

Serial is dropping bytes

paulvha, 2024-05-26:
### Subject of the issue
I tried to connect my SPS30 to Serial1 on the RA6M5 but could not get it to work. It turned out that the FIRST receive byte (0x7E) from the SPS30 on RA6M5 Serial1 is lost all the time after reset. But further investigation showed it is worse and it is losing bytes at random.

### Your workbench
RA6M5 Sparkfun
Artemis Apollo3 ATP
Ubuntu 22.04
Arduino IDE 1.8.16

### Steps to reproduce
To diagnose/reproduce I have created 2 sketches. (included **[sketches.zip](https://github.com/sparkfun/SparkFun_Thing_Plus_RA6M5/files/15447428/sketches.zip)**)
One for the RA6M5 (RA6M5.ino) and one for another board. As I used an Artemis ATP I will refer as ATP ( ATP.ino).

Using the core files provided by Sparkfun.
Connect the RA6M5-TX1 to the ATP-RX1, the RA6M5-RX1 to the ATP-TX1 and GND-GND.
Compile the RA6M5.ino on the RA6M5 and the ATP.ino on the ATP.

When you press enter on the RA6M5, a sequence of 6 HEX-bytes (7E 1 2 3 4 7E ) is sent to the ATP. When the ATP has received 2 times '0x7E' it will respond with a different sequence of 6 HEX-bytes.(7E 5 6 7 8 7E) The sending and received bytes are displayed in both sketches.

**After a reset of the RA6M5 it will ALWAYS miss receiving the first byte (0x7E) the first time around.**

## Baudrate impact
When running at 9600 subsequent sending and receiving by the RA6M5 is working correctly.
If you increase the TESTBAUD to 115200 or 230400:  **8 out of 10 times it misses** one of the 6 bytes sent by the ATP at random!

## Notes
I had a Seleae tracer connected and can confirm that every time the ATP has send the complete sequence at the TESTBAUD speed.

As I also own an UNOR4WIFI I have compiled the RA6M5.ino sketch (using the official Arduino library) and did the same test with the UNOR4WIFI : NO BYTES ARE LOST!.

Just to test I have also taken the official Arduino UNOR4 library, added the RA6M5 variant, and updated the boards.txt. After compiling for the RA6M5, Serial1 test results are exactly the same as with the Sparkfun core files.

## Remarks
During testing with serialpasstrough the BLE, I had already noticed that sometimes characters were missing in the echo from the DA14531. I had for the time neglected that given we had a different issue to handle, but it looks like Serial2 also has the same issue.

Looking at the source of Serial.cpp, I discovered that the first byte after reset is never passed from the FSP to the WrapperCallback() routine. Looking at the FSP source for the official UNOR4 FSP, there is a lot of code in between for handling an interrupt.

I can't find the fsp configuration files for the Sparkfun libfsp.a as it is not in the place referenced in the core/readme file. **Maybe you can provide a link to that ??**  According to the file r_sci_art_cfg.h file, in the variant-folder includes/ra_cfg/fsp_cfg, **Sparkfun has NOT enabled SCI_UART_CFG_FIFO_SUPPORT and SCI_UART_CFG_FLOW_CONTROL_SUPPORT, where UNOR4WIFI has this enabled. Maybe that is the root cause.**

Regards,
Paul

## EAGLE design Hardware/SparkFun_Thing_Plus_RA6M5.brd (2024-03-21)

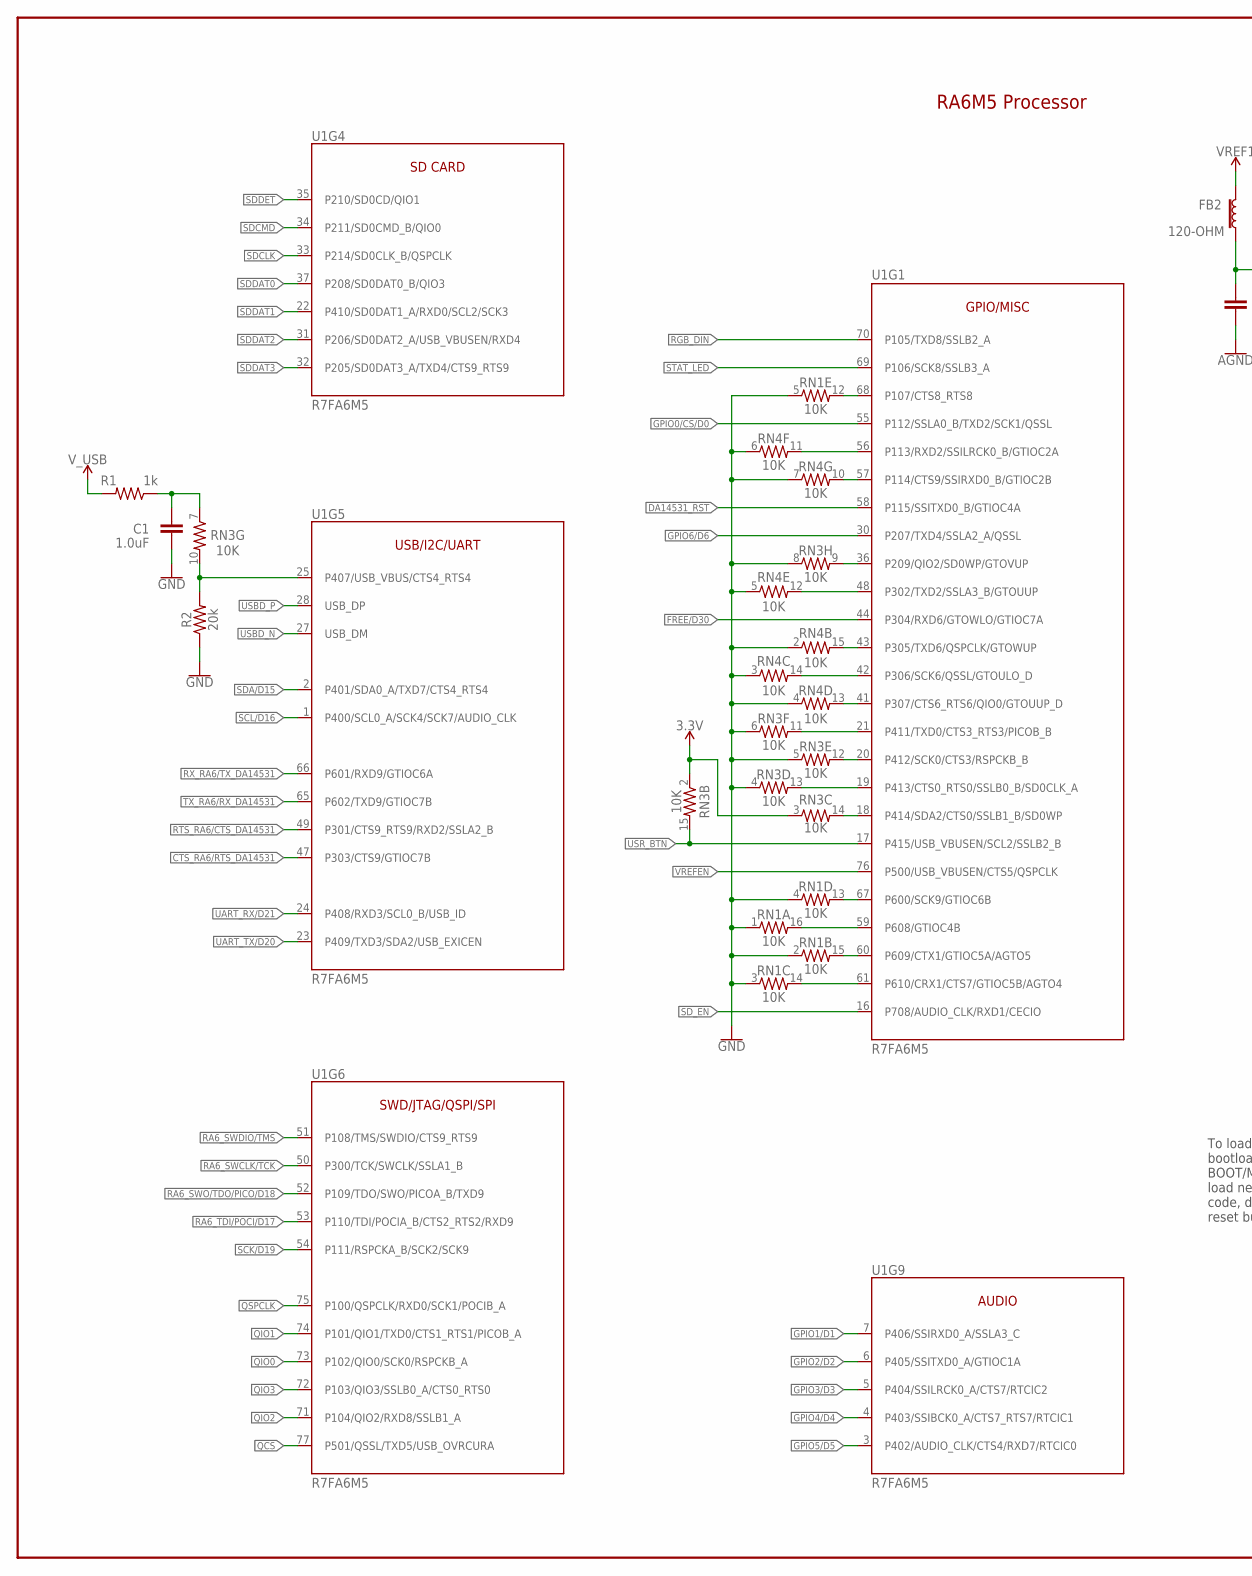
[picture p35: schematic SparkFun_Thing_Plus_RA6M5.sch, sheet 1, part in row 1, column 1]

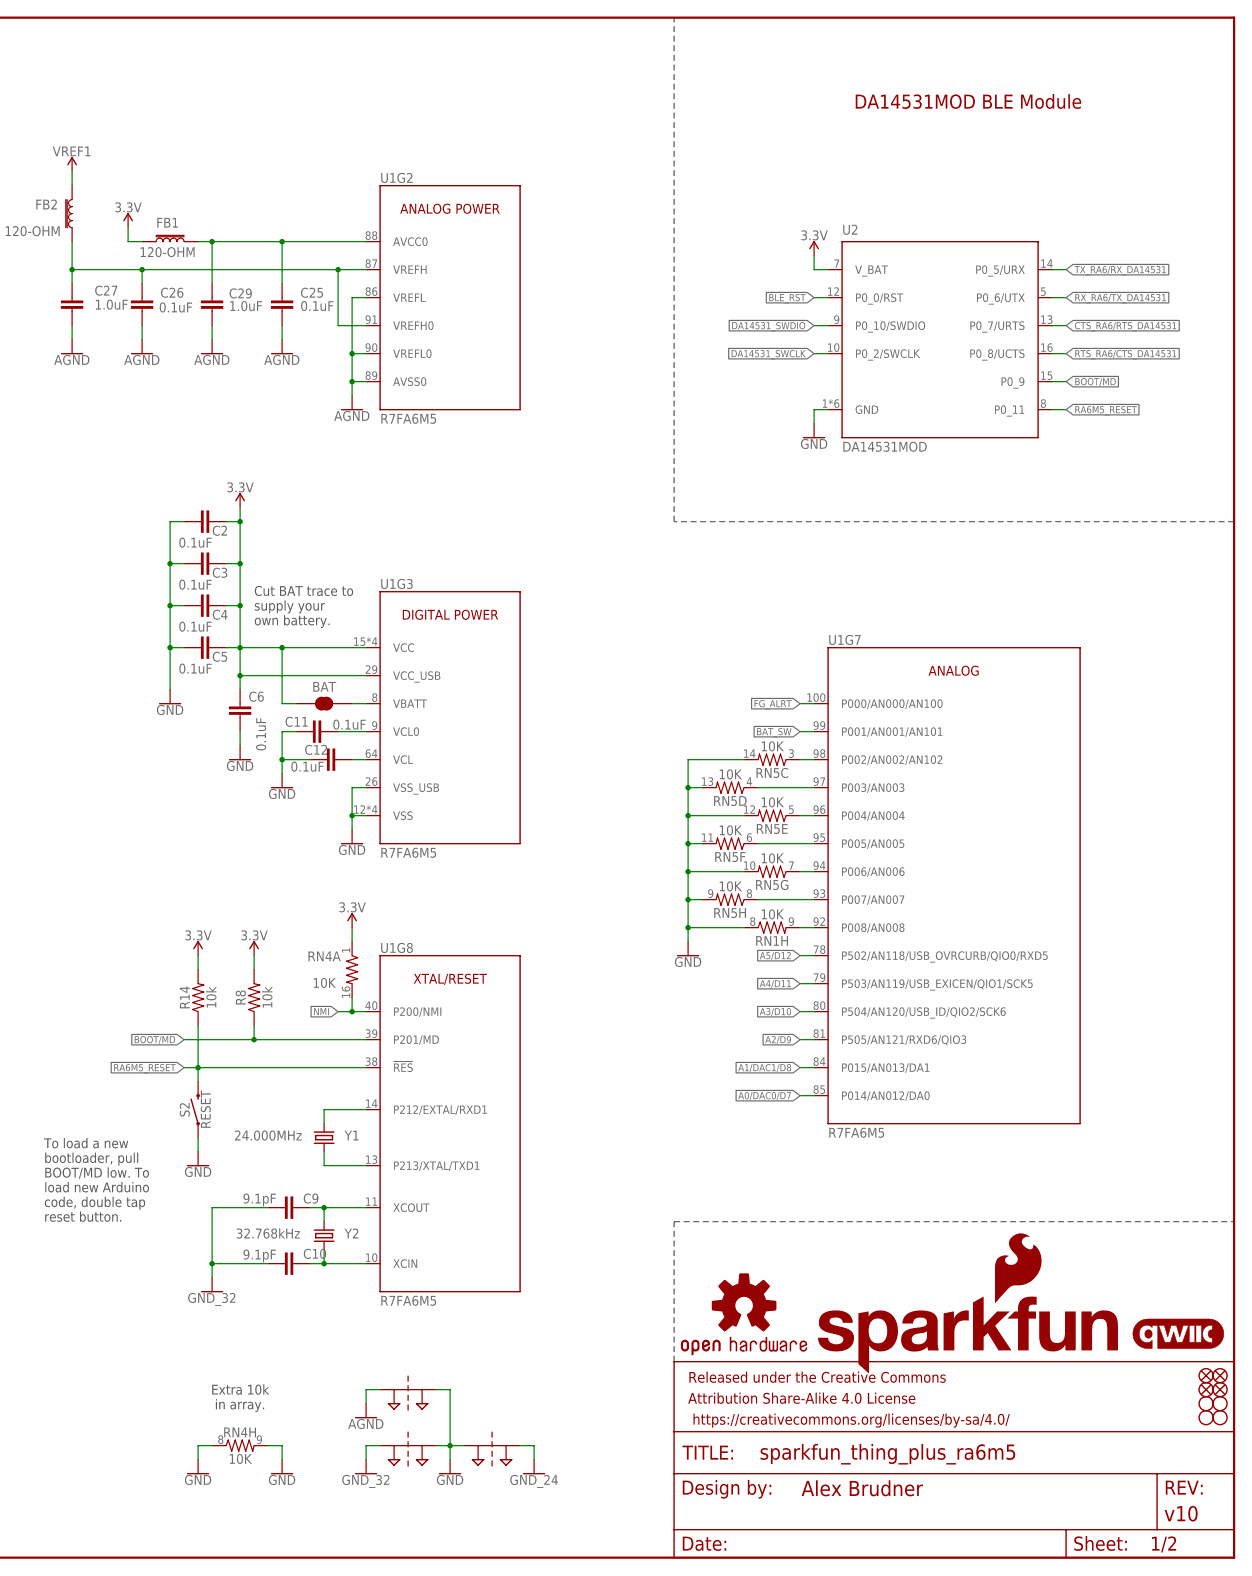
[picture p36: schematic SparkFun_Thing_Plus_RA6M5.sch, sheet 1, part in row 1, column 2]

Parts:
BAT: JUMPER-SMT_2_NC_TRACE_SILK; SMT-JUMPER_2_NC_TRACE_SILK
C1, C27, C29: 1.0uF; 0402-TIGHT
C2, C3, C4, C5, C6, C11, C12, C25, C26: 0.1uF; 0402-TIGHT
C9, C10: 9.1pF; 0402-TIGHT
FB1, FB2: 120-OHM; 0402-TIGHT
FD1, FD2, FD3, FD4: FIDUCIALUFIDUCIAL; FIDUCIAL-MICRO
FRAME1: FRAME-LEDGER; CREATIVE_COMMONS
H1, H2, H3, H4: STAND-OFFTIGHT; STAND-OFF-TIGHT
LOGO1: OSHW-LOGOMINI; OSHW-LOGO-MINI
LOGO2: SFE_LOGO_NAME_FLAME.1_INCH; SFE_LOGO_NAME_FLAME_.1
LOGO3: QWIIC_LOGO_4MM; QWIIC_4MM
R1: 1k; 0402-TIGHT
R2: 20k; 0402-TIGHT
R8, R14: 10k; 0402-TIGHT
RN1, RN3, RN4, RN5: 10K; 2506_AR
S2: RESET; TACTILE_SWITCH_SMD_4.6X2.8MM
SUPPLYTIE1, SUPPLYTIE2, SUPPLYTIE3: 2PT_GND_TIESMALL; 2PT_GND_TIE_SMALL
U1: R7FA6M5; P-LQFP100-14X14-0.50
U2: DA14531MOD
Y1: 24.000MHz; 4-SMD,32X25
Y2: 32.768kHz; CRYSTAL-SMD-3.2X1.5MM

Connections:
3.3V: BAT.1, C2.1, C3.1, C4.1, C5.1, C6.1, FB1.1, R8.2, R14.2, RN3.2 (1), RN3.3 (1), RN4.1, U1.15 (VCC), U1.29 (VCC_USB), U1.46 (VCC), U1.62 (VCC), U1.82 (VCC), U2.7 (V_BAT); also elsewhere on the board
!CTS_RA6/RTS_DA14531!: U1.47 (P303/CTS9/GTIOC7B), U2.13 (P0_7/URTS); also elsewhere on the board
!DA14531_RST!: U1.58 (P115/SSITXD0_B/GTIOC4A); also elsewhere on the board
!FG_ALRT!: U1.100 (P000/AN000/AN100); also elsewhere on the board
!NMI!: RN4.16 (2), U1.40 (P200/NMI); also elsewhere on the board
!QCS!: U1.77 (P501/QSSL/TXD5/USB_OVRCURA); also elsewhere on the board
!RA6M5_RESET!: R14.1, S2.3 (2), S2.4 (2), U1.38 (!RES!), U2.8 (P0_11); also elsewhere on the board
!RTS_RA6/CTS_DA14531!: U1.49 (P301/CTS9_RTS9/RXD2/SSLA2_B), U2.16 (P0_8/UCTS); also elsewhere on the board
!SD_EN!: U1.16 (P708/AUDIO_CLK/RXD1/CECIO); also elsewhere on the board
!USR_BTN!: RN3.15 (2), U1.17 (P415/USB_VBUSEN/SCL2/SSLB2_B); also elsewhere on the board
A0/DAC0/D7: U1.85 (P014/AN012/DA0); also elsewhere on the board
A1/DAC1/D8: U1.84 (P015/AN013/DA1); also elsewhere on the board
A2/D9: U1.81 (P505/AN121/RXD6/QIO3); also elsewhere on the board
A3/D10: U1.80 (P504/AN120/USB_ID/QIO2/SCK6); also elsewhere on the board
A4/D11: U1.79 (P503/AN119/USB_EXICEN/QIO1/SCK5); also elsewhere on the board
A5/D12: U1.78 (P502/AN118/USB_OVRCURB/QIO0/RXD5); also elsewhere on the board
AGND: C25.2, C26.2, C27.2, C29.2, SUPPLYTIE1.P$1, U1.86 (VREFL), U1.89 (AVSS0), U1.90 (VREFL0)
AVCC0: C25.1, C29.1, FB1.2, U1.88 (AVCC0); also elsewhere on the board
BAT_SW: U1.99 (P001/AN001/AN101); also elsewhere on the board
BLE_RST: U2.12 (P0_0/RST); also elsewhere on the board
BOOT/MD: R8.1, U1.39 (P201/MD), U2.15 (P0_9); also elsewhere on the board
DA14531_SWCLK: U2.10 (P0_2/SWCLK); also elsewhere on the board
DA14531_SWDIO: U2.9 (P0_10/SWDIO); also elsewhere on the board
EXTAL: U1.14 (P212/EXTAL/RXD1), Y1.1
FREE/D30: U1.44 (P304/RXD6/GTOWLO/GTIOC7A); also elsewhere on the board
GND: C1.1, C2.2, C3.2, C4.2, C5.2, C6.2, C11.2, C12.2, R2.1, RN1.1, RN1.2 (1), RN1.3 (1), RN1.4 (1), RN1.5 (1), RN1.8 (1), RN3.4 (1), RN3.5 (1), RN3.6 (1), RN3.8 (1), RN4.2 (1), RN4.3 (1), RN4.4 (1), RN4.5 (1), RN4.6 (1), RN4.7 (1), RN4.8 (1), RN4.9 (2), RN5.9 (2), RN5.10 (2), RN5.11 (2), RN5.12 (2), RN5.13 (2), RN5.14 (2), S2.1, S2.2 (1), SUPPLYTIE1.P$2, SUPPLYTIE2.P$2, SUPPLYTIE3.P$1, U1.12 (VSS), U1.26 (VSS_USB), U1.45 (VSS), U1.63 (VSS), U1.83 (VSS), U2.1 (GND), U2.2 (GND), U2.3 (GND), U2.4 (GND), U2.6 (GND), U2.11 (GND); also elsewhere on the board
GND_24: SUPPLYTIE3.P$2
GND_32: C9.1, C10.1, SUPPLYTIE2.P$1
GPIO0/!CS!/D0: U1.55 (P112/SSLA0_B/TXD2/SCK1/QSSL); also elsewhere on the board
GPIO1/D1: U1.7 (P406/SSIRXD0_A/SSLA3_C); also elsewhere on the board
GPIO2/D2: U1.6 (P405/SSITXD0_A/GTIOC1A); also elsewhere on the board
GPIO3/D3: U1.5 (P404/SSILRCK0_A/CTS7/RTCIC2); also elsewhere on the board
GPIO4/D4: U1.4 (P403/SSIBCK0_A/CTS7_RTS7/RTCIC1); also elsewhere on the board
GPIO5/D5: U1.3 (P402/AUDIO_CLK/CTS4/RXD7/RTCIC0); also elsewhere on the board
GPIO6/D6: U1.30 (P207/TXD4/SSLA2_A/QSSL); also elsewhere on the board
unnamed: RN1.9 (2), U1.92 (P008/AN008)
unnamed: RN3.9 (2), U1.36 (P209/QIO2/SD0WP/GTOVUP)
unnamed: C1.2, R1.1, RN3.7 (1)
unnamed: RN3.14 (2), U1.18 (P414/SDA2/CTS0/SSLB1_B/SD0WP)
unnamed: R2.2, RN3.10 (2), U1.25 (P407/USB_VBUS/CTS4_RTS4)
unnamed: RN1.14 (2), U1.61 (P610/CRX1/CTS7/GTIOC5B/AGTO4)
unnamed: RN1.15 (2), U1.60 (P609/CTX1/GTIOC5A/AGTO5)
unnamed: RN1.16 (2), U1.59 (P608/GTIOC4B)
unnamed: RN4.15 (2), U1.43 (P305/TXD6/QSPCLK/GTOWUP)
unnamed: RN1.13 (2), U1.67 (P600/SCK9/GTIOC6B)
unnamed: RN3.13 (2), U1.19 (P413/CTS0_RTS0/SSLB0_B/SD0CLK_A)
unnamed: RN3.12 (2), U1.20 (P412/SCK0/CTS3/RSPCKB_B)
unnamed: RN3.11 (2), U1.21 (P411/TXD0/CTS3_RTS3/PICOB_B)
unnamed: C26.1, C27.1, FB2.1, U1.87 (VREFH), U1.91 (VREFH0)
unnamed: RN4.13 (2), U1.41 (P307/CTS6_RTS6/QIO0/GTOUUP_D)
unnamed: RN4.12 (2), U1.48 (P302/TXD2/SSLA3_B/GTOUUP)
unnamed: RN4.14 (2), U1.42 (P306/SCK6/QSSL/GTOULO_D)
unnamed: BAT.2, U1.8 (VBATT)
unnamed: RN4.10 (2), U1.57 (P114/CTS9/SSIRXD0_B/GTIOC2B)
unnamed: RN4.11 (2), U1.56 (P113/RXD2/SSILRCK0_B/GTIOC2A)
unnamed: RN1.12 (2), U1.68 (P107/CTS8_RTS8)
unnamed: RN5.8 (1), U1.93 (P007/AN007)
unnamed: RN5.7 (1), U1.94 (P006/AN006)
unnamed: RN5.6 (1), U1.95 (P005/AN005)
unnamed: RN5.5 (1), U1.96 (P004/AN004)
unnamed: RN5.4 (1), U1.97 (P003/AN003)
unnamed: RN5.3 (1), U1.98 (P002/AN002/AN102)
unnamed: C11.1, U1.9 (VCL0)
unnamed: C12.1, U1.64 (VCL)
QIO0: U1.73 (P102/QIO0/SCK0/RSPCKB_A); also elsewhere on the board
QIO1: U1.74 (P101/QIO1/TXD0/CTS1_RTS1/PICOB_A); also elsewhere on the board
QIO2: U1.71 (P104/QIO2/RXD8/SSLB1_A); also elsewhere on the board
QIO3: U1.72 (P103/QIO3/SSLB0_A/CTS0_RTS0); also elsewhere on the board
QSPCLK: U1.75 (P100/QSPCLK/RXD0/SCK1/POCIB_A); also elsewhere on the board
RA6_SWCLK/TCK: U1.50 (P300/TCK/SWCLK/SSLA1_B); also elsewhere on the board
RA6_SWDIO/TMS: U1.51 (P108/TMS/SWDIO/CTS9_RTS9); also elsewhere on the board
RA6_SWO/TDO/PICO/D18: U1.52 (P109/TDO/SWO/PICOA_B/TXD9); also elsewhere on the board
RA6_TDI/POCI/D17: U1.53 (P110/TDI/POCIA_B/CTS2_RTS2/RXD9); also elsewhere on the board
RGB_DIN: U1.70 (P105/TXD8/SSLB2_A); also elsewhere on the board
RX_RA6/TX_DA14531: U1.66 (P601/RXD9/GTIOC6A), U2.5 (P0_6/UTX); also elsewhere on the board
SCK/D19: U1.54 (P111/RSPCKA_B/SCK2/SCK9); also elsewhere on the board
SCL/D16: U1.1 (P400/SCL0_A/SCK4/SCK7/AUDIO_CLK); also elsewhere on the board
SDA/D15: U1.2 (P401/SDA0_A/TXD7/CTS4_RTS4); also elsewhere on the board
SDCLK: U1.33 (P214/SD0CLK_B/QSPCLK); also elsewhere on the board
SDCMD: U1.34 (P211/SD0CMD_B/QIO0); also elsewhere on the board
SDDAT0: U1.37 (P208/SD0DAT0_B/QIO3); also elsewhere on the board
SDDAT1: U1.22 (P410/SD0DAT1_A/RXD0/SCL2/SCK3); also elsewhere on the board
SDDAT2: U1.31 (P206/SD0DAT2_A/USB_VBUSEN/RXD4); also elsewhere on the board
SDDAT3: U1.32 (P205/SD0DAT3_A/TXD4/CTS9_RTS9); also elsewhere on the board
SDDET: U1.35 (P210/SD0CD/QIO1); also elsewhere on the board
STAT_LED: U1.69 (P106/SCK8/SSLB3_A); also elsewhere on the board
TX_RA6/RX_DA14531: U1.65 (P602/TXD9/GTIOC7B), U2.14 (P0_5/URX); also elsewhere on the board
UART_RX/D21: U1.24 (P408/RXD3/SCL0_B/USB_ID); also elsewhere on the board
UART_TX/D20: U1.23 (P409/TXD3/SDA2/USB_EXICEN); also elsewhere on the board
USBD_N: U1.27 (USB_DM); also elsewhere on the board
USBD_P: U1.28 (USB_DP); also elsewhere on the board
VREF1: FB2.2; also elsewhere on the board
VREFEN: U1.76 (P500/USB_VBUSEN/CTS5/QSPCLK); also elsewhere on the board
V_USB: R1.2; also elsewhere on the board
XCIN: C10.2, U1.10 (XCIN), Y2.P$1 (1)
XCOUT: C9.2, U1.11 (XCOUT), Y2.P$2 (2)
XTAL: U1.13 (P213/XTAL/TXD1), Y1.3 (2)

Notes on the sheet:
DA14531MOD BLE Module
RA6M5 Processor
Cut BAT trace to supply your own battery.
Extra 10k in array.
To load a new bootloader, pull BOOT/MD low. To load new Arduino code, double tap reset button.

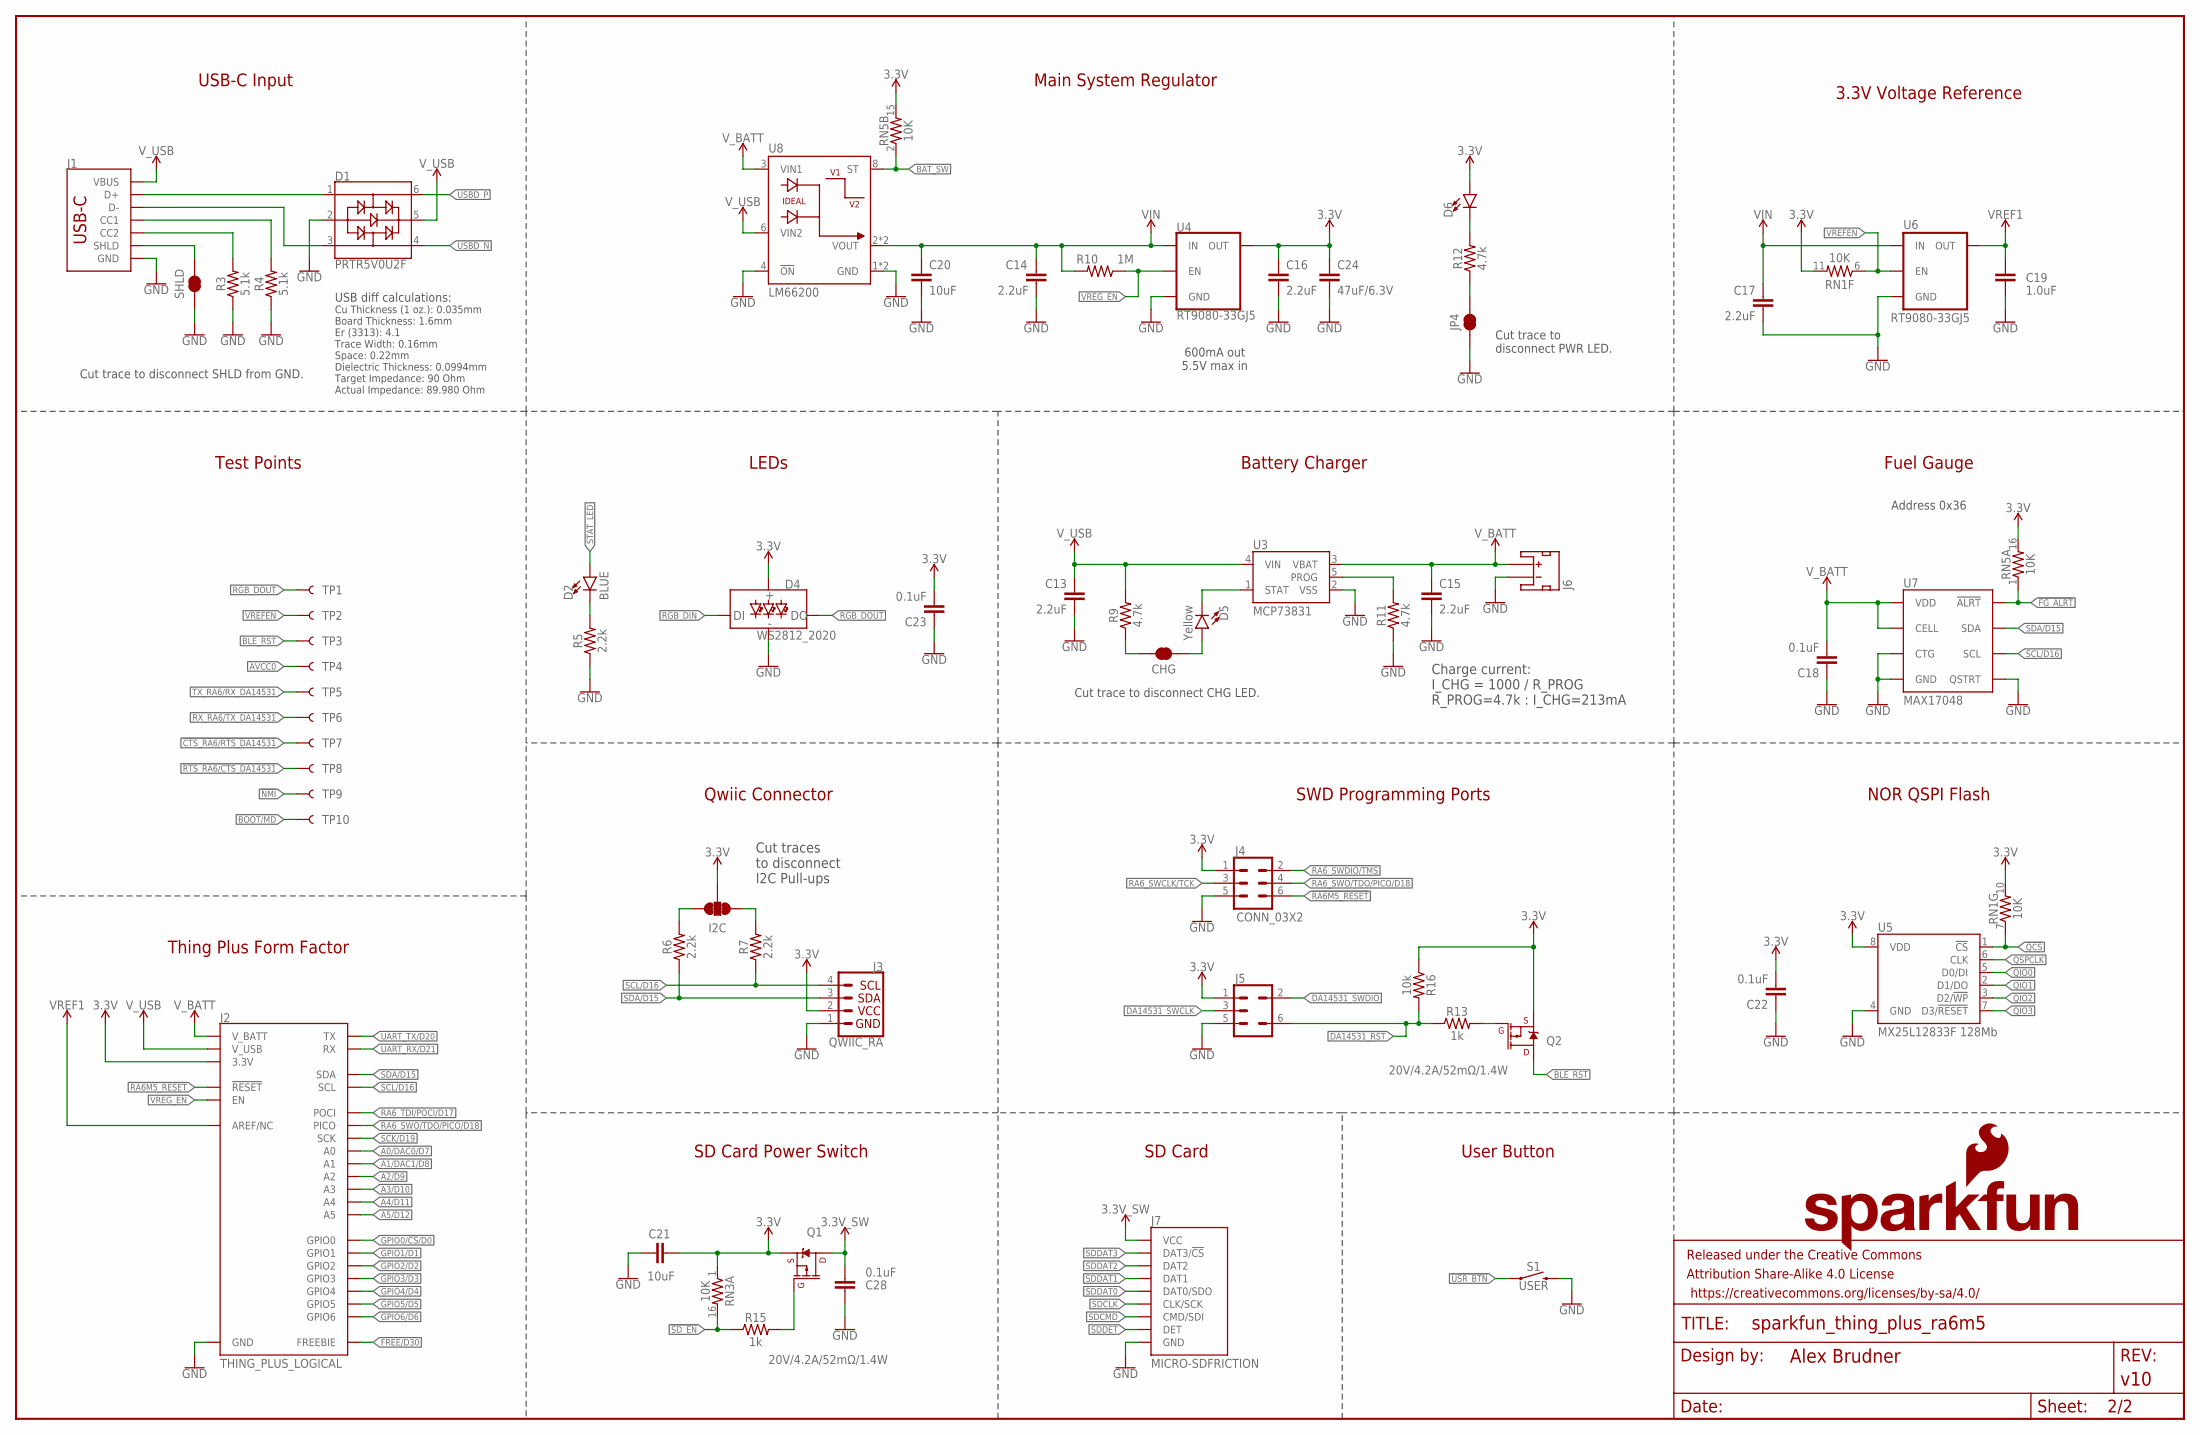
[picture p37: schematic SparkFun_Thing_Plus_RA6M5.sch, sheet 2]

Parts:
C13, C14, C15, C16, C17: 2.2uF; 0402-TIGHT
C18, C22, C23, C28: 0.1uF; 0402-TIGHT
C19: 1.0uF; 0402-TIGHT
C20, C21: 10uF; 0805
C24: 47uF/6.3V; 0805
CHG: JUMPER-SMT_2_NC_TRACE_SILK; SMT-JUMPER_2_NC_TRACE_SILK
D1: PRTR5V0U2F; SOT886
D2: BLUE; LED-0603
D4: WS2812_2020; WS2812-2020
D5: Yellow; LED-0603
D6: LED-RED_0603-KB; LED-0603
FRAME2: FRAME-LEDGERNO_FOOTPRINT; DUMMY
I2C: JUMPER-SMT_3_2-NC_TRACE_SILK; SMT-JUMPER_3_2-NC_TRACE_SILK
J1: USB Female Type C Connector; USB-C-16P-6LAYER-ISOLATED
J2: THING_PLUS_LOGICAL; THING_PLUS
J3: QWIIC_RA; JST04_1MM_RA
J4: CONN_03X2; PAD_05_03X2_TP
J5: SWD-5PIN; PAD_05_03X2_TP_NO4
J6: JST_2MM_MALE; JST-2-SMD
J7: MICRO-SDFRICTION; MICROSD_TINY
JP4: JUMPER-SMT_2_NC_TRACE_SILK; SMT-JUMPER_2_NC_TRACE_SILK
LOGO4: SFE_LOGO_NAME_FLAMEBLANK; BLANK
Q1, Q2: 20V/4.2A/52mΩ/1.4W; SOT23-3
R3, R4: 5.1k; 0402-TIGHT
R5, R6, R7: 2.2k; 0402-TIGHT
R9, R11, R12: 4.7k; 0402-TIGHT
R10: 1M; 0402-TIGHT
R13, R15: 1k; 0402-TIGHT
R16: 10k; 0402-TIGHT
RN1, RN3, RN5: 10K; 2506_AR
S1: USER; TACTILE_SWITCH_SMD_4.6X2.8MM
SHLD: JUMPER-SMT_2_NC_TRACE_SILK; SMT-JUMPER_2_NC_TRACE_SILK
TP1, TP3, TP5, TP6, TP7, TP8, TP10: TEST-POINT3X5; PAD.03X.05
TP2: TEST-POINT3X4; PAD.03X.04
TP4, TP9: TEST-POINT3; PAD.03X.03
U3: MCP73831; SOT23-5
U4, U6: RT9080-33GJ5; SOT23-5
U5: MX25L12833F 128Mb; WSON-8-6X5
U7: MAX17048; DFN-8
U8: LM66200; SOT8

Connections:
3.3V: C16.1, C21.1, C22.2, C23.2, C24.1, D4.VCC, D6.A, I2C.2, J2.27 (3.3V), J3.2, J4.1, J5.1, Q1.2 (S), Q2.2 (S), R16.1, RN1.10 (2), RN1.11 (2), RN3.1, RN5.15 (2), RN5.16 (2), U4.5 (OUT), U5.8 (VDD); also elsewhere on the board
3.3V_SW: C28.2, J7.4 (VCC), Q1.3 (D)
!CTS_RA6/RTS_DA14531!: TP7.1; also elsewhere on the board
!DA14531_RST!: J5.6, R13.1, R16.2; also elsewhere on the board
!FG_ALRT!: RN5.1, U7.5 (!ALRT); also elsewhere on the board
!NMI!: TP9.1; also elsewhere on the board
!QCS!: RN1.7 (1), U5.1 (!CS!); also elsewhere on the board
!RA6M5_RESET!: J2.28 (!RESET), J4.6; also elsewhere on the board
!RTS_RA6/CTS_DA14531!: TP8.1; also elsewhere on the board
!SD_EN!: R15.1, RN3.16 (2); also elsewhere on the board
!USR_BTN!: S1.1, S1.2 (1); also elsewhere on the board
A0/DAC0/D7: J2.24 (A0); also elsewhere on the board
A1/DAC1/D8: J2.23 (A1); also elsewhere on the board
A2/D9: J2.22 (A2); also elsewhere on the board
A3/D10: J2.21 (A3); also elsewhere on the board
A4/D11: J2.20 (A4); also elsewhere on the board
A5/D12: J2.19 (A5); also elsewhere on the board
AVCC0: TP4.1; also elsewhere on the board
BAT_SW: RN5.2 (1), U8.8 (ST); also elsewhere on the board
BLE_RST: Q2.3 (D), TP3.1; also elsewhere on the board
BOOT/MD: TP10.1; also elsewhere on the board
DA14531_SWCLK: J5.3; also elsewhere on the board
DA14531_SWDIO: J5.2; also elsewhere on the board
FREE/D30: J2.13 (FREEBIE); also elsewhere on the board
GND: C13.2, C14.2, C15.2, C16.2, C17.2, C18.1, C19.2, C20.2, C21.2, C22.1, C23.1, C24.2, C28.1, D1.2, D4.GND, J1.GND, J1.GND2 (GND), J2.25 (GND), J3.1, J4.5, J5.5, J6.1 (-), J7.6 (GND), J7.GND1 (GND), J7.GND2 (GND), J7.GND3 (GND), J7.GND4 (GND), J7.GND5 (GND), J7.GND6 (GND), JP4.1, R3.1, R4.1, R5.1, R11.1, S1.3 (2), S1.4 (2), SHLD.1, U3.2 (VSS), U4.2 (GND), U5.4 (GND), U6.2 (GND), U7.1 (CTG), U7.4 (GND), U7.6 (QSTRT), U7.9 (GND), U8.1 (GND), U8.4 (!ON!), U8.5 (GND); also elsewhere on the board
GPIO0/!CS!/D0: J2.9 (GPIO0); also elsewhere on the board
GPIO1/D1: J2.8 (GPIO1); also elsewhere on the board
GPIO2/D2: J2.7 (GPIO2); also elsewhere on the board
GPIO3/D3: J2.6 (GPIO3); also elsewhere on the board
GPIO4/D4: J2.5 (GPIO4); also elsewhere on the board
GPIO5/D5: J2.4 (GPIO5); also elsewhere on the board
GPIO6/D6: J2.3 (GPIO6); also elsewhere on the board
unnamed: CHG.2, R9.1
unnamed: CHG.1, D5.A
unnamed: D5.C, U3.1 (STAT)
unnamed: Q2.1 (G), R13.2
unnamed: R11.2, U3.5 (PROG)
unnamed: D2.C, R5.2
unnamed: I2C.1, R6.2
unnamed: I2C.3, R7.2
unnamed: JP4.2, R12.1
unnamed: D6.C, R12.2
unnamed: J1.SHLD1 (SHLD), J1.SHLD2 (SHLD), J1.SHLD3 (SHLD), J1.SHLD4 (SHLD), J1.SHLD5 (SHLD), J1.SHLD6 (SHLD), J1.SHLD7 (SHLD), J1.SHLD8 (SHLD), SHLD.2
unnamed: J1.B5 (CC2), R3.2
unnamed: J1.A5 (CC1), R4.2
unnamed: Q1.1 (G), R15.2
QIO0: U5.5 (D0/DI); also elsewhere on the board
QIO1: U5.2 (D1/DO); also elsewhere on the board
QIO2: U5.3 (D2/!WP!); also elsewhere on the board
QIO3: U5.7 (D3/!RESET!); also elsewhere on the board
QSPCLK: U5.6 (CLK); also elsewhere on the board
RA6_SWCLK/TCK: J4.3; also elsewhere on the board
RA6_SWDIO/TMS: J4.2; also elsewhere on the board
RA6_SWO/TDO/PICO/D18: J2.17 (PICO), J4.4; also elsewhere on the board
RA6_TDI/POCI/D17: J2.16 (POCI); also elsewhere on the board
RGB_DIN: D4.DI; also elsewhere on the board
RGB_DOUT: D4.DO, TP1.1
RX_RA6/TX_DA14531: TP6.1; also elsewhere on the board
SCK/D19: J2.18 (SCK); also elsewhere on the board
SCL/D16: J2.2 (SCL), J3.4, R7.1, U7.7 (SCL); also elsewhere on the board
SDA/D15: J2.1 (SDA), J3.3, R6.1, U7.8 (SDA); also elsewhere on the board
SDCLK: J7.5 (CLK/SCK); also elsewhere on the board
SDCMD: J7.3 (CMD/SDI); also elsewhere on the board
SDDAT0: J7.7 (DAT0/SDO); also elsewhere on the board
SDDAT1: J7.8 (DAT1); also elsewhere on the board
SDDAT2: J7.1 (DAT2); also elsewhere on the board
SDDAT3: J7.2 (DAT3/!CS!); also elsewhere on the board
SDDET: J7.9 (DET); also elsewhere on the board
STAT_LED: D2.A; also elsewhere on the board
TX_RA6/RX_DA14531: TP5.1; also elsewhere on the board
UART_RX/D21: J2.15 (RX); also elsewhere on the board
UART_TX/D20: J2.14 (TX); also elsewhere on the board
USBD_N: D1.4; also elsewhere on the board
USBD_P: D1.6; also elsewhere on the board
USBIN_N: D1.3, J1.A7 (D-), J1.B7 (D-)
USBIN_P: D1.1, J1.A6 (D+), J1.B6 (D+)
VIN: C14.1, C17.1, C20.1, R10.2, U4.1 (IN), U6.1 (IN), U8.2 (VOUT), U8.7 (VOUT)
VREF1: C19.1, J2.26 (AREF/NC), U6.5 (OUT); also elsewhere on the board
VREFEN: RN1.6 (1), TP2.1, U6.3 (EN); also elsewhere on the board
VREG_EN: J2.11 (EN), R10.1, U4.3 (EN)
V_BATT: C15.1, C18.2, J2.12 (V_BATT), J6.2 (+), U3.3 (VBAT), U7.2 (CELL), U7.3 (VDD), U8.3 (VIN1)
V_USB: C13.1, D1.5, J1.VBUS1 (VBUS), J1.VBUS2 (VBUS), J2.10 (V_USB), R9.2, U3.4 (VIN), U8.6 (VIN2); also elsewhere on the board

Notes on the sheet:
USB-C Input
Main System Regulator
Battery Charger
Test Points
3.3V Voltage Reference
Fuel Gauge
NOR QSPI Flash
SWD Programming Ports
Qwiic Connector
LEDs
Thing Plus Form Factor
SD Card
Cut trace to disconnect PWR LED.
Cut trace to disconnect CHG LED.
Cut trace to disconnect SHLD from GND.
Cut traces to disconnect I2C Pull-ups
Charge current: I_CHG = 1000 / R_PROG R_PROG=4.7k : I_CHG=213mA
600mA out 5.5V max in
SD Card Power Switch
USB diff calculations:
Cu Thickness (1 oz.): 0.035mm Board Thickness: 1.6mm Er (3313): 4.1 Trace Width: 0.16mm Space: 0.22mm Dielectric Thickness: 0.0994mm Target Impedance: 90 Ohm Actual Impedance: 89.980 Ohm
Address 0x36
User Button

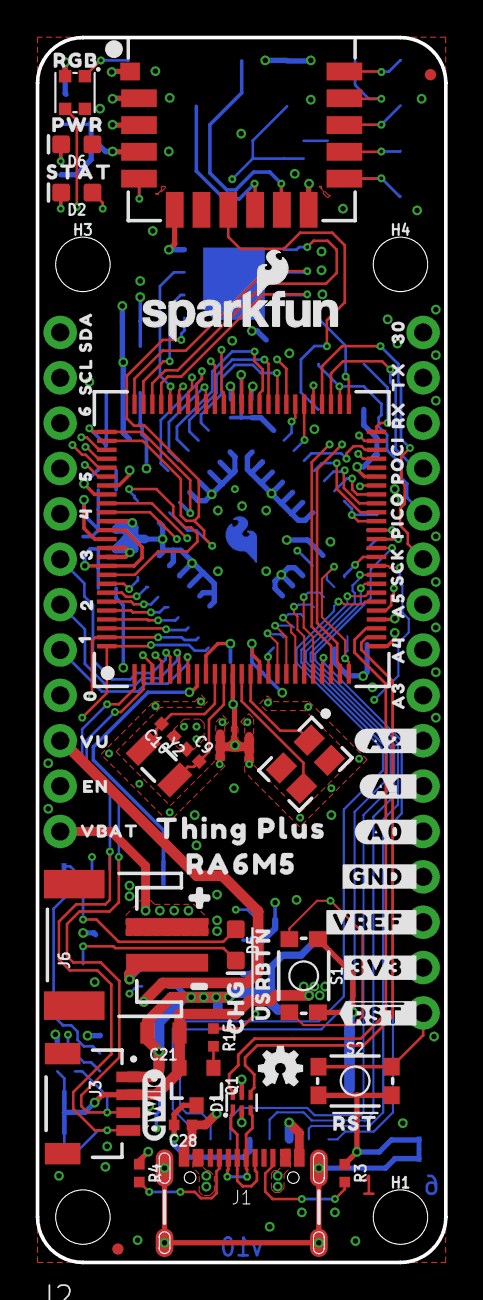
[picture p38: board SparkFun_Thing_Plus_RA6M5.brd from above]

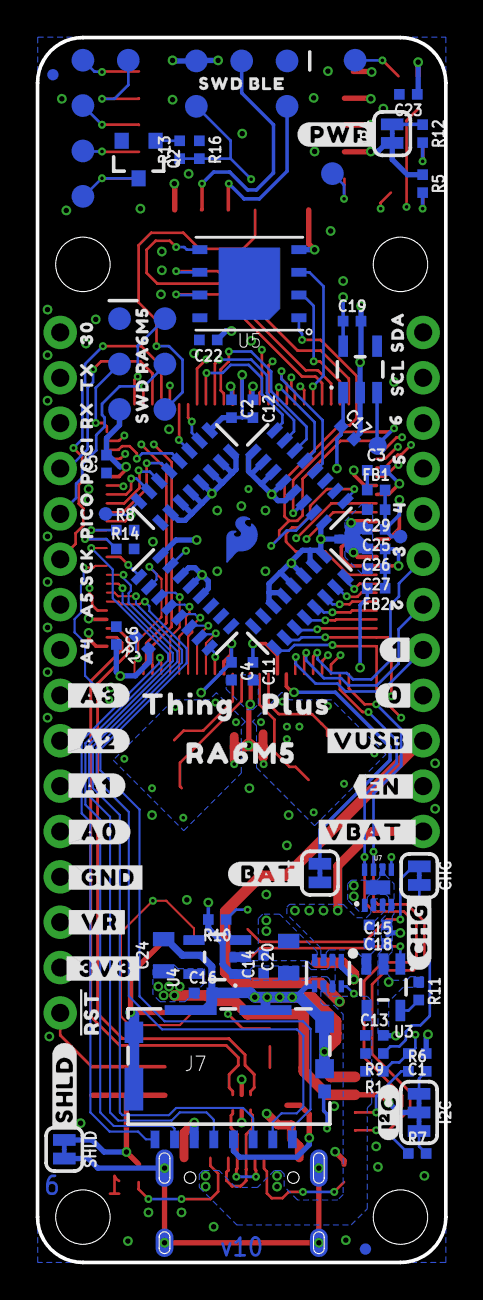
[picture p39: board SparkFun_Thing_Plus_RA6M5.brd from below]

Board: 6 copper layers, 22.9 x 68.6 mm, 185 parts (109 on the bottom side), 117 nets.

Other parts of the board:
U$3: #I�C#0
U$4: #CHG#0
U$8: SFE_LOGO_FLAME_COPPER_EXPOSED_.1
U$9: SWD_RA6M50
U$10: SWD_BLE0
U$12, U$86: 300
U$13, U$51: #RST#0
U$14: CHG0
U$15: STAT0
U$16: PWR0
U$17: RGB0
U$18: THING_PLUS0
U$19: ##RST#_#0
U$20: #3V3_#0
U$21: #VREF_#0
U$22: #GND_#0
U$23: #A0_#0
U$24: #A1_#0
U$25: #A2_#0
U$26: A30
U$27, U$59: A40
U$28, U$60: A50
U$29, U$61: SCK0
U$30, U$62: PICO0
U$31, U$63: POCI0
U$32, U$64: RX0
U$33, U$65: TX0
U$34, U$43: 60
U$35, U$67: SDA0
U$36, U$68: SCL0
U$37, U$48: 50
U$38, U$66: 40
U$39, U$69: 30
U$40, U$70: 20
U$41: 10
U$42: 00
U$44: VU0
U$45: EN0
U$46: VBAT0
U$47: #PWR#0
U$49: #BAT#0
U$50: #SHLD#0
U$52: #_3V3#0
U$53: #_VR#0
U$54: #_GND#0
U$55: #_A0#0
U$56: #_A1#0
U$57: #_A2#0
U$58: #_A3#0
U$71: #1#0
U$72: #0#0
U$73: #USRBTN#0
U$76: #VUSB#0
U$77: #EN_#0
U$78: #VBAT_#0
U$79, U$82: RA6M50
U$80: ORDERING_INSTRUCTIONS
U$81: #0
U$83: THING0
U$84: PLUS0
U$85: _#0

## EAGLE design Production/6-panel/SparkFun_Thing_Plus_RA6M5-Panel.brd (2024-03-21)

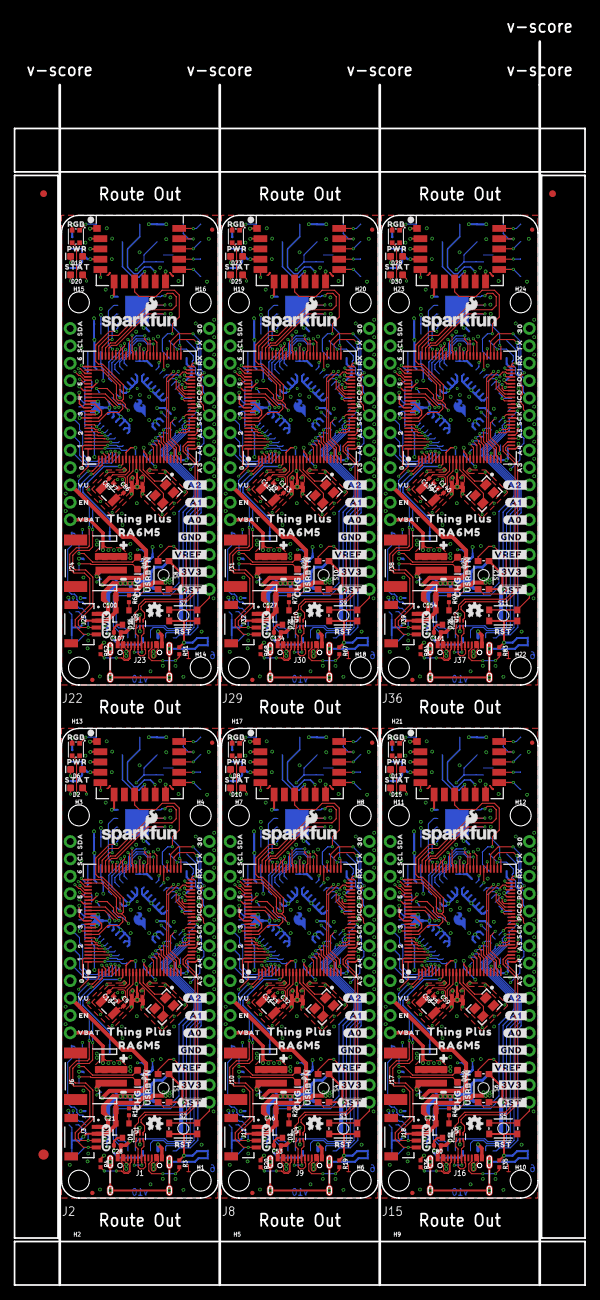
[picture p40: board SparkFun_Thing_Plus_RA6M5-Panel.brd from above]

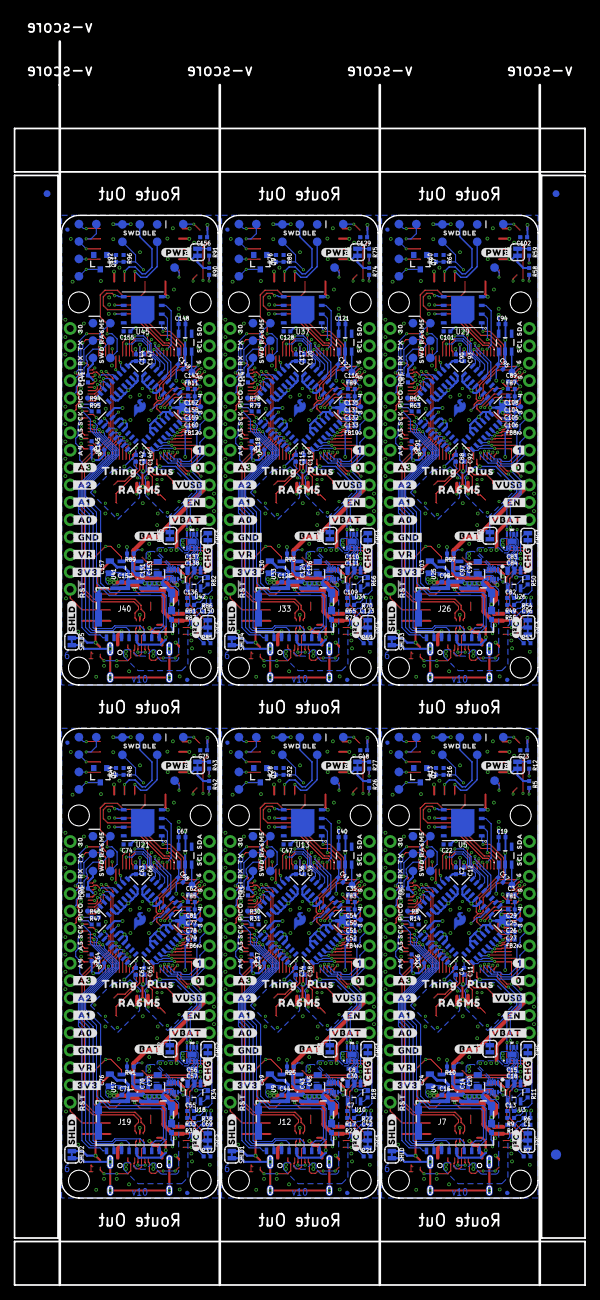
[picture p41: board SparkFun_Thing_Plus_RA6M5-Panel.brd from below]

Board: 6 copper layers, 83.3 x 181.6 mm, 1104 parts (657 on the bottom side), 702 nets.

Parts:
BAT, BAT1, BAT2, BAT3, BAT4, BAT5: JUMPER-SMT_2_NC_TRACE_SILK; SMT-JUMPER_2_NC_TRACE_SILK
C1, C19, C27, C29, C40, C42, C52, C54, C67, C69, C79, C81, C94, C96, C106, C108, C121, C123, C133, C135, C148, C150, C160, C162: 1.0uF; 0402-TIGHT
C2, C3, C4, C5, C6, C11, C12, C18, C22, C23, C25, C26, C28, C30, C33, C34, C35, C36, C37, C38, C39, C47, C48, C50, C51, C53, C57, C60, C61, C62, C63, C64, C65, C66, C74, C75, C77, C78, C80, C84, C87, C88, C89, C90, C91, C92, C93, C101, C102, C104, C105, C107, C111, C114, C115, C116, C117, C118, C119, C120, C128, C129, C131, C132, C134, C138, C141, C142, C143, C144, C145, C146, C147, C155, C156, C158, C159, C161: 0.1uF; 0402-TIGHT
C7, C8, C13, C14, C15, C16, C17, C41, C43, C44, C55, C56, C68, C70, C71, C82, C83, C95, C97, C98, C109, C110, C122, C124, C125, C136, C137, C149, C151, C152: 2.2uF; 0402-TIGHT
C9, C10, C31, C32, C58, C59, C85, C86, C112, C113, C139, C140: 9.1pF; 0402-TIGHT
C20, C21, C45, C46, C72, C73, C99, C100, C126, C127, C153, C154: 10uF; 0805
C24, C49, C76, C103, C130, C157: 47uF/6.3V; 0805
CHG, CHG1, CHG2, CHG3, CHG4, CHG5: JUMPER-SMT_2_NC_TRACE_SILK; SMT-JUMPER_2_NC_TRACE_SILK
D1, D3, D11, D16, D21, D26: PRTR5V0U2F; SOT886
D2, D10, D15, D20, D25, D30: BLUE; LED-0603
D4, D9, D14, D19, D24, D29: WS2812_2020; WS2812-2020
D5, D7, D12, D17, D22, D27: Yellow; LED-0603
D6, D8, D13, D18, D23, D28: LED-0603
E$1, E$2, E$3, E$4: FIDUCIAL-1X2
E$5, E$6: FIDUCIAL-1.5X3
FB1, FB2, FB3, FB4, FB5, FB6, FB7, FB8, FB9, FB10, FB11, FB12: 120-OHM; 0402-TIGHT
FD1, FD2, FD3, FD4, FD5, FD6, FD7, FD8, FD9, FD10, FD11, FD12, FD13, FD14, FD15, FD16, FD17, FD18, FD19, FD20, FD21, FD22, FD23, FD24: FIDUCIALUFIDUCIAL; FIDUCIAL-MICRO
FRAME1, FRAME2, FRAME3, FRAME4, FRAME5, FRAME6: FRAME-LEDGERNO_FOOTPRINT; DUMMY
H1, H2, H3, H4, H5, H6, H7, H8, H9, H10, H11, H12, H13, H14, H15, H16, H17, H18, H19, H20, H21, H22, H23, H24: STAND-OFFTIGHT; STAND-OFF-TIGHT
I2C, I2C1, I2C2, I2C3, I2C4, I2C5: JUMPER-SMT_3_2-NC_TRACE_SILK; SMT-JUMPER_3_2-NC_TRACE_SILK
J1, J9, J16, J23, J30, J37: USB Female Type C Connector; USB-C-16P-6LAYER-ISOLATED
J2, J8, J15, J22, J29, J36: THING_PLUS_LOGICAL; THING_PLUS
J3, J11, J18, J25, J32, J39: QWIIC_RA; JST04_1MM_RA
J4, J13, J20, J27, J34, J41: CONN_03X2; PAD_05_03X2_TP
J5, J14, J21, J28, J35, J42: PAD_05_03X2_TP_NO4
J6, J10, J17, J24, J31, J38: JST-2-SMD
J7, J12, J19, J26, J33, J40: MICRO-SDFRICTION; MICROSD_TINY
JP1, JP2, JP3, JP4, JP5, JP6: JUMPER-SMT_2_NC_TRACE_SILK; SMT-JUMPER_2_NC_TRACE_SILK
LOGO1, LOGO7, LOGO11, LOGO15, LOGO19, LOGO23: OSHW-LOGOMINI; OSHW-LOGO-MINI
LOGO2, LOGO5, LOGO9, LOGO13, LOGO17, LOGO21: SFE_LOGO_NAME_FLAME.1_INCH; SFE_LOGO_NAME_FLAME_.1
LOGO3, LOGO6, LOGO10, LOGO14, LOGO18, LOGO22: QWIIC_LOGO_4MM; QWIIC_4MM
LOGO4, LOGO8, LOGO12, LOGO16, LOGO20, LOGO24: SFE_LOGO_NAME_FLAMEBLANK; BLANK
Q1, Q2, Q3, Q4, Q5, Q6, Q7, Q8, Q9, Q10, Q11, Q12: 20V/4.2A/52mΩ/1.4W; SOT23-3
R1, R13, R15, R23, R28, R29, R39, R44, R45, R55, R60, R61, R71, R76, R77, R87, R92, R93: 1k; 0402-TIGHT
R2, R24, R40, R56, R72, R88: 20k; 0402-TIGHT
R3, R4, R19, R20, R35, R36, R51, R52, R67, R68, R83, R84: 5.1k; 0402-TIGHT
R5, R6, R7, R21, R22, R26, R37, R38, R42, R53, R54, R58, R69, R70, R74, R85, R86, R90: 2.2k; 0402-TIGHT
R8, R14, R16, R30, R31, R32, R46, R47, R48, R62, R63, R64, R78, R79, R80, R94, R95, R96: 10k; 0402-TIGHT
R9, R11, R12, R17, R18, R27, R33, R34, R43, R49, R50, R59, R65, R66, R75, R81, R82, R91: 4.7k; 0402-TIGHT
R10, R25, R41, R57, R73, R89: 1M; 0402-TIGHT
RN1, RN2, RN3, RN4, RN5, RN6, RN7, RN8, RN9, RN10, RN11, RN12, RN13, RN14, RN15, RN16, RN17, RN18, RN19, RN20, RN21, RN22, RN23, RN24: 10K; 2506_AR
S1, S4, S6, S8, S10, S12: USER; TACTILE_SWITCH_SMD_4.6X2.8MM
S2, S3, S5, S7, S9, S11: RESET; TACTILE_SWITCH_SMD_4.6X2.8MM
SHLD, SHLD1, SHLD2, SHLD3, SHLD4, SHLD5: JUMPER-SMT_2_NC_TRACE_SILK; SMT-JUMPER_2_NC_TRACE_SILK
SUPPLYTIE1, SUPPLYTIE2, SUPPLYTIE3, SUPPLYTIE4, SUPPLYTIE5, SUPPLYTIE6, SUPPLYTIE7, SUPPLYTIE8, SUPPLYTIE9, SUPPLYTIE10, SUPPLYTIE11, SUPPLYTIE12, SUPPLYTIE13, SUPPLYTIE14, SUPPLYTIE15, SUPPLYTIE16, SUPPLYTIE17, SUPPLYTIE18: 2PT_GND_TIESMALL; 2PT_GND_TIE_SMALL
TP1, TP3, TP5, TP6, TP7, TP8, TP10, TP11, TP13, TP15, TP16, TP17, TP18, TP20, TP21, TP23, TP25, TP26, TP27, TP28, TP30, TP31, TP33, TP35, TP36, TP37, TP38, TP40, TP41, TP43, TP45, TP46, TP47, TP48, TP50, TP51, TP53, TP55, TP56, TP57, TP58, TP60: TEST-POINT3X5; PAD.03X.05
TP2, TP12, TP22, TP32, TP42, TP52: TEST-POINT3X4; PAD.03X.04
TP4, TP9, TP14, TP19, TP24, TP29, TP34, TP39, TP44, TP49, TP54, TP59: TEST-POINT3; PAD.03X.03
U1, U14, U22, U30, U38, U46: R7FA6M5; P-LQFP100-14X14-0.50
U2, U12, U20, U28, U36, U44: DA14531MOD
U3, U10, U18, U26, U34, U42: MCP73831; SOT23-5
U4, U6, U9, U15, U17, U23, U25, U31, U33, U39, U41, U47: RT9080-33GJ5; SOT23-5
U5, U13, U21, U29, U37, U45: MX25L12833F 128Mb; WSON-8-6X5
U7, U11, U19, U27, U35, U43: MAX17048; DFN-8
U8, U16, U24, U32, U40, U48: LM66200; SOT8
U$1, U$3, U$155, U$232, U$309, U$386: #I�C#0
U$2, U$4, U$156, U$233, U$310, U$387: #CHG#0
U$5, U$8, U$157, U$234, U$311, U$388: SFE_LOGO_FLAME_COPPER_EXPOSED_.1
U$6, U$13, U$51, U$109, U$158, U$186, U$235, U$263, U$312, U$340, U$389, U$417: #RST#0
U$7, U$14, U$159, U$236, U$313, U$390: CHG0
U$9, U$130, U$207, U$284, U$361, U$438: SWD_RA6M50
U$10, U$131, U$208, U$285, U$362, U$439: SWD_BLE0
U$11, U$15, U$160, U$237, U$314, U$391: STAT0
U$12, U$86, U$137, U$138, U$214, U$215, U$291, U$292, U$368, U$369, U$445, U$446: 300
U$16, U$74, U$161, U$238, U$315, U$392: PWR0
U$17, U$75, U$162, U$239, U$316, U$393: RGB0
U$18, U$128, U$205, U$282, U$359, U$436: THING_PLUS0
U$19, U$80, U$163, U$240, U$317, U$394: ##RST#_#0
U$20, U$87, U$164, U$241, U$318, U$395: #3V3_#0
U$21, U$88, U$165, U$242, U$319, U$396: #VREF_#0
U$22, U$89, U$166, U$243, U$320, U$397: #GND_#0
U$23, U$90, U$167, U$244, U$321, U$398: #A0_#0
U$24, U$91, U$168, U$245, U$322, U$399: #A1_#0
U$25, U$92, U$169, U$246, U$323, U$400: #A2_#0
U$26, U$93, U$170, U$247, U$324, U$401: A30
U$27, U$59, U$94, U$116, U$171, U$193, U$248, U$270, U$325, U$347, U$402, U$424: A40
U$28, U$60, U$95, U$117, U$172, U$194, U$249, U$271, U$326, U$348, U$403, U$425: A50
U$29, U$61, U$96, U$118, U$173, U$195, U$250, U$272, U$327, U$349, U$404, U$426: SCK0
U$30, U$62, U$97, U$119, U$174, U$196, U$251, U$273, U$328, U$350, U$405, U$427: PICO0
U$31, U$63, U$98, U$120, U$175, U$197, U$252, U$274, U$329, U$351, U$406, U$428: POCI0
U$32, U$64, U$99, U$121, U$176, U$198, U$253, U$275, U$330, U$352, U$407, U$429: RX0
U$33, U$65, U$100, U$122, U$177, U$199, U$254, U$276, U$331, U$353, U$408, U$430: TX0
U$34, U$43, U$139, U$146, U$216, U$223, U$293, U$300, U$370, U$377, U$447, U$454: 60
U$35, U$67, U$101, U$123, U$178, U$200, U$255, U$277, U$332, U$354, U$409, U$431: SDA0
U$36, U$68, U$102, U$124, U$179, U$201, U$256, U$278, U$333, U$355, U$410, U$432: SCL0
U$37, U$48, U$140, U$147, U$217, U$224, U$294, U$301, U$371, U$378, U$448, U$455: 50
U$38, U$66, U$141, U$148, U$218, U$225, U$295, U$302, U$372, U$379, U$449, U$456: 40
U$39, U$69, U$142, U$149, U$219, U$226, U$296, U$303, U$373, U$380, U$450, U$457: 30
U$40, U$70, U$143, U$150, U$220, U$227, U$297, U$304, U$374, U$381, U$451, U$458: 20
U$41, U$144, U$221, U$298, U$375, U$452: 10
U$42, U$145, U$222, U$299, U$376, U$453: 00
U$44, U$103, U$180, U$257, U$334, U$411: VU0
U$45, U$104, U$181, U$258, U$335, U$412: EN0
U$46, U$105, U$182, U$259, U$336, U$413: VBAT0
U$47, U$106, U$183, U$260, U$337, U$414: #PWR#0
U$49, U$107, U$184, U$261, U$338, U$415: #BAT#0
U$50, U$108, U$185, U$262, U$339, U$416: #SHLD#0
U$52, U$110, U$187, U$264, U$341, U$418: #_3V3#0
U$53, U$154, U$231, U$308, U$385, U$462: #_VR#0
U$54, U$111, U$188, U$265, U$342, U$419: #_GND#0
U$55, U$112, U$189, U$266, U$343, U$420: #_A0#0
U$56, U$113, U$190, U$267, U$344, U$421: #_A1#0
U$57, U$114, U$191, U$268, U$345, U$422: #_A2#0
U$58, U$115, U$192, U$269, U$346, U$423: #_A3#0
U$71, U$151, U$228, U$305, U$382, U$459: #1#0
U$72, U$152, U$229, U$306, U$383, U$460: #0#0
U$73, U$153, U$230, U$307, U$384, U$461: #USRBTN#0
U$76, U$125, U$202, U$279, U$356, U$433: #VUSB#0
U$77, U$126, U$203, U$280, U$357, U$434: #EN_#0
U$78, U$127, U$204, U$281, U$358, U$435: #VBAT_#0
U$79, U$82, U$129, U$132, U$206, U$209, U$283, U$286, U$360, U$363, U$437, U$440: RA6M50
U$81, U$135, U$212, U$289, U$366, U$443: #0
U$83, U$133, U$210, U$287, U$364, U$441: THING0
U$84, U$134, U$211, U$288, U$365, U$442: PLUS0
U$85, U$136, U$213, U$290, U$367, U$444: _#0
Y1, Y4, Y6, Y8, Y10, Y12: 24.000MHz; 4-SMD,32X25
Y2, Y3, Y5, Y7, Y9, Y11: 32.768kHz; CRYSTAL-SMD-3.2X1.5MM

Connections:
3.3V: BAT.1, C2.1, C3.1, C4.1, C5.1, C6.1, C16.1, C21.1, C22.2, C23.2, C24.1, D4.VCC, D6.A, FB1.1, I2C.2, J2.27, J3.2, J4.1, J5.1, Q1.2, Q2.2, R8.2, R14.2, R16.1, RN1.10, RN1.11, RN3.1, RN3.2, RN3.3, RN4.1, RN5.15, RN5.16, U1.15, U1.29, U1.46, U1.62, U1.82, U2.7, U4.5, U5.8
3.3V1: BAT1.1, C33.1, C34.1, C35.1, C36.1, C37.1, C44.1, C46.1, C47.2, C48.2, C49.1, D8.A, D9.VCC, FB3.1, I2C1.2, J8.27, J11.2, J13.1, J14.1, Q3.2, Q4.2, R30.2, R31.2, R32.1, RN2.1, RN6.10, RN6.11, RN7.15, RN7.16, RN8.1, RN8.2, RN8.3, U9.5, U12.7, U13.8, U14.15, U14.29, U14.46, U14.62, U14.82
3.3V2: BAT2.1, C60.1, C61.1, C62.1, C63.1, C64.1, C71.1, C73.1, C74.2, C75.2, C76.1, D13.A, D14.VCC, FB5.1, I2C2.2, J15.27, J18.2, J20.1, J21.1, Q5.2, Q6.2, R46.2, R47.2, R48.1, RN9.1, RN10.10, RN10.11, RN11.15, RN11.16, RN12.1, RN12.2, RN12.3, U17.5, U20.7, U21.8, U22.15, U22.29, U22.46, U22.62, U22.82
3.3V3: BAT3.1, C87.1, C88.1, C89.1, C90.1, C91.1, C98.1, C100.1, C101.2, C102.2, C103.1, D18.A, D19.VCC, FB7.1, I2C3.2, J22.27, J25.2, J27.1, J28.1, Q7.2, Q8.2, R62.2, R63.2, R64.1, RN13.1, RN14.10, RN14.11, RN15.15, RN15.16, RN16.1, RN16.2, RN16.3, U25.5, U28.7, U29.8, U30.15, U30.29, U30.46, U30.62, U30.82
3.3V4: BAT4.1, C114.1, C115.1, C116.1, C117.1, C118.1, C125.1, C127.1, C128.2, C129.2, C130.1, D23.A, D24.VCC, FB9.1, I2C4.2, J29.27, J32.2, J34.1, J35.1, Q9.2, Q10.2, R78.2, R79.2, R80.1, RN17.1, RN18.10, RN18.11, RN19.15, RN19.16, RN20.1, RN20.2, RN20.3, U33.5, U36.7, U37.8, U38.15, U38.29, U38.46, U38.62, U38.82
3.3V5: BAT5.1, C141.1, C142.1, C143.1, C144.1, C145.1, C152.1, C154.1, C155.2, C156.2, C157.1, D28.A, D29.VCC, FB11.1, I2C5.2, J36.27, J39.2, J41.1, J42.1, Q11.2, Q12.2, R94.2, R95.2, R96.1, RN21.1, RN22.10, RN22.11, RN23.15, RN23.16, RN24.1, RN24.2, RN24.3, U41.5, U44.7, U45.8, U46.15, U46.29, U46.46, U46.62, U46.82
3.3V_SW: C28.2, J7.4, Q1.3
3.3V_SW1: C53.2, J12.4, Q4.3
3.3V_SW2: C80.2, J19.4, Q6.3
3.3V_SW3: C107.2, J26.4, Q8.3
3.3V_SW4: C134.2, J33.4, Q10.3
3.3V_SW5: C161.2, J40.4, Q12.3
!CTS_RA6/RTS_DA14531!: TP7.1, U1.47, U2.13
!CTS_RA6/RTS_DA14531!1: TP17.1, U12.13, U14.47
!CTS_RA6/RTS_DA14531!2: TP27.1, U20.13, U22.47
!CTS_RA6/RTS_DA14531!3: TP37.1, U28.13, U30.47
!CTS_RA6/RTS_DA14531!4: TP47.1, U36.13, U38.47
!CTS_RA6/RTS_DA14531!5: TP57.1, U44.13, U46.47
!DA14531_RST!: J5.6, R13.1, R16.2, U1.58
!DA14531_RST!1: J14.6, R28.1, R32.2, U14.58
!DA14531_RST!2: J21.6, R44.1, R48.2, U22.58
!DA14531_RST!3: J28.6, R60.1, R64.2, U30.58
!DA14531_RST!4: J35.6, R76.1, R80.2, U38.58
!DA14531_RST!5: J42.6, R92.1, R96.2, U46.58
!FG_ALRT!: RN5.1, U1.100, U7.5
!FG_ALRT!1: RN7.1, U11.5, U14.100
!FG_ALRT!2: RN11.1, U19.5, U22.100
!FG_ALRT!3: RN15.1, U27.5, U30.100
!FG_ALRT!4: RN19.1, U35.5, U38.100
!FG_ALRT!5: RN23.1, U43.5, U46.100
!NMI!: RN4.16, TP9.1, U1.40
!NMI!1: RN2.16, TP19.1, U14.40
!NMI!2: RN9.16, TP29.1, U22.40
!NMI!3: RN13.16, TP39.1, U30.40
!NMI!4: RN17.16, TP49.1, U38.40
!NMI!5: RN21.16, TP59.1, U46.40
!QCS!: RN1.7, U1.77, U5.1
!QCS!1: RN6.7, U13.1, U14.77
!QCS!2: RN10.7, U21.1, U22.77
!QCS!3: RN14.7, U29.1, U30.77
!QCS!4: RN18.7, U37.1, U38.77
!QCS!5: RN22.7, U45.1, U46.77
!RA6M5_RESET!: J2.28, J4.6, R14.1, S2.3, S2.4, U1.38, U2.8
!RA6M5_RESET!1: J8.28, J13.6, R31.1, S3.3, S3.4, U12.8, U14.38
!RA6M5_RESET!2: J15.28, J20.6, R47.1, S5.3, S5.4, U20.8, U22.38
!RA6M5_RESET!3: J22.28, J27.6, R63.1, S7.3, S7.4, U28.8, U30.38
!RA6M5_RESET!4: J29.28, J34.6, R79.1, S9.3, S9.4, U36.8, U38.38
!RA6M5_RESET!5: J36.28, J41.6, R95.1, S11.3, S11.4, U44.8, U46.38
!RTS_RA6/CTS_DA14531!: TP8.1, U1.49, U2.16
!RTS_RA6/CTS_DA14531!1: TP18.1, U12.16, U14.49
!RTS_RA6/CTS_DA14531!2: TP28.1, U20.16, U22.49
!RTS_RA6/CTS_DA14531!3: TP38.1, U28.16, U30.49
!RTS_RA6/CTS_DA14531!4: TP48.1, U36.16, U38.49
!RTS_RA6/CTS_DA14531!5: TP58.1, U44.16, U46.49
!SD_EN!: R15.1, RN3.16, U1.16
!SD_EN!1: R29.1, RN8.16, U14.16
!SD_EN!2: R45.1, RN12.16, U22.16
!SD_EN!3: R61.1, RN16.16, U30.16
!SD_EN!4: R77.1, RN20.16, U38.16
!SD_EN!5: R93.1, RN24.16, U46.16
!USR_BTN!: RN3.15, S1.1, S1.2, U1.17
!USR_BTN!1: RN8.15, S4.1, S4.2, U14.17
!USR_BTN!2: RN12.15, S6.1, S6.2, U22.17
!USR_BTN!3: RN16.15, S8.1, S8.2, U30.17
!USR_BTN!4: RN20.15, S10.1, S10.2, U38.17
!USR_BTN!5: RN24.15, S12.1, S12.2, U46.17
A0/DAC0/D1: J8.24, U14.85
A0/DAC0/D2: J15.24, U22.85
A0/DAC0/D3: J22.24, U30.85
A0/DAC0/D4: J29.24, U38.85
A0/DAC0/D5: J36.24, U46.85
A0/DAC0/D7: J2.24, U1.85
A1/DAC1/D1: J8.23, U14.84
A1/DAC1/D2: J15.23, U22.84
A1/DAC1/D3: J22.23, U30.84
A1/DAC1/D4: J29.23, U38.84
A1/DAC1/D5: J36.23, U46.84
A1/DAC1/D8: J2.23, U1.84
A2/D1: J8.22, U14.81
A2/D2: J15.22, U22.81
A2/D3: J22.22, U30.81
A2/D4: J29.22, U38.81
A2/D5: J36.22, U46.81
A2/D9: J2.22, U1.81
A3/D1: J8.21, U14.80
A3/D2: J15.21, U22.80
A3/D3: J22.21, U30.80
A3/D4: J29.21, U38.80
A3/D5: J36.21, U46.80
A3/D10: J2.21, U1.80
A4/D1: J8.20, U14.79
A4/D2: J15.20, U22.79
A4/D3: J22.20, U30.79
A4/D4: J29.20, U38.79
A4/D5: J36.20, U46.79
A4/D11: J2.20, U1.79
A5/D1: J8.19, U14.78
A5/D2: J15.19, U22.78
A5/D3: J22.19, U30.78
A5/D4: J29.19, U38.78
A5/D5: J36.19, U46.78
A5/D12: J2.19, U1.78
AGND: C25.2, C26.2, C27.2, C29.2, SUPPLYTIE1.P$1, U1.86, U1.89, U1.90
AGND1: C50.2, C51.2, C52.2, C54.2, SUPPLYTIE6.P$1, U14.86, U14.89, U14.90
AGND2: C77.2, C78.2, C79.2, C81.2, SUPPLYTIE9.P$1, U22.86, U22.89, U22.90
AGND3: C104.2, C105.2, C106.2, C108.2, SUPPLYTIE12.P$1, U30.86, U30.89, U30.90
AGND4: C131.2, C132.2, C133.2, C135.2, SUPPLYTIE15.P$1, U38.86, U38.89, U38.90
AGND5: C158.2, C159.2, C160.2, C162.2, SUPPLYTIE18.P$1, U46.86, U46.89, U46.90
AVCC0: C25.1, C29.1, FB1.2, TP4.1, U1.88
AVCC1: C50.1, C54.1, FB3.2, TP14.1, U14.88
AVCC2: C77.1, C81.1, FB5.2, TP24.1, U22.88
AVCC3: C104.1, C108.1, FB7.2, TP34.1, U30.88
AVCC4: C131.1, C135.1, FB9.2, TP44.1, U38.88
AVCC5: C158.1, C162.1, FB11.2, TP54.1, U46.88
BAT_SW: RN5.2, U1.99, U8.8
BAT_SW1: RN7.2, U14.99, U16.8
BAT_SW2: RN11.2, U22.99, U24.8
BAT_SW3: RN15.2, U30.99, U32.8
BAT_SW4: RN19.2, U38.99, U40.8
BAT_SW5: RN23.2, U46.99, U48.8
BLE_RST: Q2.3, TP3.1, U2.12
BLE_RST1: Q3.3, TP13.1, U12.12
BLE_RST2: Q5.3, TP23.1, U20.12
BLE_RST3: Q7.3, TP33.1, U28.12
BLE_RST4: Q9.3, TP43.1, U36.12
BLE_RST5: Q11.3, TP53.1, U44.12
BOOT/MD: R8.1, TP10.1, U1.39, U2.15
BOOT/MD1: R30.1, TP20.1, U12.15, U14.39
BOOT/MD2: R46.1, TP30.1, U20.15, U22.39
BOOT/MD3: R62.1, TP40.1, U28.15, U30.39
BOOT/MD4: R78.1, TP50.1, U36.15, U38.39
BOOT/MD5: R94.1, TP60.1, U44.15, U46.39
DA14531_SWCLK: J5.3, U2.10
DA14531_SWCLK1: J14.3, U12.10
DA14531_SWCLK2: J21.3, U20.10
DA14531_SWCLK3: J28.3, U28.10
DA14531_SWCLK4: J35.3, U36.10
DA14531_SWCLK5: J42.3, U44.10
DA14531_SWDIO: J5.2, U2.9
DA14531_SWDIO1: J14.2, U12.9
DA14531_SWDIO2: J21.2, U20.9
DA14531_SWDIO3: J28.2, U28.9
DA14531_SWDIO4: J35.2, U36.9
DA14531_SWDIO5: J42.2, U44.9
EXTAL: U1.14, Y1.1
EXTAL1: U14.14, Y4.1
EXTAL2: U22.14, Y6.1
EXTAL3: U30.14, Y8.1
EXTAL4: U38.14, Y10.1
EXTAL5: U46.14, Y12.1
FREE/D1: J8.13, U14.44
FREE/D2: J15.13, U22.44
FREE/D3: J22.13, U30.44
FREE/D4: J29.13, U38.44
FREE/D5: J36.13, U46.44
FREE/D30: J2.13, U1.44
GND: C1.1, C2.2, C3.2, C4.2, C5.2, C6.2, C11.2, C12.2, C13.2, C14.2, C15.2, C16.2, C17.2, C18.1, C19.2, C20.2, C21.2, C22.1, C23.1, C24.2, C28.1, D1.2, D4.GND, J1.GND, J1.GND2, J2.25, J3.1, J4.5, J5.5, J6.1, J7.6, J7.GND1, J7.GND2, J7.GND3, J7.GND4, J7.GND5, J7.GND6, JP4.1, R2.1, R3.1, R4.1, R5.1, R11.1, RN1.1, RN1.2, RN1.3, RN1.4, RN1.5, RN1.8, RN3.4, RN3.5, RN3.6, RN3.8, RN4.2, RN4.3, RN4.4, RN4.5, RN4.6, RN4.7, RN4.8, RN4.9, RN5.9, RN5.10, RN5.11, RN5.12, RN5.13, RN5.14, S1.3, S1.4, S2.1, S2.2, SHLD.1, SUPPLYTIE1.P$2, SUPPLYTIE2.P$2, SUPPLYTIE3.P$1, U1.12, U1.26, U1.45, U1.63, U1.83, U2.1, U2.2, U2.3, U2.4, U2.6, U2.11, U3.2, U4.2, U5.4, U6.2, U7.1, U7.4, U7.6, U7.9, U8.1, U8.4, U8.5
GND1: C7.2, C8.2, C30.1, C33.2, C34.2, C35.2, C36.2, C37.2, C38.2, C39.2, C40.2, C41.2, C42.1, C43.2, C44.2, C45.2, C46.2, C47.1, C48.1, C49.2, C53.1, D3.2, D9.GND, J8.25, J9.GND, J9.GND2, J10.1, J11.1, J12.6, J12.GND1, J12.GND2, J12.GND3, J12.GND4, J12.GND5, J12.GND6, J13.5, J14.5, JP1.1, R18.1, R19.1, R20.1, R24.1, R26.1, RN2.2, RN2.3, RN2.4, RN2.5, RN2.6, RN2.7, RN2.8, RN2.9, RN6.1, RN6.2, RN6.3, RN6.4, RN6.5, RN6.8, RN7.9, RN7.10, RN7.11, RN7.12, RN7.13, RN7.14, RN8.4, RN8.5, RN8.6, RN8.8, S3.1, S3.2, S4.3, S4.4, SHLD1.1, SUPPLYTIE4.P$1, SUPPLYTIE5.P$2, SUPPLYTIE6.P$2, U9.2, U10.2, U11.1, U11.4, U11.6, U11.9, U12.1, U12.2, U12.3, U12.4, U12.6, U12.11, U13.4, U14.12, U14.26, U14.45, U14.63, U14.83, U15.2, U16.1, U16.4, U16.5
GND2: C55.2, C56.2, C57.1, C60.2, C61.2, C62.2, C63.2, C64.2, C65.2, C66.2, C67.2, C68.2, C69.1, C70.2, C71.2, C72.2, C73.2, C74.1, C75.1, C76.2, C80.1, D11.2, D14.GND, J15.25, J16.GND, J16.GND2, J17.1, J18.1, J19.6, J19.GND1, J19.GND2, J19.GND3, J19.GND4, J19.GND5, J19.GND6, J20.5, J21.5, JP2.1, R34.1, R35.1, R36.1, R40.1, R42.1, RN9.2, RN9.3, RN9.4, RN9.5, RN9.6, RN9.7, RN9.8, RN9.9, RN10.1, RN10.2, RN10.3, RN10.4, RN10.5, RN10.8, RN11.9, RN11.10, RN11.11, RN11.12, RN11.13, RN11.14, RN12.4, RN12.5, RN12.6, RN12.8, S5.1, S5.2, S6.3, S6.4, SHLD2.1, SUPPLYTIE7.P$1, SUPPLYTIE8.P$2, SUPPLYTIE9.P$2, U17.2, U18.2, U19.1, U19.4, U19.6, U19.9, U20.1, U20.2, U20.3, U20.4, U20.6, U20.11, U21.4, U22.12, U22.26, U22.45, U22.63, U22.83, U23.2, U24.1, U24.4, U24.5
GND3: C82.2, C83.2, C84.1, C87.2, C88.2, C89.2, C90.2, C91.2, C92.2, C93.2, C94.2, C95.2, C96.1, C97.2, C98.2, C99.2, C100.2, C101.1, C102.1, C103.2, C107.1, D16.2, D19.GND, J22.25, J23.GND, J23.GND2, J24.1, J25.1, J26.6, J26.GND1, J26.GND2, J26.GND3, J26.GND4, J26.GND5, J26.GND6, J27.5, J28.5, JP3.1, R50.1, R51.1, R52.1, R56.1, R58.1, RN13.2, RN13.3, RN13.4, RN13.5, RN13.6, RN13.7, RN13.8, RN13.9, RN14.1, RN14.2, RN14.3, RN14.4, RN14.5, RN14.8, RN15.9, RN15.10, RN15.11, RN15.12, RN15.13, RN15.14, RN16.4, RN16.5, RN16.6, RN16.8, S7.1, S7.2, S8.3, S8.4, SHLD3.1, SUPPLYTIE10.P$1, SUPPLYTIE11.P$2, SUPPLYTIE12.P$2, U25.2, U26.2, U27.1, U27.4, U27.6, U27.9, U28.1, U28.2, U28.3, U28.4, U28.6, U28.11, U29.4, U30.12, U30.26, U30.45, U30.63, U30.83, U31.2, U32.1, U32.4, U32.5
GND4: C109.2, C110.2, C111.1, C114.2, C115.2, C116.2, C117.2, C118.2, C119.2, C120.2, C121.2, C122.2, C123.1, C124.2, C125.2, C126.2, C127.2, C128.1, C129.1, C130.2, C134.1, D21.2, D24.GND, J29.25, J30.GND, J30.GND2, J31.1, J32.1, J33.6, J33.GND1, J33.GND2, J33.GND3, J33.GND4, J33.GND5, J33.GND6, J34.5, J35.5, JP5.1, R66.1, R67.1, R68.1, R72.1, R74.1, RN17.2, RN17.3, RN17.4, RN17.5, RN17.6, RN17.7, RN17.8, RN17.9, RN18.1, RN18.2, RN18.3, RN18.4, RN18.5, RN18.8, RN19.9, RN19.10, RN19.11, RN19.12, RN19.13, RN19.14, RN20.4, RN20.5, RN20.6, RN20.8, S9.1, S9.2, S10.3, S10.4, SHLD4.1, SUPPLYTIE13.P$1, SUPPLYTIE14.P$2, SUPPLYTIE15.P$2, U33.2, U34.2, U35.1, U35.4, U35.6, U35.9, U36.1, U36.2, U36.3, U36.4, U36.6, U36.11, U37.4, U38.12, U38.26, U38.45, U38.63, U38.83, U39.2, U40.1, U40.4, U40.5
GND5: C136.2, C137.2, C138.1, C141.2, C142.2, C143.2, C144.2, C145.2, C146.2, C147.2, C148.2, C149.2, C150.1, C151.2, C152.2, C153.2, C154.2, C155.1, C156.1, C157.2, C161.1, D26.2, D29.GND, J36.25, J37.GND, J37.GND2, J38.1, J39.1, J40.6, J40.GND1, J40.GND2, J40.GND3, J40.GND4, J40.GND5, J40.GND6, J41.5, J42.5, JP6.1, R82.1, R83.1, R84.1, R88.1, R90.1, RN21.2, RN21.3, RN21.4, RN21.5, RN21.6, RN21.7, RN21.8, RN21.9, RN22.1, RN22.2, RN22.3, RN22.4, RN22.5, RN22.8, RN23.9, RN23.10, RN23.11, RN23.12, RN23.13, RN23.14, RN24.4, RN24.5, RN24.6, RN24.8, S11.1, S11.2, S12.3, S12.4, SHLD5.1, SUPPLYTIE16.P$1, SUPPLYTIE17.P$2, SUPPLYTIE18.P$2, U41.2, U42.2, U43.1, U43.4, U43.6, U43.9, U44.1, U44.2, U44.3, U44.4, U44.6, U44.11, U45.4, U46.12, U46.26, U46.45, U46.63, U46.83, U47.2, U48.1, U48.4, U48.5
GND_7: C31.1, C32.1, SUPPLYTIE5.P$1
GND_15: C58.1, C59.1, SUPPLYTIE8.P$1
GND_23: C85.1, C86.1, SUPPLYTIE11.P$1
GND_32: C9.1, C10.1, SUPPLYTIE2.P$1
GND_33: C112.1, C113.1, SUPPLYTIE14.P$1
GND_41: C139.1, C140.1, SUPPLYTIE17.P$1
GPIO0/!CS!/D0: J2.9, U1.55
GPIO0/!CS!/D1: J8.9, U14.55
GPIO0/!CS!/D2: J15.9, U22.55
GPIO0/!CS!/D3: J22.9, U30.55
GPIO0/!CS!/D4: J29.9, U38.55
GPIO0/!CS!/D5: J36.9, U46.55
GPIO1/D1: J2.8, U1.7
GPIO1/D2: J8.8, U14.7
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

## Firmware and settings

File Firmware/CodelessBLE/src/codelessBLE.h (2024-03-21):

#pragma once

#include <Arduino.h>
#include <cstdint>
#include <stdint.h>

// Uncomment if you want to enable debug messages
// #define CODELESS_DBG

#define DEFAULT_CODELESS_BAUD_RATE 57600
#define DEFAULT_TIMEOUT_IN_S 2

/**
 * @brief The CodelessStatus enum represents the status of the CodelessBase class.
 */
typedef enum
{
    CODELESS_OK,
    CODELESS_ERROR
} CodelessStatus;

/**
 * @brief The CodelessAddrType enum represents the address type used by CodelessBase class.
 */
typedef enum
{
    PUBLIC,
    RANDOM
} CodelessAddrType;

/**
 * @brief The CodelessBase class provides a base implementation for Codeless communication.
 */
class CodelessBase
{
public:
    /**
     * @brief Constructs a CodelessBase object.
     * @param serial The UART object to use for communication.
     */
    CodelessBase(UART& serial = Serial2) : _serialPort{&serial},
                                            _connected{false},
                                            _reply_received{false},
                                            _status{CODELESS_ERROR},
                                            _reply_string{""}
    {
    }

    /**
     * @brief Initializes the CodelessBase object.
     * @param baudRate The baud rate for the serial communication. Default is DEFAULT_CODELESS_BAUD_RATE.
     * @param config The configuration for the serial communication. Default is SERIAL_8N1.
     * @return True if initialization is successful, false otherwise.
     */
    virtual bool begin(uint32_t baudRate = DEFAULT_CODELESS_BAUD_RATE, uint16_t config = SERIAL_8N1);

    /**
     * @brief Deinitializes the CodelessBase object.
     */
    virtual void end(void);

    /**
     * @brief Sends a command to the Codeless device and waits for the response.
     * @param cmd The command to send.
     * @param timeout_in_s The timeout duration in seconds. Default is DEFAULT_TIMEOUT_IN_S.
     * @return The response string from the Codeless device.
     */
    virtual String sendCommand(const String& cmd, const uint16_t timeout_in_s = DEFAULT_TIMEOUT_IN_S);

    /**
     * @brief Reads the output from the Codeless device.
     * @return The output string from the Codeless device.
     */
    virtual String readOutput(void);

    /**
     * @brief Checks if the Codeless device is connected.
     * @return True if the device is connected, false otherwise.
     */
    bool connected(void);

    /**
     * @brief Checks the number of bytes available to read from the Codeless device.
     * @return The number of bytes available to read.
     */
    int available(void);

    /**
     * @brief Resets the Codeless device.
     */
    void reset(void);

    /**
     * @brief Sets up the Codeless device with default settings.
     * @return True if setup is successful, false otherwise.
     */
    virtual bool setupDefault(void);

protected:
    bool _connected;
    bool _reply_received;
    CodelessStatus _status;
    
    String _reply_string;

    UART* _serialPort;
};

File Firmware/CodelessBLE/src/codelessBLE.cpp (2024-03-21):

#include "codelessBLE.h"

bool CodelessBase::begin(uint32_t baudRate, uint16_t config)
{
    #ifdef CODELESS_DBG
    Serial.println("[DBG] - Begin begin().");
    #endif
    _serialPort->begin(baudRate, config);

    if(!_serialPort)
    {
        #ifdef CODELESS_DBG
        Serial.println("Could not start serial port.");
        #endif
        _status = CODELESS_ERROR;
        _connected = false;
        return false;
    }

    _status = CODELESS_OK;
    _connected = true;
    
    return true;
}

void CodelessBase::end(void)
{
    #ifdef CODELESS_DBG
    Serial.println("[DBG] - Begin end().");
    #endif
    _serialPort->end();
    _connected = false;
}

String CodelessBase::sendCommand(const String& cmd, const uint16_t timeout_in_s)
{
    #ifdef CODELESS_DBG
    Serial.println("[DBG] - Begin sendCommand().");
    Serial.print("[DBG] - Sending: ");
    Serial.println(cmd);
    #endif

    if(!_serialPort)
    {
        #ifdef CODELESS_DBG
        Serial.println("[DBG] - serial is null! What did you do?!");
        #endif
        return ((String)"");
    }

    uint32_t start_time = millis();
    uint32_t elapsed_time = 0;
    bool reply_expected = true;
    String cmdToWrite = "";

    _reply_string = "";
    _status = CODELESS_ERROR;

    if(!_connected)
    {
        #ifdef CODELESS_DBG
        Serial.println("[DBG] - Not connected. Returning.");
        #endif
        return _reply_string;
    }

    // Check if the command is a serial passthrough string
    if(cmd.startsWith("|"))
    {
        #ifdef CODELESS_DBG
        Serial.println("[DBG] - starts with | - Setting reply_expected to false.");
        #endif
        reply_expected = false;
    }
    if(cmd.endsWith("\r"))
    {
        cmdToWrite = cmd;
    }
    else
    {
        cmdToWrite = cmd+"\r";
    }
    _serialPort->print(cmdToWrite);
    delayMicroseconds(100);
    if(!reply_expected)
    {
        _status = CODELESS_OK;
        return _reply_string;
    }
    
    _reply_received = false;

    while(!_reply_received)
    {
        if(_serialPort->available())
        {
            _reply_string+=_serialPort->readString();
            elapsed_time = millis() - start_time;
            if(elapsed_time > timeout_in_s*1000)
            {
                #ifdef CODELESS_DBG
                Serial.println("[DBG] - sendCommand - while - Timeout occurred.");
                Serial.print("[DBG] - sendCommand - while - _reply_string: ");
                Serial.println(_reply_string);
                #endif
                _status = CODELESS_ERROR;
                return _reply_string;
            }
        }
        if(_reply_string.endsWith("OK\r\n") || _reply_string.endsWith("ERROR\r\n") || _reply_string.endsWith("+READY\r\n"))
        {
            _reply_received = true;
        }
        else
        {
            delayMicroseconds(100);
            elapsed_time = millis() - start_time;
            if(elapsed_time > timeout_in_s*1000 )
            {
                #ifdef CODELESS_DBG
                Serial.println("[DBG] - sendCommand - else - Timeout occurred.");
                Serial.print("[DBG] - sendCommand - else - _reply_string: ");
                Serial.println(_reply_string);
                #endif
                _status = CODELESS_ERROR;
                return _reply_string;
            }
        }
    }
    _status = CODELESS_OK;

    return _reply_string;
}

String CodelessBase::readOutput(void)
{
    _reply_string = "";
    _status = CODELESS_ERROR;

    if(_connected)
    {
        _reply_string = _serialPort->readString();
        _status = CODELESS_OK;
    }

    return _reply_string;
}

bool CodelessBase::connected(void)
{
    if(!_serialPort)
    {
        #ifdef CODELESS_DBG
        Serial.println("[DBG] - connected() - serial is null! What did you do?!");
        #endif
        return false;
    }
    return _connected;
}

int CodelessBase::available(void) 
{   
    if(!_serialPort)
    {
        #ifdef CODELESS_DBG
        Serial.println("[DBG] - available() - serial is null! What did you do?!");
        #endif
        return 0;
    }
    return _serialPort->available(); 
}

bool CodelessBase::setupDefault(void)
{
    reset();
    sendCommand("AT+ADVSTOP");

    return true;
}

void CodelessBase::reset(void)
{
    #ifdef CODELESS_DBG
    Serial.println("[DBG] - Begin reset().");
    Serial.print(sendCommand("ATR"));
    #else
    sendCommand("ATR");
    #endif
}

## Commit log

2023-11-07 Schematic complete.
    Board mostly has components laid out.
    [SparkFun_Thing_Plus_RA6M5.brd, SparkFun_Thing_Plus_RA6M5.sch]
2023-11-07 Update Test Points, ready for v01 schematic review
    [SparkFun_Thing_Plus_RA6M5.brd, SparkFun_Thing_Plus_RA6M5.sch]
2023-11-07 Add documentation, update xtal caps.
    [SparkFun_Thing_Plus_RA6M5.brd, SparkFun_Thing_Plus_RA6M5.sch]
2023-11-08 test 6L
    [SparkFun_Thing_Plus_RA6M5.brd]
2023-11-08 Made board 6L and created 6L Isolated USB
    [SparkFun_Thing_Plus_RA6M5.brd, SparkFun_Thing_Plus_RA6M5.sch]
2023-11-08 Added LM66200 and incorporated it.
    [SparkFun_Thing_Plus_RA6M5.brd, SparkFun_Thing_Plus_RA6M5.sch]
2023-11-10 update based on pre-design review comments.
    [SparkFun_Thing_Plus_RA6M5.brd, SparkFun_Thing_Plus_RA6M5.sch]
2023-12-07 Update Sch, Lbr, & Brd files.
    Add broken out resistors for boot/reset pins.
    Move array resistors around to make them route easier.
    Add BAT jumper.
    Add 1u to AVCC net.
    Move spare array resistor to bottom.
    Pull status pin to 3.3V for LM66200.
    Make RT9080 PUR 1M.
    Replace VREF with another RT9080.
    Rename some nets.
    Remove SD card PURs since they're available internally on the processor.
    Increased the size of some TPs where there was room.
    Routed whole board.
    Changed thickness of some silk on parts.
    Added PROD_IDs to new parts.
    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
    [SparkFun_Thing_Plus_RA6M5.brd, SparkFun_Thing_Plus_RA6M5.sch]
2023-12-07 Add gerbers for v01.
    [SparkFun_Thing_Plus_RA6M5.GBL, SparkFun_Thing_Plus_RA6M5.GBO, SparkFun_Thing_Plus_RA6M5.GBP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]
2023-12-13 Post design review, pre-design review changes.
    [SparkFun_Thing_Plus_RA6M5.brd]
2023-12-15 Update post-design review.
    Add USB diff calcs to schematic.
    Add product name silk to bottom of board.
    Consolidate 0.1u caps.
    Stitch power and ground planes better.
    Analyze PDN to chip and improve.
    Pour 3V3 under USB on top and bot.
    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
    [SparkFun_Thing_Plus_RA6M5.brd, SparkFun_Thing_Plus_RA6M5.sch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]
2023-12-19 Add panel for v01.
    [SparkFun_Thing_Plus_RA6M5-Panel.GBL, SparkFun_Thing_Plus_RA6M5-Panel.GBO, SparkFun_Thing_Plus_RA6M5-Panel.GBP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]
2023-12-19 Move to prod folder
    [SparkFun_Thing_Plus_RA6M5-Panel.GBL, SparkFun_Thing_Plus_RA6M5-Panel.GBO, SparkFun_Thing_Plus_RA6M5-Panel.GBP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]
2023-12-21 Minor update to v01.
    Add Fuel Gauge address text to schematic.
    Add +/- silk for battery connector.
    Re-export PDF.
    [SparkFun_Thing_Plus_RA6M5.brd, SparkFun_Thing_Plus_RA6M5.sch]
2024-02-26 Add Codeless BLE basic wrapper. Add examples, test. Add arduino library files. Add gitignore. Add license.
2024-02-26 Update for Reds.
    Change QSPI flash chip to same one as Portenta C33
    Remove boot button
    Move reset button to space it out
    Add boot test point
    Recenter programming header silk
    Update GPIO silk
    Rename nets in schematic
    Remove BLE Reset jumper
    Remove DNP caps from 24MHz xtal
    [SparkFun_Thing_Plus_RA6M5.brd, SparkFun_Thing_Plus_RA6M5.sch]
2024-02-26 Add 6-board panel files.
    [SparkFun_Thing_Plus_RA6M5-Panel.GBL, SparkFun_Thing_Plus_RA6M5-Panel.GBO, SparkFun_Thing_Plus_RA6M5-Panel.GBP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]
2024-02-29 Add CodelessBLE zip for arduino.
2024-02-29 V10 hardware post reds review update
    Connect fills on bottom side near bottom diamond.
    Add user button near reset button.
    VREF EN now pulls up to 3.3V instead of VIN.
    Change VREF silk bottom side to inverted VA.
    Update EN and !RST! silk flags to use the right arrow.
    Move vias to allow fills.
    Adjust guard trace around Y1 to accommodate removing caps.
    Add ground vias near QSPI data lines where possible.
    [SparkFun_Thing_Plus_RA6M5.brd, SparkFun_Thing_Plus_RA6M5.sch]
2024-02-29 Rename silk
    VA to VR.
    [SparkFun_Thing_Plus_RA6M5.brd]
2024-02-29 Repanelize post reds review.
    [SparkFun_Thing_Plus_RA6M5-Panel.GBL, SparkFun_Thing_Plus_RA6M5-Panel.GBO, SparkFun_Thing_Plus_RA6M5-Panel.GBP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]
2024-03-08 Update LICENSE.md
    Remove carriage returns
    Fix grammar
2024-03-19 Update Codeless Firmware. Update library.properties with correct URL. Add comments and header to examples. Remove unused code in examples. Remove magic numbers in examples and libraries. Comment code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
    [codelessBLE.cpp, codelessBLE.h, codelessBLE_Test.ino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]
2024-03-20 Update SD test to remove SD power control.
2024-04-06 Ported Renesas-Arduino Core
2024-04-09 Fix Copy/Paste
    Remove instances of ESP32 or mosaic-X5 (copy/paste errors)
2024-04-09 Update SFE-Renesas-Arduino_core.zip
    Update Arduino Core for bootloader
2024-04-09 Create CodelessBLE.zip
    Add CodeLess Arduino library
2024-04-12 Update SFE-Renesas-Arduino_core.zip
    Replace linkers in FATFileSystems with required files
2024-04-12 Update documentation
    Update instructions for FastLED library and Arduino core
    Few other corrections
2024-04-12 Update software_overview-arduino.md
    Use snippets
2024-04-12 Add SPI and Serial Examples
2024-04-15 Update documentation
    Adds examples for I2C, SD card, flash memory, and DA14531MOD
2024-04-15 Update graphical_datasheet.pdf
    Fix digital pin labeled for user button
2024-04-15 Update/Add Examples
    Include BME688 for SPI, I2C, and BLE examples
2024-04-28 Update resources.md
    Add QR code for printouts
2024-05-30 Highlight specific board definition
2024-05-30 Update software_overview-arduino.md
    Update instructions in response to: https://github.com/sparkfun/SparkFun_Thing_Plus_RA6M5/issues/5
2024-08-06 Backup old Arduino Core
    Backup of original Arduino Core
2024-08-06 Update SFE-Renesas-Arduino_core.zip
    Add support for C33 variant
2024-08-06 Update software_overview-arduino.md
    Restores default instructions for FastLED library (pull request was merged)

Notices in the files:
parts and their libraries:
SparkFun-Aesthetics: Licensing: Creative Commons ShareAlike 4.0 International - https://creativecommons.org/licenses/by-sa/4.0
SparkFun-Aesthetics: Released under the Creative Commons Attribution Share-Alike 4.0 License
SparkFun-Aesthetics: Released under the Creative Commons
